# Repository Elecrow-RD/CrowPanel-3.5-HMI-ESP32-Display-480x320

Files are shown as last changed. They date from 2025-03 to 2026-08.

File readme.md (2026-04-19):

### 1, Product picture

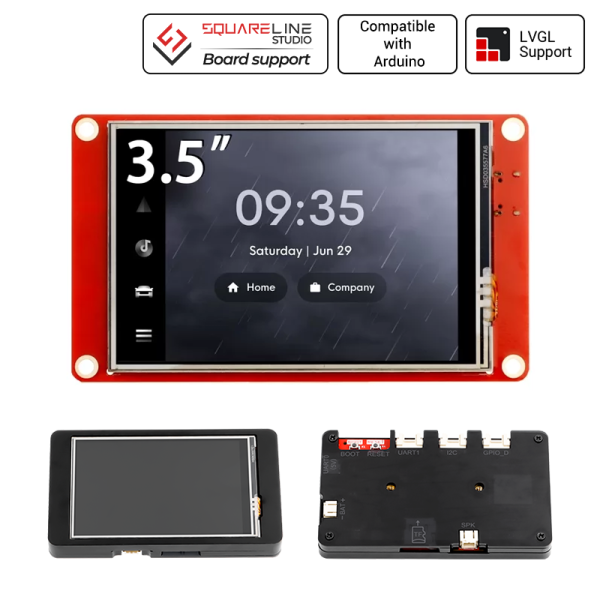
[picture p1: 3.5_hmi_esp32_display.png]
3.5_hmi_esp32_display


### 2, Product version number

| | Hardware | Software | Remark |
| ---- | --- | --- | --- |
| 1 | V1.0 | V1.0 | old |
| 1 | V1.1 | V1.0 | old |
| 1 | V2.0 | V1.0 | old |
| 1 | V2.2 | V2.2 | latest |

**Version 2.0** upgrades the automatic download feature from Version 1.0.

**Version 2.2** modifies two pins based on Version 2.0. The following modifications are required:
#define TFT_MISO 33
#define TOUCH_CS 12

### 3, product informatio

- Model: 3.5 inches module-CrowPanel ESP32 display
- Main Processor: ESP32-WROVER-B
- Resolution: 480*320
- Touch Type: Resistive Touch Screen
- Display Type: TN Panel
- Screen: TFT-LCD Screen
- Display driver: ILI9488
- External power supply: DC5V-2A
- Interface: 1\*TF Card Slot, 1\* I2C, 1* GPIO, 1\*Speak, 1* UART1, 1*UART0
- Button: BOOT Button and Reset Button
- Active Area: 48.96\*73.44mm(W*H)
- Working Temperature: -20℃～70℃
- Storage Temperature: -30℃～80℃

### 4, Use the driver module

| Name | dependency library |
| ---- | --- |
| LVGL | lvgl/lvgl@8.3.3 |

### 5,Quick Start

##### Arduino IDE starts

1.Download the library files used by this product to the 'libraries' folder.

C:\Users\Documents\Arduino\libraries\



2.Open the Arduino IDE

arduino1

3.Open the code configuration environment and burn it

arduino2

##### ESP-IDF starts

1.Right-click on an empty space in the project folder and select "Open with VS Code" to open the project.



2.In the IDF plug-in, select the port, then compile and flash



##### PlatformIO starts

1.Right-click on an empty space in the project folder and select "Open with VS Code" to open the project.



2.In the PlatformIO plug-in, select the port, then compile and flash

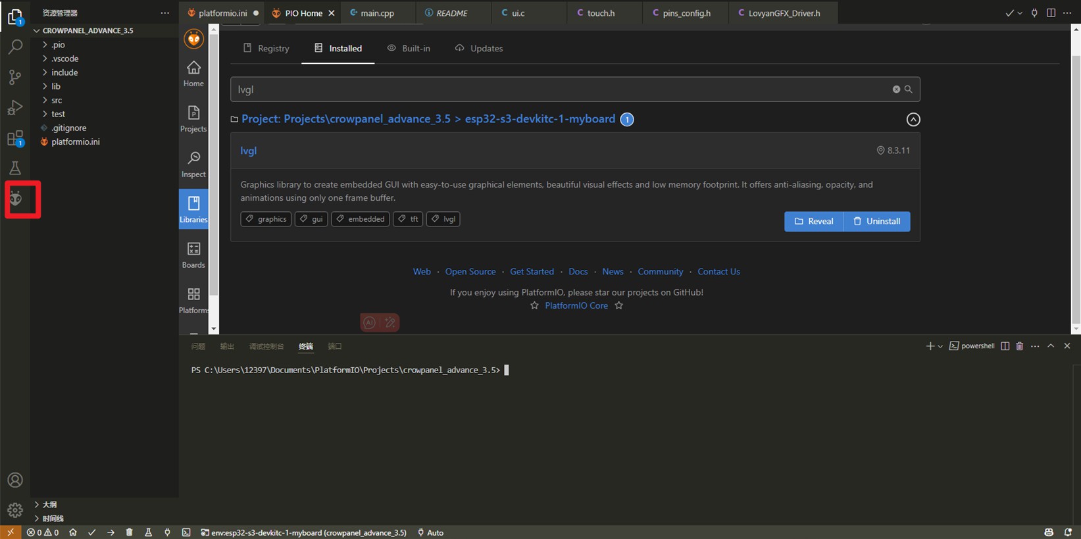
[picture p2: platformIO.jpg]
platformIO


##### Micropython starts

1,Right-click on an empty space in the project folder and select "Thonny" to open the project.

thonny

2,In thonny software, select the master and port, then run the program

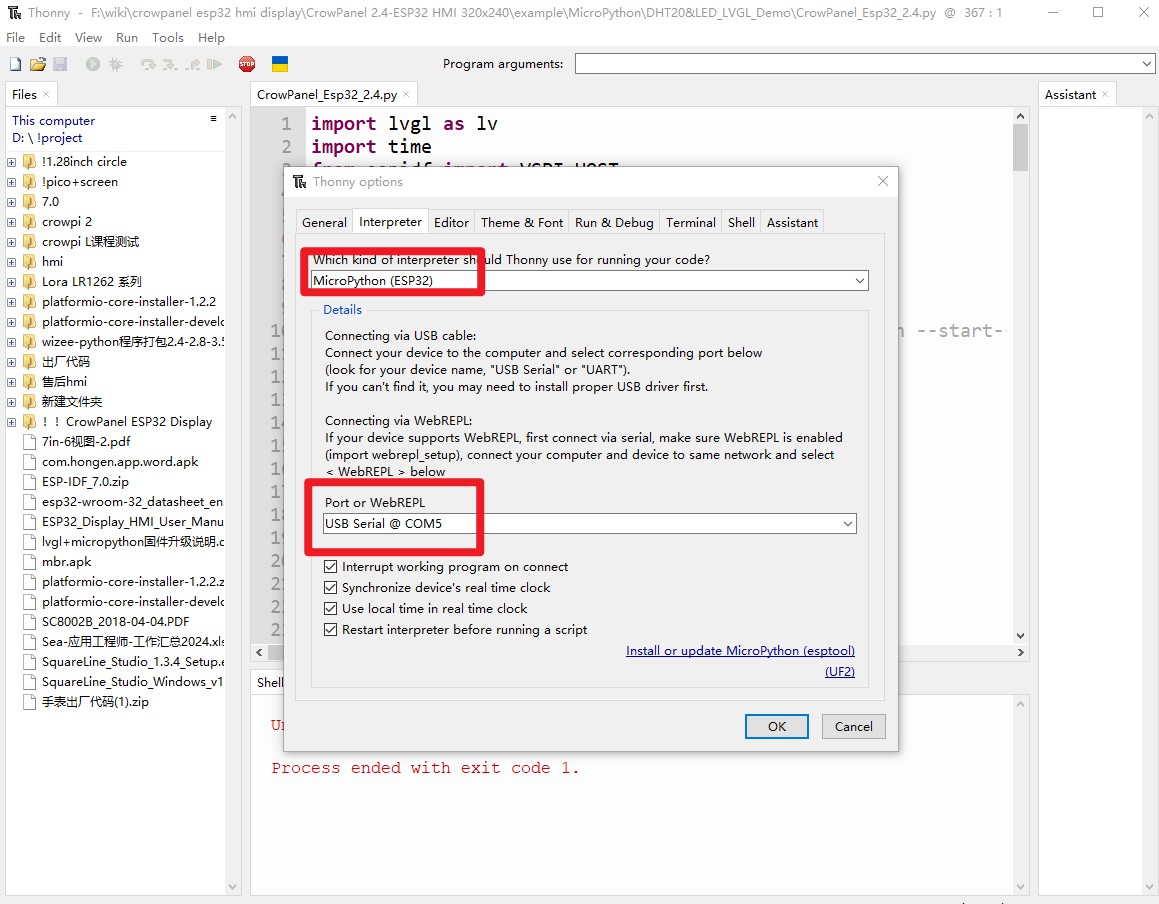
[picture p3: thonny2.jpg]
thonny2


### 6,Folder structure.

|--3D file： Contains 3D model files (.stp) for the hardware. These files can be used for visualization, enclosure design, or integration into CAD software.

|--Datasheet: Includes datasheets for components used in the project, providing detailed specifications, electrical characteristics, and pin configurations.

|--Eagle_SCH&PCB: Contains **Eagle CAD** schematic (`.sch`) and PCB layout (`.brd`) files. These are used for circuit design and PCB manufacturing.

|--example: Provides example code and projects to demonstrate how to use the hardware and libraries. These examples help users get started quickly.

|--factory_firmware: Stores pre-compiled factory firmware that can be directly flashed onto the device. This ensures the device runs the default functionality.

|--factory_sourcecode: Contains the source code for the factory firmware, allowing users to modify and rebuild the firmware as needed.

### 7,Pin definition

\#define TFT_MISO 12 

#define TFT_MOSI 13 // In some display driver board, it might be written as "SDA" and so on. 

#define TFT_SCLK 14 

#define TFT_CS   15  // Chip select control pin 

#define TFT_DC   2  // Data Command control pin 

#define TFT_RST  -1  // Reset pin (could connect to Arduino RESET pin) 

#define TFT_BL   27  // LED back-light 

#define TOUCH_CS 33     // Chip select pin (T_CS) of touch screen

For the latest v2.2 board, the following modifications need to be made:

#define TFT_MISO 33

#define TOUCH_CS 12`

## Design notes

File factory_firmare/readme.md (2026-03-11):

##### Note: For the two firmware files above, if the screen hardware version is 2.2, please use the firmware (LVGL_Arduino3.5RTP-Hor-2.2). For other versions, use (HMI3.5_factory_firmware).

# How to install the factory demo firmware with flash download tool?

#### 1.Preparation:

- USB C cable
- Laptop/PC
- Crowpanel Advance HMI ESP32 AI Display
- Flash download tool

Check whether the materials on the PCBA board are defective. Such as less material, false welding, tin and other bad phenomena.

#### 2.Flash the firmware 

##### Step1 Connect the ESP32 display to the laptop/PC with USB-C cable. The power indicator will light up.

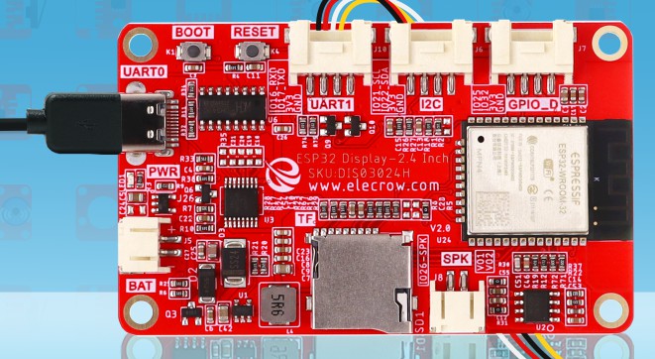
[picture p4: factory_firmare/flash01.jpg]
flash01


##### Step2 Open the flash download tool. 

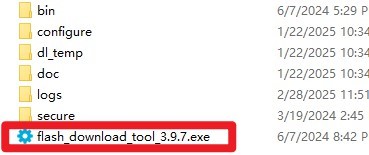
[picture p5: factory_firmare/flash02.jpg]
flash02


For the  Crowpanel 3.5 HMI ESP32 Display, the chip select ESP32:

firmware1

##### Step3

①Choose the firmware files;

flash0

②Enter the address: 

boot_app0.bin------0xe000

xxxx.ino.bin--------0x10000

xxxx.ino.bootloader.bin------0x1000

xxxx.ino.partitions.bin-------0x8000

③Check the firmware files;

④Select the correct port number;

⑤Click “Start” to download

firmware2

### Note: If it is v1.0 version, before downloading firmware or program, you need to press the boot button, then short press the reset button, and then release the boot button to enter the burn mode. If it is v2.0 or above, this step is not needed, it will automatically enter into burn mode.

##### Step5 After the download is complete, blue FINISH will be displayed, and the progress bar at the bottom shows that it has come to an end.

firmware3

##### Step6 Press the reset button to show the demo.

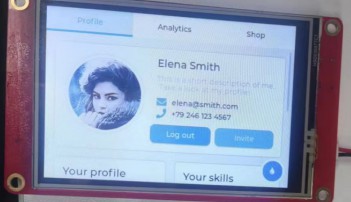
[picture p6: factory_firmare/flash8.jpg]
flash8


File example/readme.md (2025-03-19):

**Arduino**: This folder contains sample programs for the Arduino platform, which is known for its ease of use and versatility in creating interactive electronic projects.

#### NOTE!!!:When running this program , you need to download the officially provided libraries and place them in the libraries of arduino. esp32 version needs to be 2.0.14/2.0.15. the version of the libraries is the same as the officially provided version.

Link to the corresponding course wiki:https://www.elecrow.com/wiki/ESP32_Display_3.5-inch_HMI_Arduino_Tutorial.html

Video Tutorial Links：https://www.youtube.com/watch?v=x4LrIeEJTls&t=2s

**ESP_IDF**: This directory holds example code for the Espressif IoT Development Framework (ESP-IDF), designed for developing applications on ESP32 and ESP8266 microcontrollers.

Link to the corresponding course wiki:https://www.elecrow.com/wiki/CrowPanel-ESP32-3.5-inch-with-ESP-IDF.html

**Esphome**: Here you'll find sample programs for Esphome, a firmware framework that simplifies the process of creating smart home devices using ESP8266/ESP32 chips.

Link to the corresponding course wiki:https://www.elecrow.com/wiki/CrowPanel_ESP32_3.5-inch_with_ESPHome.html

**MicroPython**: This section includes examples for MicroPython, a lean and efficient implementation of the Python programming language that can run on microcontrollers.

Link to the corresponding course wiki:https://www.elecrow.com/wiki/ESP32_Display_3.5-inch_HMI_MicroPython_Tutorial.html

**PlatformIO**: This folder contains sample projects for PlatformIO, an open-source ecosystem that streamlines the development process across various embedded platforms by providing a consistent environment for coding, compiling, and uploading firmware.:

Link to the corresponding course wiki:https://www.elecrow.com/wiki/CrowPanel_ESP32_3.5-inch_with_PlatformIO.html

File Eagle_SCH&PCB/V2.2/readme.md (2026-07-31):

# CrowPanel ESP32 Display 3.5 V2.2 Product Hardware Driver Notes

| Item | Content |
|---|---|
| Document Version | V1.0 |
| Document Date | 2026-07-29 |
| Author | Codex (compiled from cross-referencing project materials) |
| Applicable Hardware | CrowPanel ESP32 Display 3.5, schematic/PCB V2.2 (2024-07-04) |
| Software Baseline | Board-level examples in `Arduino/Course` and accompanying libraries in the repository |
| Determination Principle | Working code takes priority; schematics used for electrical connection review; devices without code evidence are described only for their hardware function, with no speculation on driver parameters |

## 1. Document Purpose and Evidence Boundaries

This document is intended for hardware maintenance, Arduino driver porting, and onboarding of new team members. Cross-validation uses the following primary sources:

1. `V2.2/CrowPanel ESP32 Display-3.5-V2.2-20240704.sch`: Eagle schematic source file, the primary basis for nets and device connections.
2. `V2.2/CrowPanel ESP32 Display-3.5-V2.2-20240704.brd`: PCB layout source file, used to confirm this material set corresponds to V2.2.
3. `V2.2/CrowPanel ESP32 Display-3.5-V2.2-20240704.pdf`: Released schematic.
4. `Arduino/Course/Example1...Example8`, `LVGL_Arduino3.5`: Board-verified examples, serving as the highest-priority evidence for pin assignments and runtime parameters.
5. `Arduino/libraries/TFT_eSPI/User_Setup.h`: The actual compiled configuration for LCD, touch, and backlight.

"Verified" in this document means the repository delivers the code as a usable Course example; this work did not connect physical hardware and re-flash. Third-party libraries' own examples are not considered evidence of on-board devices. OLED, GPS, and DHT20 are peripherals connected through expansion interfaces, not on-board chips in the schematic.

## 2. Software Stack and Overall Architecture

- MCU: ESP32-WROVER-B module (schematic reference designator U24; the device library name still carries `ESP32-WROOM-32-N4`, identified by combining value and wireless/PSRAM requirements).
- Application framework: Arduino-ESP32; the lower layer is provided by the ESP-IDF HAL/drivers for GPIO, SPI, I2C, UART, DAC, Wi-Fi, and BLE.
- GUI: LVGL 9.1.0 → TFT_eSPI 2.5.43 → Arduino-ESP32 SPI/GPIO.
- File system: Arduino SD 1.3.0 → FS/SPI.
- External OLED: U8g2 2.36.19, example uses software I2C.
- Touch: The actual example uses TFT_eSPI's built-in XPT2046 support; the repository also includes XPT2046_Touchscreen 1.4, but the board-level example does not directly use it.

## 3. Peripheral Overview

| Category | Peripheral / Ref Designator | Interface and Main Pins | Code Status | Remarks |
|---|---|---|---|---|
| Main Control | ESP32-WROVER-B / U24 | 3.3 V; GPIO Matrix | In use | Wi-Fi, BLE, DAC, SPI, UART, I2C all provided by it |
| Display | 3.5-inch 480×320 TFT / J1, TFT-18PIN1 | SPI: 14/13/33, CS15, DC2 | Verified | Code selects ILI9488, rotation 1 |
| Touch | XPT2046/XP2046 / U3 | SPI: CLK14, DIN13, DOUT33, CS12; IRQ36 | Verified polling | Schematic net names have mislabeled CS/DOUT |
| Backlight | Q6 + LEDK | GPIO27, active high | Verified, turns on with `lcd.begin()` | N-MOS low-side control, PWM can be added |
| TF/microSD | SD1 | SPI: SCK18, MOSI23, MISO19, CS5 | Verified | Independent of TFT/touch pin group |
| Audio | SC8002B / U2, speaker connector J8 | GPIO26/DAC2 → amplifier | Verified | 8-bit DAC lookup-table sine wave |
| USB-to-Serial | USB-C J3 + CH340G U6 | UART0: TX1, RX3; DTR/RTS auto-download | Hardware-fixed | USB only via CH340G, not native ESP32 USB |
| Buttons | K1 BOOT, K4 RESET | GPIO0→GND; EN→GND | Hardware-fixed | Boot strap/reset, not recommended for use as ordinary pushbuttons |
| Indicator | LED1 | 3.3 V → R3 → LED1 → GND | Hardware-fixed | Power LED; not connected to GPIO25 of Example1 |
| Expansion I2C | J6 | SCL21, SDA22, 3.3 V, GND | OLED/DHT20 verified | Schematic contains series/pull-up network |
| Expansion Analog/Digital | J7 | GPIO25, GPIO32, 3.3 V, GND | GPIO25 example verified | GPIO32 can be ADC1_CH4/Touch9 |
| Expansion UART | J10 | RX3, TX1, 3.3 V, GND | GPS example verified | Conflicts with download/log UART |
| Wireless | ESP32 2.4 GHz Wi-Fi + BLE | Module internal RF | Verified | Does not occupy external GPIO |
| Power Input | USB-C VBUS, Li-ion battery J5 | VBUS/BAT+ → VIN → 3.3 V | Hardware-fixed | Includes power OR-ing/backflow protection |
| Charging | 4054A / U26 | VBUS→BAT+, PROG=2 kΩ | No software driver | Linear single-cell Li-ion charger |
| 3.3 V Regulator | HM3420B / U1 + L4 | VIN→3V3 | No software driver | Switching regulator, EN pulled up by hardware |

## 4. GPIO/Bus Authoritative Mapping

| GPIO | Code Definition | Schematic Electrical Connection | Direction / Alternate Function | Notes |
|---:|---|---|---|---|
| 0 | BOOT | K1, auto-download Q10 | Boot strap input | Pulled low during download; do not add heavy load |
| 1 | UART0 TX; GPS_TX | U24 TXD0, J10-2, CH340 RXD | UART output | GPS example shares with log/download |
| 2 | TFT_DC | LCD D/C | SPI control output | ESP32 boot strap pin, peripherals must not force a wrong level |
| 3 | UART0 RX; GPS_RX | U24 RXD0, J10-1, CH340 TXD | UART input | GPS may drive simultaneously with CH340, bus contention risk |
| 5 | SD_CS | microSD DAT3/CS | SPI chip-select output | Note strap level at boot |
| 12 | TOUCH_CS | XPT2046 CS | SPI chip-select output | Schematic net name mislabeled as TFT_SDO/TP_OUT; also MTDI boot strap pin |
| 13 | TFT_MOSI, touch DIN | LCD SDA, XPT2046 DIN | HSPI MOSI output | TFT and touch shared |
| 14 | TFT_SCLK, touch DCLK | LCD SCL, XPT2046 DCLK | HSPI SCK output | TFT and touch shared |
| 15 | TFT_CS | LCD CS | SPI chip-select output | Boot strap pin |
| 18 | SD_SCK | microSD CLK | VSPI SCK output | SD dedicated bus group |
| 19 | SD_MISO | microSD DAT0 | VSPI MISO input | SD dedicated bus group |
| 21 | I2C_SCL | J6-1, via R26 | I2C clock / open-drain | Example OLED uses software I2C; DHT20 uses hardware Wire |
| 22 | I2C_SDA | J6-2, via R27 | I2C data / open-drain | 3.3 V logic |
| 23 | SD_MOSI | microSD CMD | VSPI MOSI output | SD dedicated bus group |
| 25 | `D_PIN` | J7-1, via R18; DAC1/ADC2_CH8 | Example is push-pull output | Not connected to schematic LED1 |
| 26 | SPEAKER/DAC2 | SC8002B input network | 8-bit DAC analog output | Should not be configured as an ordinary digital output to play audio |
| 27 | TFT_BL | Q6 gate, pull-down via R38 | Active-high output / PWM optional | High level turns on |
| 32 | Expansion A/D | J7-2, via R25 | ADC1_CH4 / digital IO | ADC1 usable alongside Wi-Fi |
| 33 | TFT_MISO, touch DOUT | XPT2046 DOUT; LCD MISO as defined in code | SPI input | Schematic net name mislabeled as TP_CS |
| 34 | Expansion pad | U24 GPIO34 | ADC1_CH6, input only | No internal pull-up/down |
| 35 | Expansion pad | U24 GPIO35 | ADC1_CH7, input only | No internal pull-up/down |
| 36 | TP_IRQ | XPT2046 PENIRQ, pull-up via R10 | Input only / ADC1_CH0 | Code currently polls, no interrupt registered |
| 39 | Expansion pad | U24 GPIO39 | ADC1_CH3, input only | No internal pull-up/down |

## 5. Detailed Driver Description

### 5.1 ESP32 MCU, Wi-Fi and BLE

Wi-Fi and BLE are both internal ESP32 module peripherals, with no external control pins. The Wi-Fi example calls `WiFi.begin()`, enables auto-reconnect, and blocks waiting for `WL_CONNECTED`; the target network must be a 2.4 GHz network supported by ESP32. The SSID/password in the example are demo values; for mass production they should be moved to secure configuration storage, and hardcoding real credentials is prohibited.

The BLE example establishes a GATT Server: device name `ESP32SPI-BLE`, Service UUID `6479571c-2e6d-4b34-abe9-c35116712345`, Characteristic UUID `826f072d-f87c-4ae6-a416-6ffdcaa02d73`, properties READ/WRITE/NOTIFY, initial value `ELECROW`. It depends on the Arduino-ESP32 BLEDevice/BLEServer software layer.

```cpp
WiFi.begin(ssid, password);
WiFi.setAutoReconnect(true);

BLEDevice::init("ESP32SPI-BLE");
BLEService *svc = BLEDevice::createServer()->createService(SERVICE_UUID);
```

### 5.2 TFT LCD (ILI9488)

The actual compiled configuration is in `TFT_eSPI/User_Setup.h`: ILI9488, 320×480 portrait native resolution; examples uniformly use `setRotation(1)` to obtain 480×320 landscape coordinates. The interface is hardware SPI: MOSI=13, MISO=33, SCLK=14, CS=15, DC=2; RESET=-1, meaning TFT RESET is hardware-linked to the board-level EN_RESET and is not independently controlled by a GPIO. Write clock 15,999,999 Hz, read clock 20 MHz.

```cpp
#define ILI9488_DRIVER
#define TFT_MISO 33
#define TFT_MOSI 13
#define TFT_SCLK 14
#define TFT_CS   15
#define TFT_DC    2
#define TFT_RST  -1
#define SPI_FREQUENCY 15999999

TFT_eSPI lcd;
lcd.begin();
lcd.setRotation(1);
```

The initialization order should be: establish serial (optional) → `lcd.begin()` → clear screen → set touch calibration → set rotation/GUI. The current LVGL example calls `setRotation(1)` after `setTouch()`; when porting, the calibration array must match the final rotation and cannot be reused directly across orientations.

ILI9488's SDO is typically unreliably tri-stated; this board's display and touch share SPI lines and must rely on correct chip select, and must not be directly paralleled onto the SD's separate SPI pin group. If touch readings are abnormal, first use an oscilloscope to check whether GPIO33 is driven by the LCD when TFT CS is pulled high.

### 5.3 Resistive Touch and XPT2046

U3 is marked XP2046, and the software uses it as an XPT2046-compatible controller. It shares SCLK=14, MOSI/DIN=13, MISO/DOUT=33 with the TFT, with an independent CS=12; PENIRQ=GPIO36. TFT_eSPI configures the touch SPI at 600 kHz. The current code calls `getTouch(..., 600)` polling; the value 600 is a pressure threshold, not an interrupt trigger parameter; the GPIO36 IRQ is not currently used.

```cpp
#define TOUCH_CS 12
#define SPI_TOUCH_FREQUENCY 600000
uint16_t calData[5] = {557, 3263, 369, 3493, 3};
lcd.setRotation(1);
lcd.setTouch(calData);
bool pressed = lcd.getTouch(&x, &y, 600);
```

For a new screen, a different batch, or after changing rotation, run `lcd.calibrateTouch(calData, TFT_MAGENTA, TFT_BLACK, 15)` to save the new five-tuple. If switching to interrupt mode, GPIO36 is input-only with no internal pull-up/down; on-board R10 pulls PENIRQ up to 3.3 V, typically active on the falling edge or low level; before formal implementation it should still be confirmed against the controller datasheet and actual measurements.

### 5.4 Backlight

GPIO27 drives the 2N7002 Q6 via R38; Q6's low-side switch controls LEDK, so the code defines `TFT_BACKLIGHT_ON HIGH`. `lcd.begin()` sets it high. For dimming, Arduino LEDC PWM can be used, but avoid frequencies too low that cause visible flicker; the project does not provide a verified PWM frequency, so it is recommended to validate EMI, brightness, and temperature rise starting from 10–20 kHz.

### 5.5 microSD/TF Card

The SD card uses a separate hardware SPI: SCK18, MISO19, MOSI23, CS5. Initialization first calls `SPI.begin(18,19,23)`, delays 100 ms, then `SD.begin(5)`; the example serial is 9600 baud, and after a successful mount it reads the card type, capacity, and recursively lists directories two levels deep. `SD.begin()` passes no frequency and uses the library/Arduino core default; do not infer an unverified frequency beyond what the documentation shows.

```cpp
SPI.begin(18, 19, 23);
delay(100);
if (!SD.begin(5)) { /* mount failed */ }
```

The card socket operates at 3.3 V, with DAT/CMD having board-level pull-ups. Hot-plugging, write power-loss protection, and maximum capacity/filesystem type are not verified in the project; after porting, a FAT32/capacity matrix and write power-loss tests need to be added.

### 5.6 Audio DAC and SC8002B Amplifier

GPIO26 is ESP32 DAC_CHANNEL_2, fed through an input network to the SC8002B mono amplifier; J8 is the differential speaker output VO1/VO2. The example enables the 8-bit DAC and outputs via a 256-point sine table: sample rate = `frequency × 256`; a 1 kHz tone has a theoretical sample rate of 256 ksample/s, uses point-by-point `delayMicroseconds()`, plays for 1 s then returns to the midpoint 128, and pauses for 2 s.

```cpp
dac_output_enable(DAC_CHANNEL_2);
dac_output_voltage(DAC_CHANNEL_2, sineWave[i & 0xFF]);
```

It depends on ESP-IDF `driver/dac.h`, not Arduino PWM. SC8002B's SHUTDOWN is connected to AGND in the schematic and cannot be turned off by software. J8 is a bridged/differential output; neither end is ground. Do not connect either speaker end to GND, nor directly to a single-ended active speaker input.

### 5.7 I2C Expansion, OLED and DHT20

J6: 1=SCL/GPIO21, 2=SDA/GPIO22, 3=3.3 V, 4=GND. The schematic net names match the code variable order.

The OLED example is an external SSD1306 128×64 with no independent RESET, using the U8g2 software I2C constructor; the clock is not explicitly specified, and the rate is determined by the U8g2 software implementation:

```cpp
U8G2_SSD1306_128X64_NONAME_F_SW_I2C u8g2(
    U8G2_R0, /* clock */ 21, /* data */ 22, U8X8_PIN_NONE);
u8g2.begin();
```

The DHT20 in the LVGL example uses hardware Wire: `Wire.begin(22, 21); dht20.begin();`. The Arduino API parameter order is SDA, SCL, so it is still SDA22/SCL21. The DHT20 library works at the device standard address, but the board-level code does not explicitly write the address; the maintenance documentation does not treat the inferred address as a verified parameter. Before paralleling multiple I2C modules, account for the equivalent pull-up resistance and address conflicts; all signals must be 3.3 V only.

### 5.8 GPIO25 Example and Expansion Port J7

Course Example1 configures GPIO25 as a push-pull output, toggling every 500 ms. The schematic shows J7: 1=GPIO25, 2=GPIO32, 3=3.3 V, 4=GND; therefore this example can drive an external LED/load connected to J7-1.

```cpp
pinMode(25, OUTPUT);
digitalWrite(25, HIGH);
delay(500);
digitalWrite(25, LOW);
```

The schematic LED1 is a 3.3 V power LED and cannot be controlled by GPIO25. A GPIO push-pull can only drive small-current loads; external LEDs must have a current-limiting resistor in series, and relays/motors etc. must add transistors/MOSFETs and flyback protection.

### 5.9 UART0, GPS, CH340G and Auto-Download

J10: 1=GPIO3/RX0, 2=GPIO1/TX0, 3=3.3 V, 4=GND. The GPS example maps the UART2 peripheral to the same physical pins, using 9600 baud, 8N1:

```cpp
HardwareSerial gpsSerial(2);
gpsSerial.begin(9600, SERIAL_8N1, /* RX */ 3, /* TX */ 1);
```

It receives NMEA, verifies the XOR checksum, parses GGA/RMC/VTG, and displays them on the TFT. GPIO1/3 are also hard-wired to the CH340G, and `Serial` by default also uses UART0; the example simultaneously does `Serial.begin(115200)` and GPS at 9600, causing different purposes/baud rates on the same pin group. Although Arduino declares `gpsSerial` as UART2, the GPIO Matrix still maps UART2 to GPIO1/3, electrically conflicting with UART0/CH340. When deploying GPS, disconnect/isolate the CH340 path or use other available GPIO, and re-verify; do not connect the GPS module's 5 V UART directly to a 3.3 V RX.

The CH340G's DTR/RTS connect to EN/IO0 via Q9/Q10, implementing Arduino auto-reset and download. K1 manually pulls GPIO0 low, and K4 manually pulls EN low.

### 5.10 Power, Charging and Protection

- USB-C J3 provides VBUS and USB D+/D−; D+/D− connect only to the CH340G.
- U26 (4054A) is a single-cell Li-ion linear charger, VBUS input, BAT to J5 BAT+, PROG resistor R5=2 kΩ. The actual charging current depends on the specific 4054A model formula and device tolerance; the schematic does not provide sufficient evidence, so no definite value is claimed here.
- Q3 (P-MOS) and D5 (1N5817) form the USB/battery power-selection and reverse-isolation path, converging to VIN.
- U1 (HM3420B) and L4 convert VIN to 3.3 V; EN shares the net with VIN, enabled on power-up, with no software control.
- SC8002B additionally uses an audio power domain labeled 3.3V/AGND; the digital 3V3 and 3.3V names differ, and the layout/reflow design must not be arbitrarily shorted together.

Use only a single-cell Li-ion battery, and connect to J5 after confirming polarity. Pay attention to linear charger temperature rise during charging; USB supply capability, screen backlight, amplifier peak, and external module current must be budgeted together. The expansion port 3.3 V is not a 5 V-tolerant supply.

## 6. Schematic—Code Discrepancies and Rulings

| ID | Schematic / Label | Working Code | Ruling and Reason |
|---|---|---|---|
| D01 | Net `IO33_TP_CS` actually connects to U3 DOUT; net `IO12_TFT_SDO/TP_OUT` actually connects to U3 CS | `TFT_MISO=33`, `TOUCH_CS=12` | Use code and pinref electrical connection as the basis: GPIO33=DOUT/MISO, GPIO12=CS. |
| D02 | U3 device name written as `XP2046` | TFT_eSPI drives touch as XPT2046-compatible | Compatible usage; handle per the XPT2046 SPI protocol when porting, and check the BOM/physical silkscreen for the procurement part number separately |
| D03 | LED1 fixed to 3V3, via R3 to ground | Example1 comment says GPIO25 drives onboard indicator | Driver definition still follows code GPIO25, but it only reaches J7-1; the "onboard indicator" comment is inconsistent with the V2.2 schematic, possibly the example carried over from another hardware revision or a comment error |
| D04 | LCD RESET hardware-linked to EN_RESET | `TFT_RST=-1` | Consistent; do not port to template defaults such as GPIO4 |
| D05 | Touch PENIRQ to GPIO36 | Example only uses `getTouch()` polling | Code prevails, interrupt not used currently; GPIO36 reserved for future optimization |
| D06 | J10 connects UART0 GPIO1/3 and CH340 | GPS uses UART2 mapped to GPIO1/3, and simultaneously enables Serial/UART0 | Pin definitions recorded by code, but a real contention risk exists; production design should change pins or isolate, and cannot be treated as concurrently usable |
| D07 | MCU symbol deviceset name contains WROOM-32-N4, value is ESP32-WROVER-B | Examples/GUI resources imply a WROVER-class config with PSRAM | Material identification follows value/physical/BOM; board target and PSRAM option must be confirmed on actual hardware |

## 7. Risks and Notes

1. **Boot strap pins**: GPIO0, 2, 5, 12, 15 are sensitive during reset sampling. External devices must not force a wrong level at startup, especially GPIO12, which may affect flash voltage configuration.
2.
 **UART hardware conflict**: GPIO1/3 are simultaneously connected to CH340, J10, and UART0, while the GPS example also maps to UART2; this is the highest-priority remediation item.

3. **ILI9488 MISO tri-state risk**: The touch DOUT and possibly the LCD SDO share GPIO33. When bus contention occurs, consider disconnecting the LCD SDO or adjusting the hardware, rather than merely masking the issue by lowering the frequency.

4. **Voltage**: ESP32 GPIO, SD, touch, and I2C expansion all operate at 3.3 V; any 5 V signal must be level-shifted.

5. **Input-only GPIO**: Pins 34/35/36/39 cannot output and have no internal pull-up; interrupt inputs must rely on a defined external bias.

6. **ADC/Wi-Fi**: ADC2 channels such as GPIO25/4 may become unavailable while Wi-Fi is active; prefer the ADC1 channels on GPIO32/34/35/36/39.

7. **GPIO drive capability**: Extended pins such as GPIO25 are suitable only for logic/low-current use and must not directly drive speakers, motors, relays, or high-power LEDs.

8. **Amplifier output**: J8 is a BTL differential output; grounding either terminal may damage the amplifier.

9. **Battery safety**: Connect only a matched single-cell Li-ion battery; the schematic shows a charger but provides no proof of cell protection, so prefer cells with a protection board.

10. **Shared bus concurrency**: LVGL refresh and touch reads are managed as transactions by TFT_eSPI; when adding new tasks or concurrent RTOS access, mutual exclusion must be applied to avoid switching the chip select while a DMA/flush operation is still in progress.

11. **Calibration data**: The touch calibration array is tied to screen orientation, panel, and mechanical assembly, and cannot serve as a universal constant across all production batches.

12. **Library configuration location**: TFT pins are defined inside the library's `User_Setup.h`, which is easily overwritten when upgrading or replacing the library; it is recommended to later migrate to a standalone board-level setup file selected via `User_Setup_Select.h`.

## 8. Porting and Power-On Verification Checklist

1. Verify the physical PCB silkscreen revision is V2.2 and record the silkscreen of the ESP32 module and the LCD/touch chips.

2. In Arduino-ESP32, select the board type matching WROVER/PSRAM, then first verify download, reset, and serial log output.

3. With no load, measure VBUS, BAT+, VIN, and 3V3; only connect expansion modules after confirming that 3V3 is stable.

4. Run LCD, backlight, touch, SD, audio, I2C, Wi-Fi, and BLE in sequence; do not combine all tasks from the start.

5. For the LCD, use ILI9488 with SPI write ≈ 16 MHz; verify solid colors, orientation, color order, and long-duration refresh.

6. For touch, use CLK14/DIN13/DOUT33/CS12 at 600 kHz, re-calibrate, and test the four corners, dragging, and long-press.

7. For SD, use 18/19/23/5; cover no-card, hot-plug, different capacities, directories, and power-loss writes.

8. For audio, first connect a speaker of suitable impedance across the two terminals of J8, test at low volume and short duration, and monitor the SC8002B temperature rise.

9. Before I2C scanning, confirm 3.3 V and pull-ups; verify the OLED/DHT20 both individually and in parallel.

10. Do not drive GPIO1/3 concurrently with CH340/UART0 for GPS; if debugging is unavoidable, switch to other serial pins or use hardware isolation.

11. During Wi-Fi/BLE stress runs, re-test ADC, SD, GUI refresh, and power-supply ripple.

12. Backfill the final Arduino core version, compiled board type, Flash/PSRAM settings, library versions, touch calibration values, and measured current into the release record.

## 9. Items Pending Supplement / On-Site Testing

- Per-example test records from re-flashing the physical unit, the Arduino-ESP32 core version, and the compile menu options.

- Confirmation of the LCD panel controller and XPT2046 physical silkscreen / procurement part numbers.

- 4054A actual charge current, termination voltage, thermal testing, and battery protection scheme.

- HM3420B output capability, ripple, USB/battery switching transients, and overall peak power consumption.

- SD card capacity / file-system compatibility matrix.

- Actual accessibility and recommended uses of the GPIO34/35/39 pads or test points.

- Hardware remediation or an official software pin scheme for the GPS UART conflict.

Until the above items are completed, this document may serve as a driver-porting baseline but should not replace the mass-production hardware verification report.

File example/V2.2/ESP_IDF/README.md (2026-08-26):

# CrowPanel ESP32 3.5-inch LVGL 环境监控面板

这是一个基于 ESP-IDF、Arduino-ESP32、LVGL 和 TFT_eSPI 的 CrowPanel ESP32 3.5 英寸示例项目。界面显示 DHT20 温湿度，并可通过触摸按钮控制 GPIO25。

## 硬件

- Elecrow CrowPanel ESP32 3.5-inch HMI，480×320
- ESP32-WROVER / 8 MB PSRAM
- ILI9488 SPI LCD
- XPT2046 电阻触摸屏
- DHT20 温湿度传感器

本仓库默认配置适用于 CrowPanel 3.5-inch **硬件 v2.2**：

| 功能 | GPIO |
| --- | ---: |
| TFT MISO | 33 |
| TFT MOSI | 13 |
| TFT SCLK | 14 |
| TFT CS | 15 |
| TFT DC | 2 |
| TFT Backlight | 27 |
| Touch CS | 12 |
| I²C SDA | 22 |
| I²C SCL | 21 |
| UI 控制输出 | 25 |

旧版 CrowPanel 的 TFT MISO 和 Touch CS 与 v2.2 对调，请根据 Elecrow 官方资料修改 `sdkconfig.defaults`。

## 开发环境

- ESP-IDF 5.5.4
- `espressif/arduino-esp32` 3.3.8（由 Component Manager 自动下载）
- 4 MB 或更大 Flash

首次构建时 ESP-IDF 会根据 `main/idf_component.yml` 和 `dependencies.lock` 下载托管依赖，因此需要网络连接。

## 构建与烧录

先打开已初始化 ESP-IDF 5.5.4 环境的终端，然后执行：

```bash
idf.py set-target esp32
idf.py build
idf.py -p COM40 flash monitor
```

Linux/macOS 请将 `COM40` 换成实际串口，例如 `/dev/ttyUSB0`。退出串口监视器使用 `Ctrl+]`。

## 目录

- `main/`：应用入口、DHT20 读取、LVGL 显示和触摸逻辑
- `components/ui/`：SquareLine Studio 生成的界面及图片资源
- `components/DHT20/`：DHT20 驱动
- `components/TFT_eSPI/`：适配 ESP-IDF 的 TFT_eSPI
- `components/lvgl-3/`：LVGL 核心源码
- `sdkconfig.defaults`：CrowPanel v2.2 的可复现默认配置

`build/`、`managed_components/` 和本机 IDE 设置不会提交，均可在构建时重新生成。

## 第三方许可证

LVGL 和 TFT_eSPI 的原始许可证保留在各自组件目录中。项目应用代码使用根目录中的 MIT License。

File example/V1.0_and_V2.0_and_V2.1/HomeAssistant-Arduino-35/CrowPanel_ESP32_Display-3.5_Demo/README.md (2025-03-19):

**If you are using this demo code for the first time, I suggest that you watch this video lesson first.**

video link:

[Create and Export Stunning UI with SquareLine Studio for ESP32 Display | LVGL Tutorial - YouTube](https://www.youtube.com/watch?v=Ls0uLyeAgiw)

---

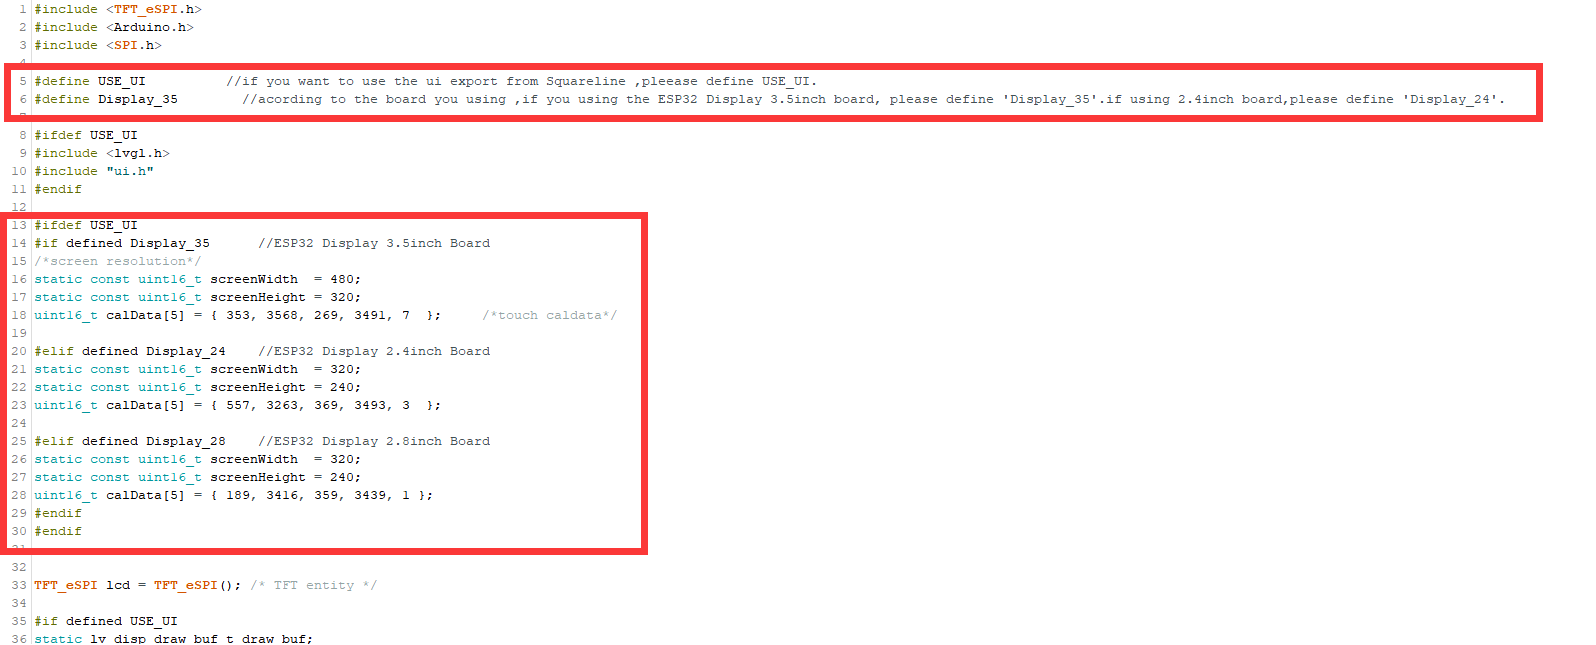
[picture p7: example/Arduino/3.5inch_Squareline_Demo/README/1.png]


Please notice the tips inside the demo code,that is very important.

**If you don't want to use the UI export from Squareline Studio ,please del the UI file, and open the demo program again, then you can compile the program, or your program may happen some errors.**

---

And make sure that the 'User_Setup.h' file of the TFT_eSPI library is already correctly configured.

Or you can find the 'User_Setup.h' file from the 'User_Setup' floder.

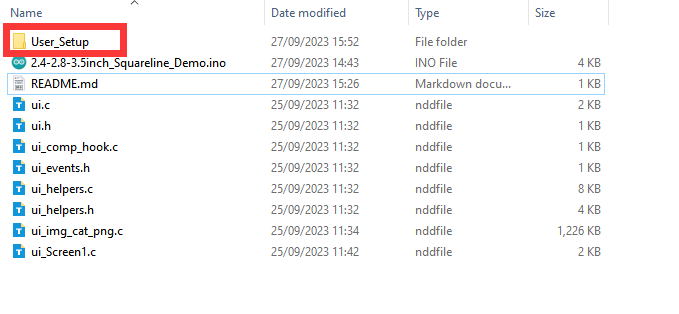
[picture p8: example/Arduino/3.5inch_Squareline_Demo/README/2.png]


You need to copy the 'User_Setup.h' file according the board you're using to the TFT_eSPI library directory, and then, rename it to 'User_Setup.h'

If you already have a 'User_Setup.h' file in the TFT_eSPI library directory, replace it.

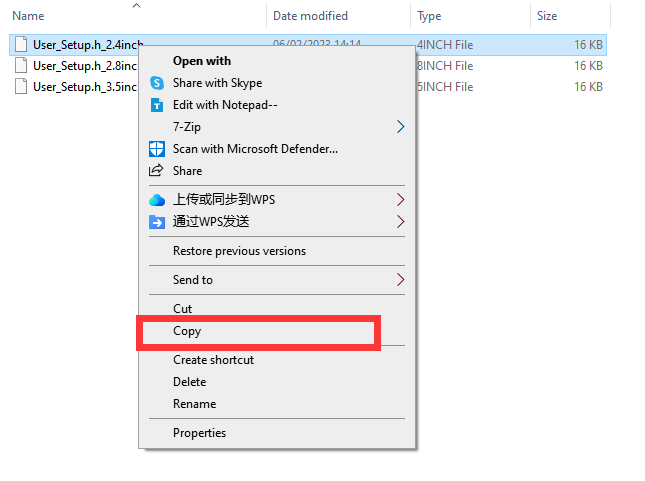
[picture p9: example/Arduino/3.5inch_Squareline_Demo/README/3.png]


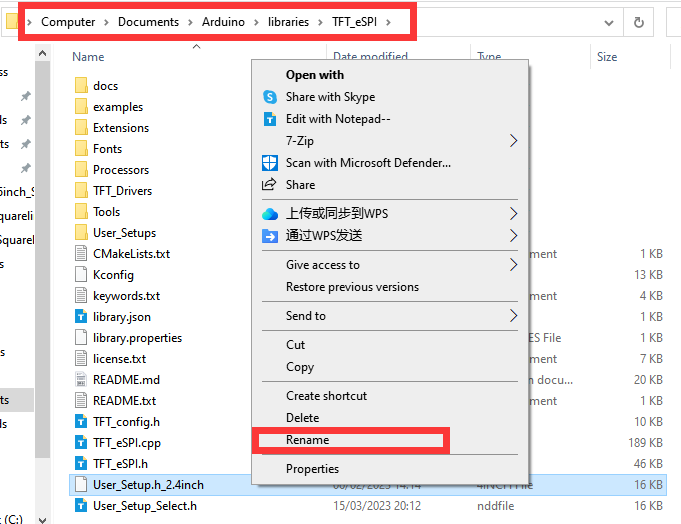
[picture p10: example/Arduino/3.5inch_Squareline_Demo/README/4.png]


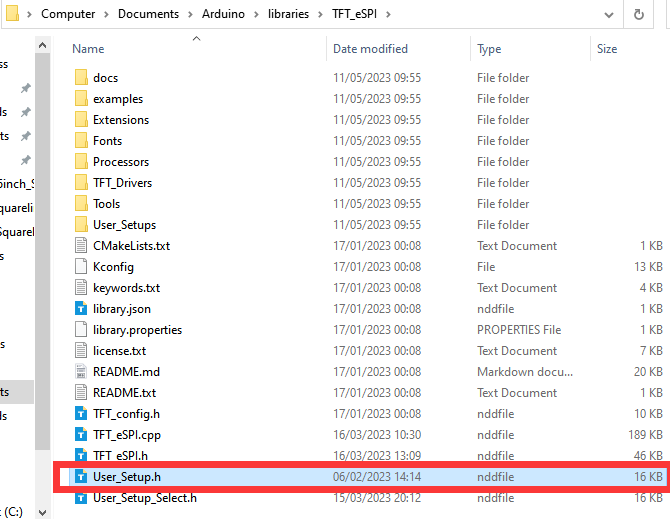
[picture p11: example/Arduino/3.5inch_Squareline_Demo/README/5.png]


-------------------------------------------------------------END----------------------------------------------------------

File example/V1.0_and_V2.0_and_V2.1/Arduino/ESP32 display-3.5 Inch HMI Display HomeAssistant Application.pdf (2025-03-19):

# Home Assistant Raspberry Pi Server Configuration

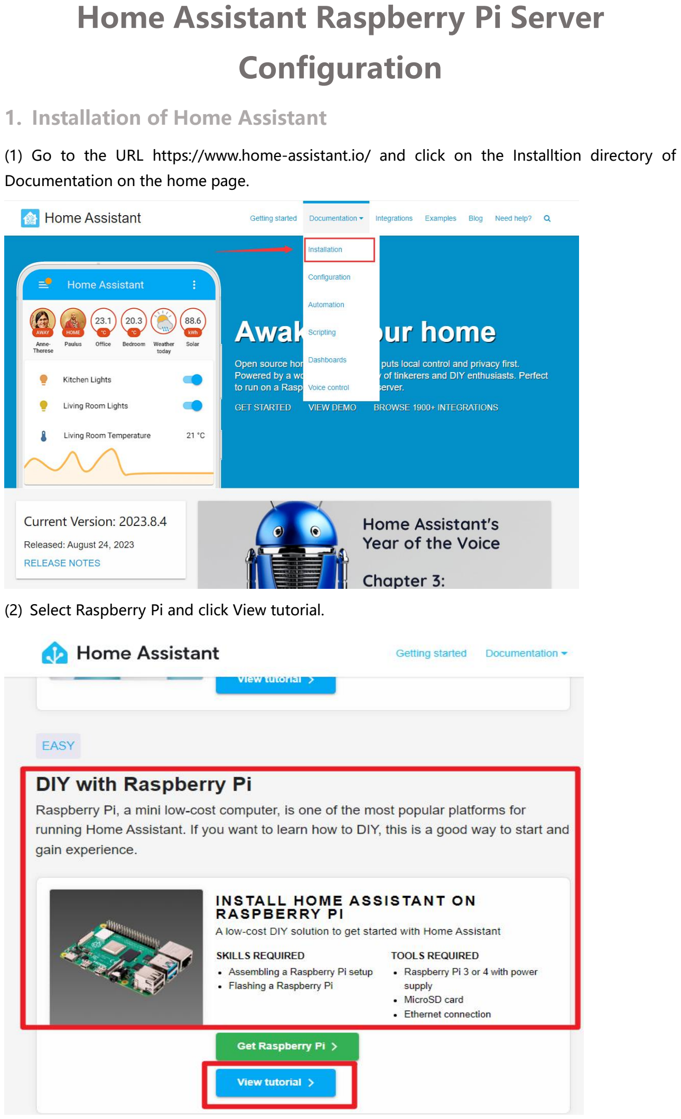
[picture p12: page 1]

## 1. Installation of Home Assistant

(1) Go to the URL https://www.home-assistant.io/ and click on the Installtion directory of Documentation on the home page.
(2) Select Raspberry Pi and click View tutorial.

## 2. Write the image to the SD card

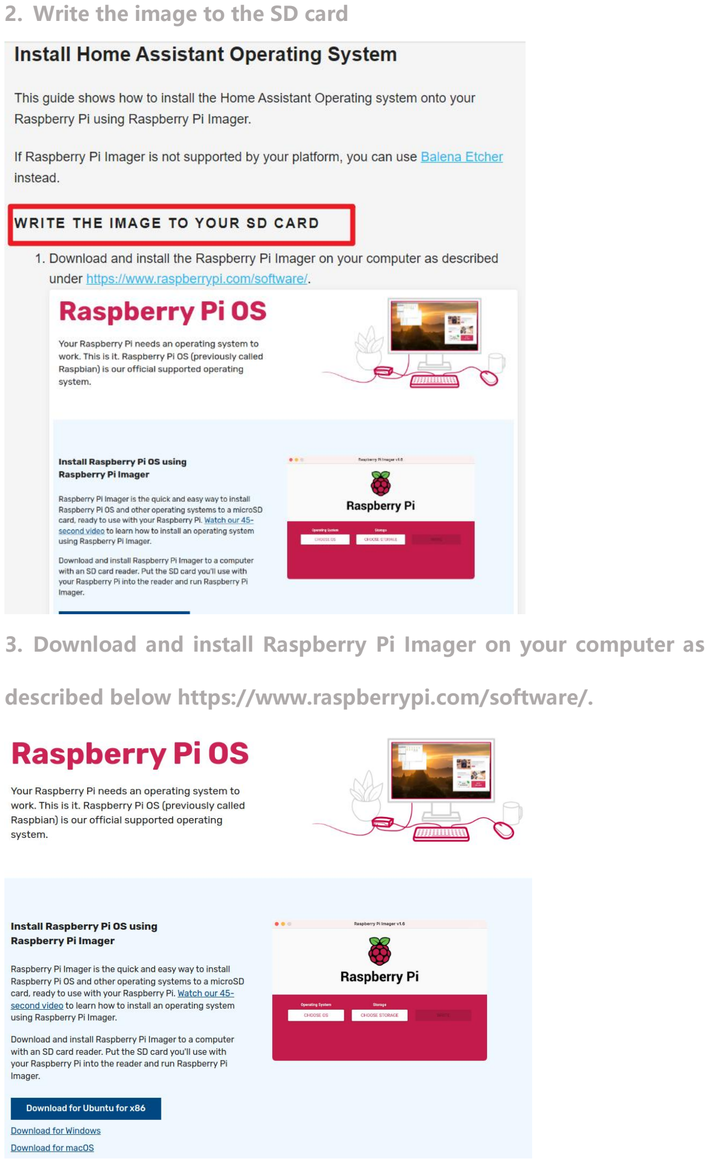
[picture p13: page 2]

## 3. Download and install Raspberry Pi Imager on your computer as

described below https://www.raspberrypi.com/software/.

4. Open Raspberry Pi Imager and select your Raspberry Pi device.

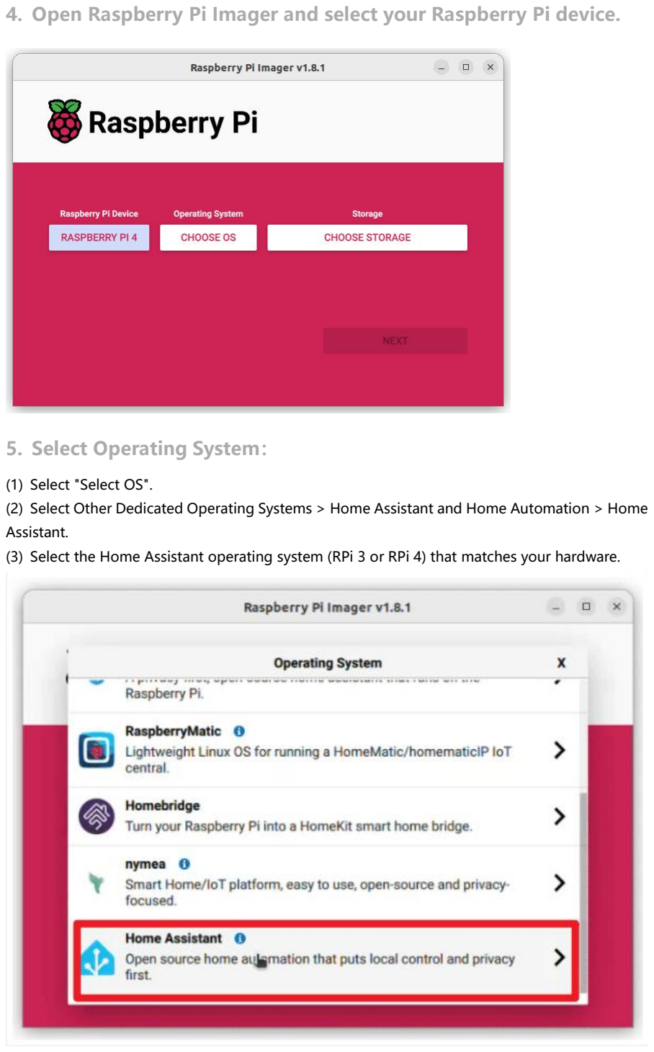
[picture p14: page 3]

## 5. Select Operating System：

(1) Select "Select OS". (2) Select Other Dedicated Operating Systems > Home Assistant and Home Automation > Home

Assistant. (3) Select the Home Assistant operating system (RPi 3 or RPi 4) that matches your hardware.

## 6. Select storage:

(1)Insert the SD card into the computer. Note:The contents of the card will be overwritten. (2)Select your SD card.

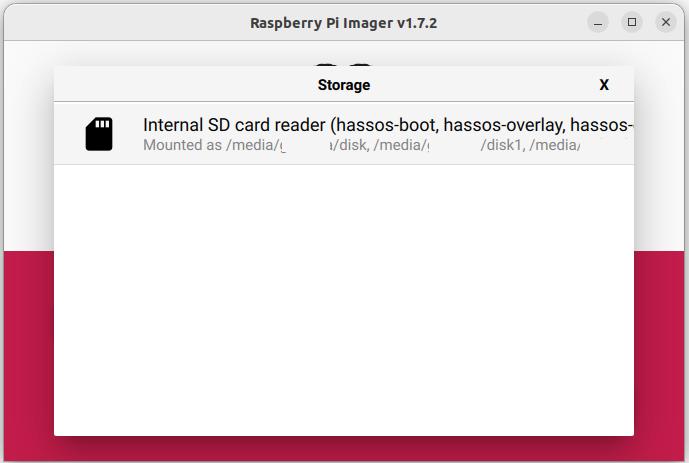
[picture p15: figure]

## 7. Write the installer to the SD card:

(1) To start the process, select Next. (2) Wait for the Home Assistant OS to write to the SD card.

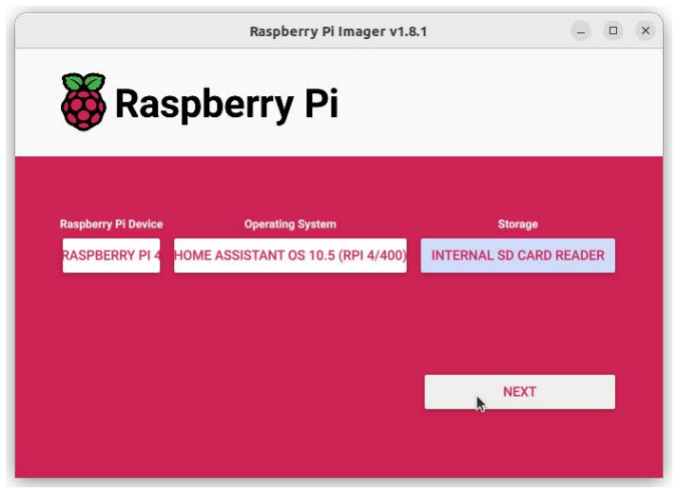
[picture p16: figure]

## 8. Eject the SD card. 9. Start Raspberry Pi

(1) Insert the SD card into the Raspberry Pi. (2) Plug in the Ethernet cable and make sure the Raspberry Pi is connected to the same network

as your computer.

(3) Connect the power supply and start the device. 10. start the Raspberry Pi, start after the completion of we can see

## the LAN ip address and port information, 8123 is the management

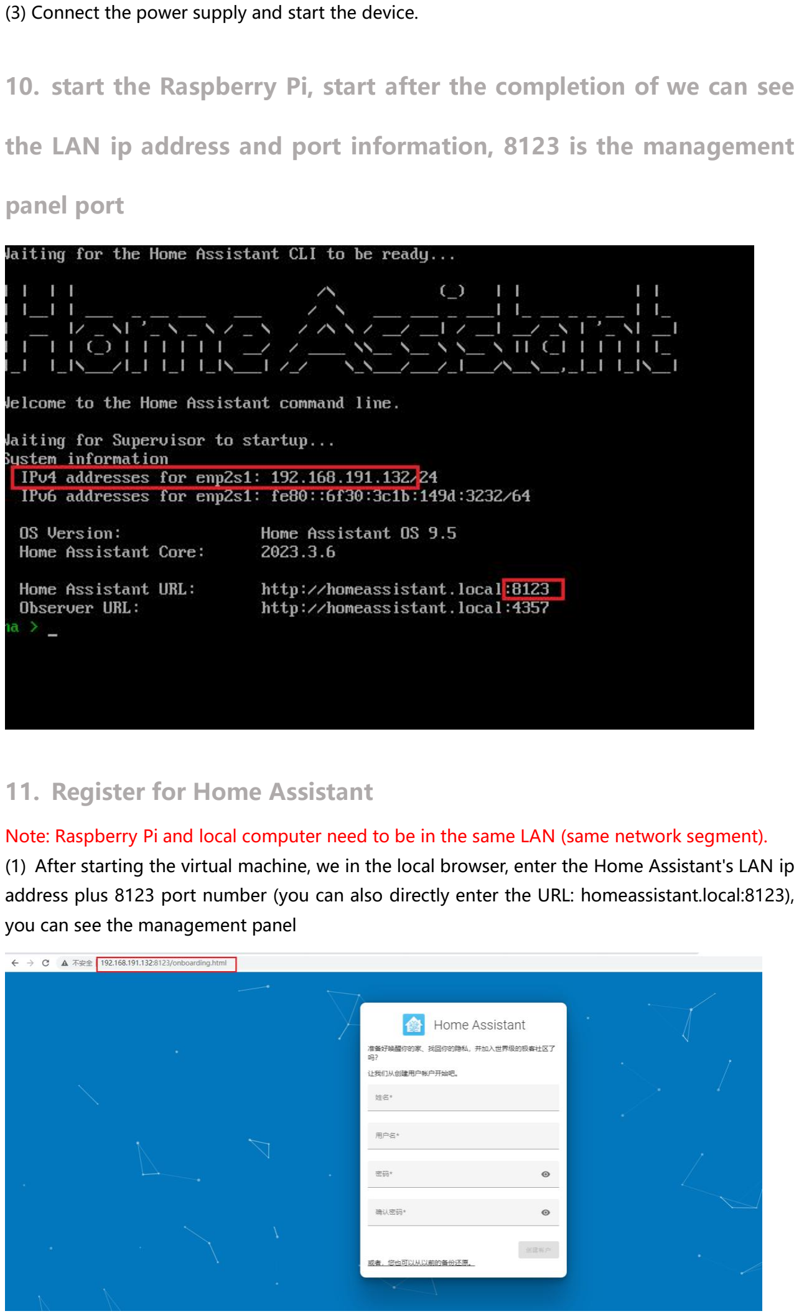
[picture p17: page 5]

## panel port

## 11. Register for Home Assistant

Note: Raspberry Pi and local computer need to be in the same LAN (same network segment). (1) After starting the virtual machine, we in the local browser, enter the Home Assistant's LAN ip

address plus 8123 port number (you can also directly enter the URL: homeassistant.local:8123), you can see the management panel

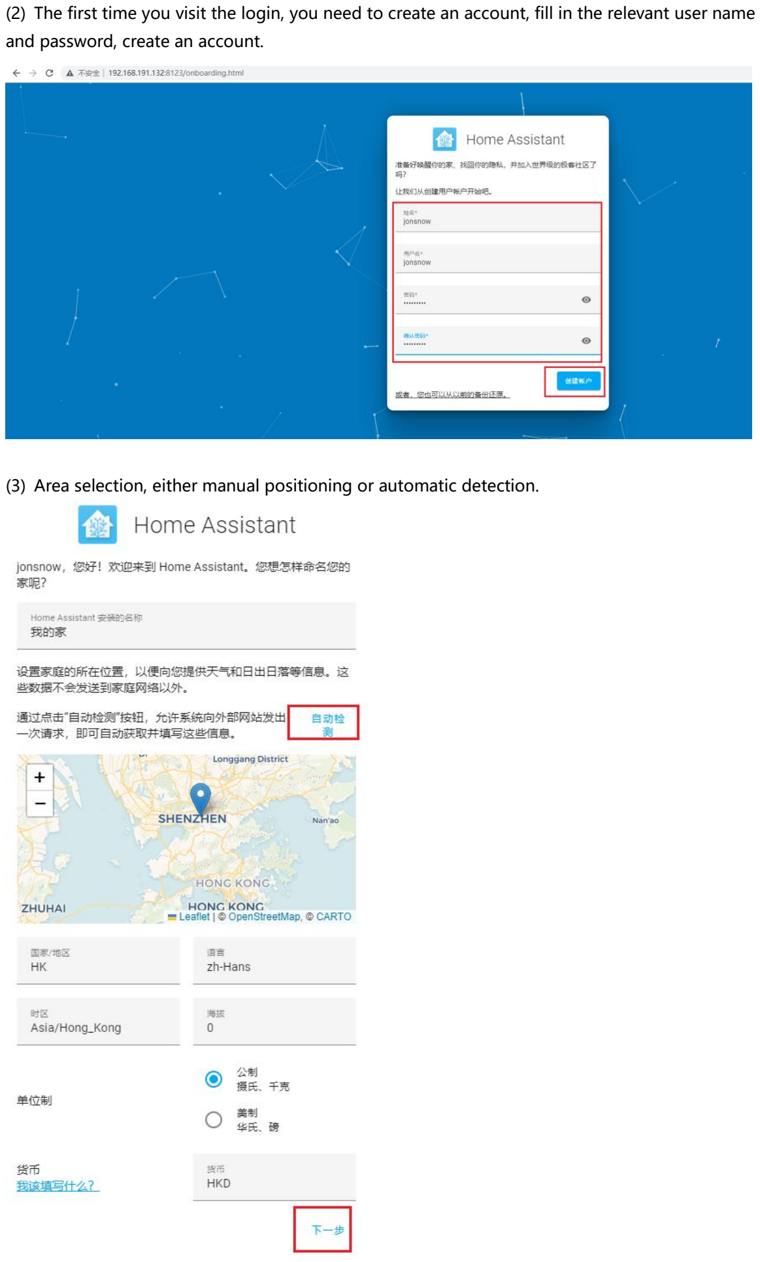
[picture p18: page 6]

(2) The first time you visit the login, you need to create an account, fill in the relevant user name and password, create an account.
(3) Area selection, either manual positioning or automatic detection.

(4) Next click Next by default

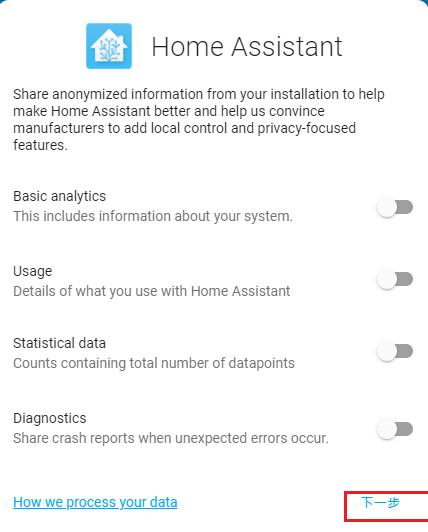
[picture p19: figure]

(5) Then click Finish, here prompted to add a smart device, you can click Finish, and then set up your own settings.

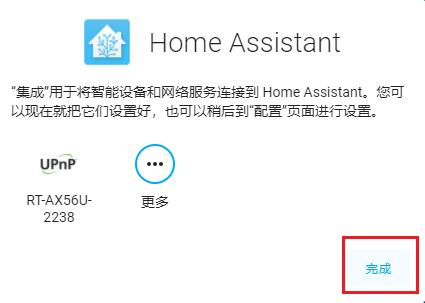
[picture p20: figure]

(6) Then you're in the control panel screen

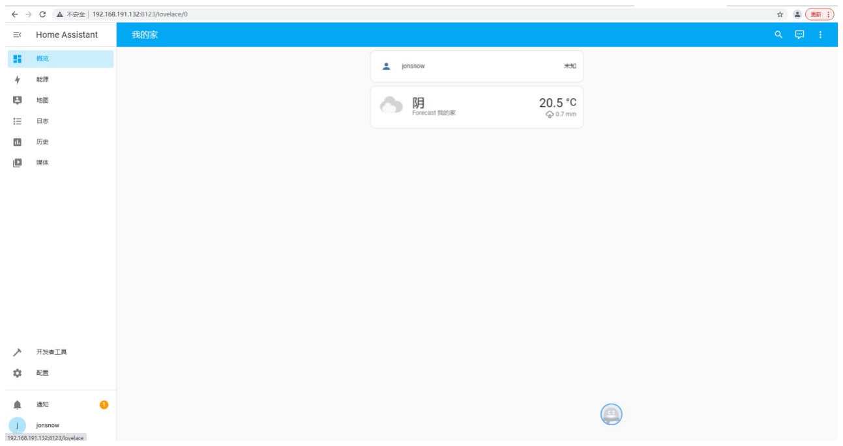
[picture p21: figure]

## 12. Configuring MQTT

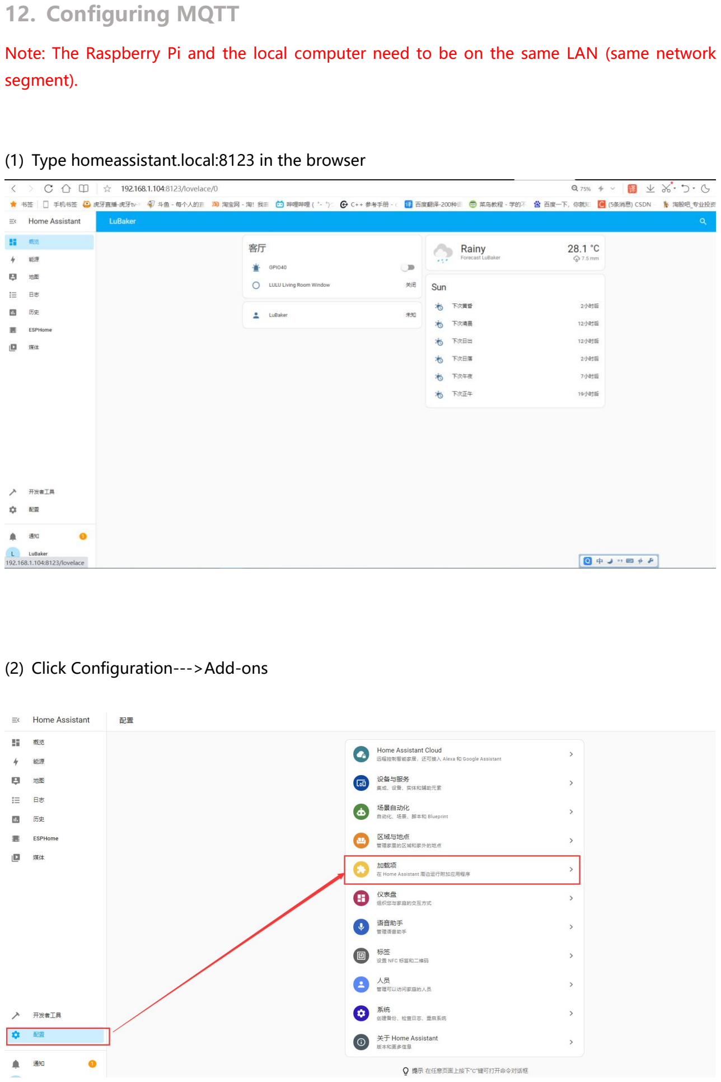
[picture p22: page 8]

Note: The Raspberry Pi and the local computer need to be on the same LAN (same network segment).

(1) Type homeassistant.local:8123 in the browser
(2) Click Configuration--->Add-ons

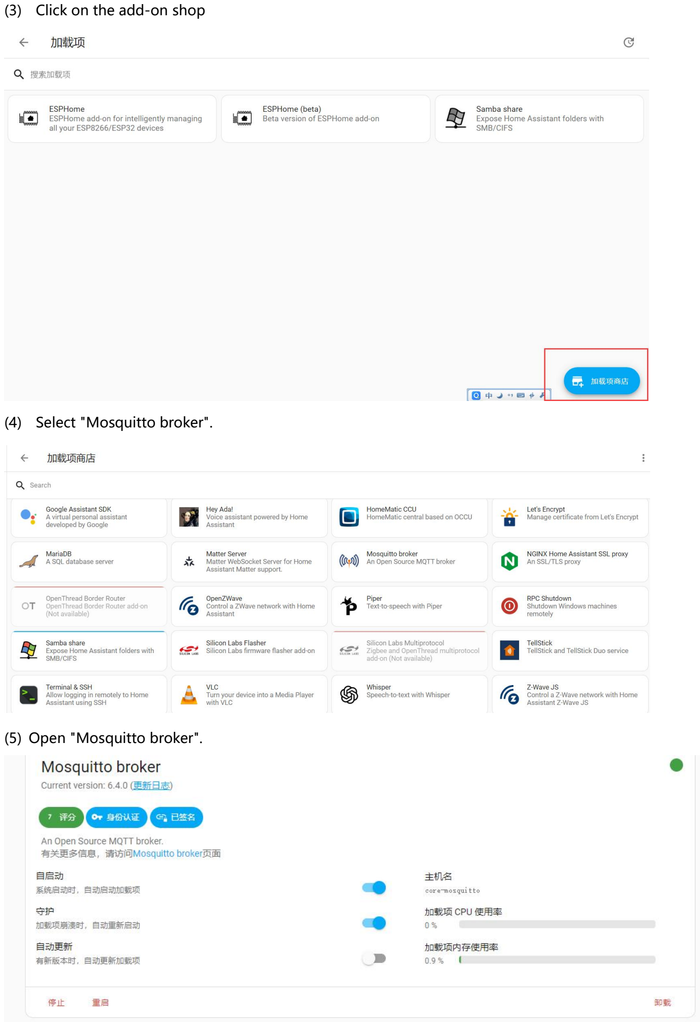
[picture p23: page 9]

(3) Click on the add-on shop
(4) Select "Mosquitto broker".
(5) Open "Mosquitto broker".

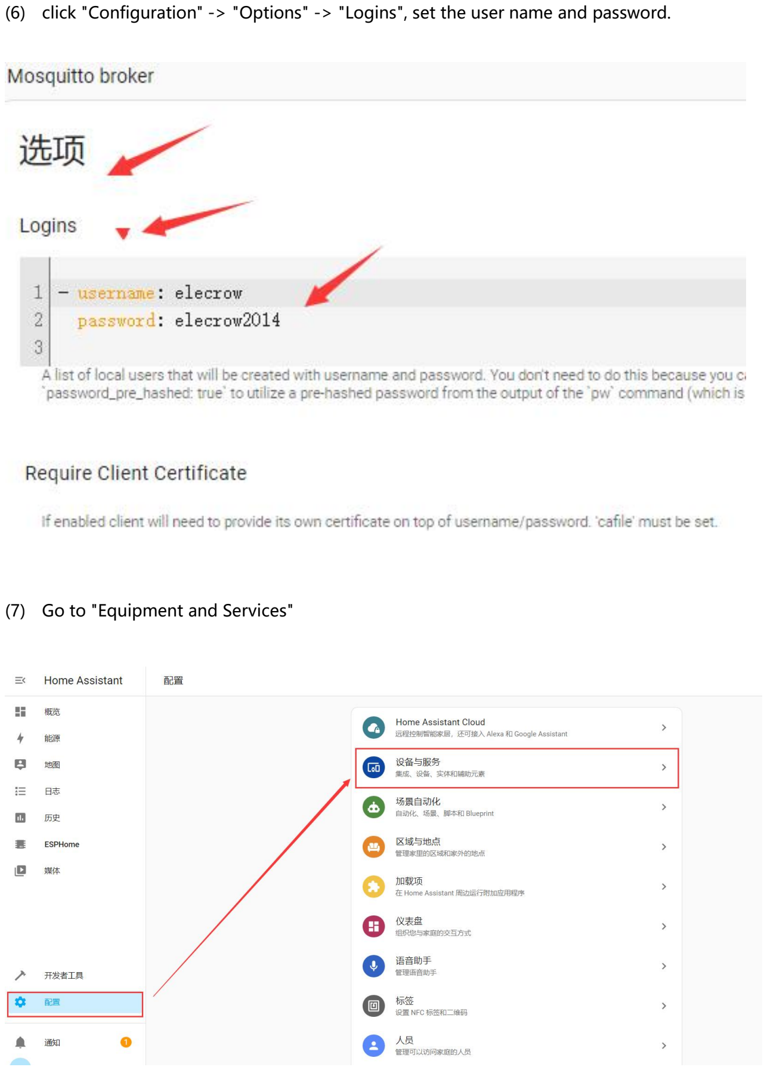
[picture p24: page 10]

(6) click "Configuration" -> "Options" -> "Logins", set the user name and password.
(7) Go to "Equipment and Services"

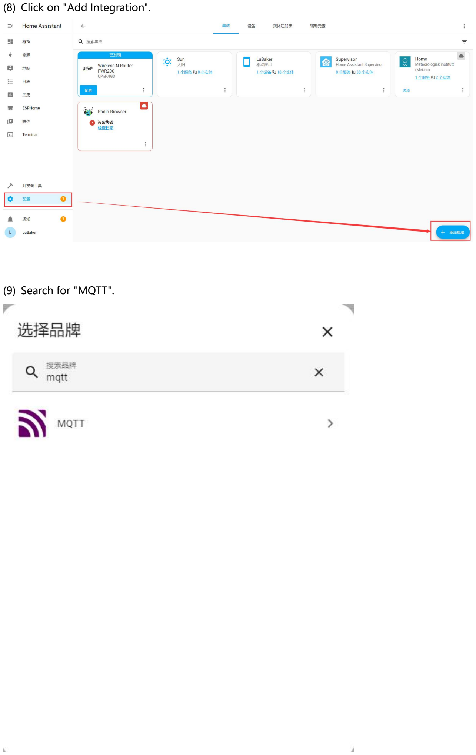
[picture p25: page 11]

(8) Click on "Add Integration".
(9) Search for "MQTT".

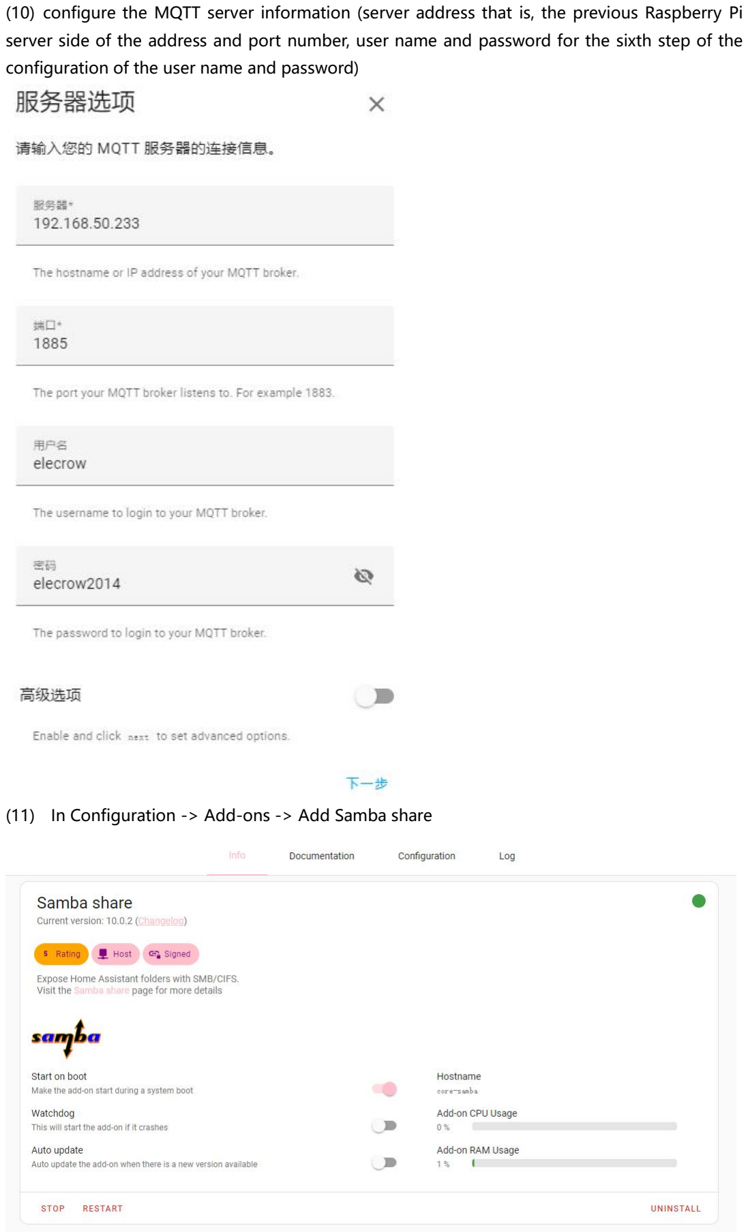
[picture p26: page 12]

(10) configure the MQTT server information (server address that is, the previous Raspberry Pi server side of the address and port number, user name and password for the sixth step of the configuration of the user name and password)
(11) In Configuration -> Add-ons -> Add Samba share

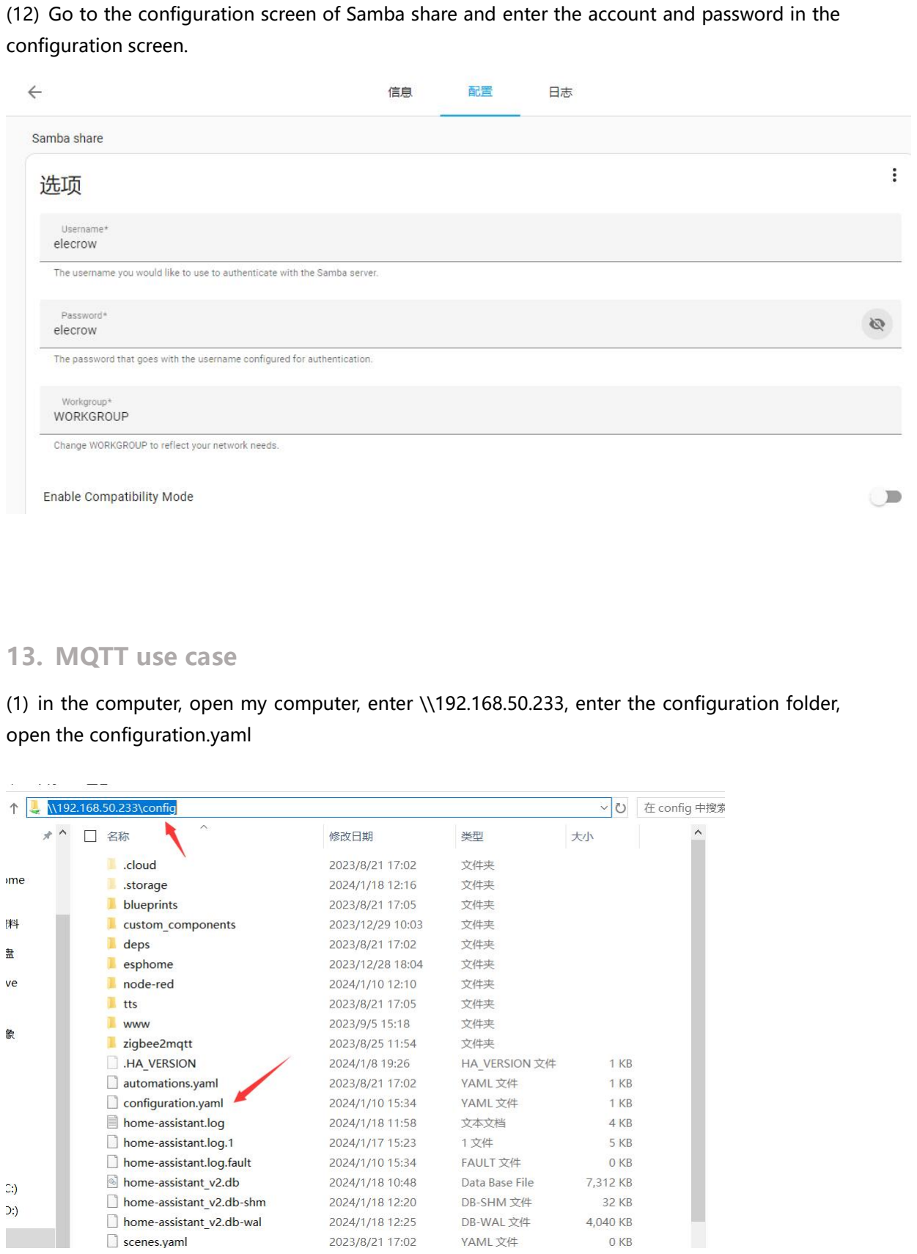
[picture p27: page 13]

(12) Go to the configuration screen of Samba share and enter the account and password in the configuration screen.

## 13. MQTT use case

(1) in the computer, open my computer, enter \\192.168.50.233, enter the configuration folder, open the configuration.yaml


(2) Add a light and temperature/humidity sensor module by entering the following code in configuration.yaml. You need to pay attention to the format indentation, you can refer to the following figure for format indentation.

mqtt:
light:
- name: "led"
state_topic: "esp32/led/state"

command_topic: "esp32/led/command" payload_on: "ON"
payload_off: "OFF"
sensor:
- name: "Temperature"
state_topic: "esp32/temperature" unit_of_measurement: "°C"
- name: "Humidity"
state_topic: "esp32/humidity" unit_of_measurement: "%" Above belongs to the configuration in yaml file to enable lights and sensors with brightness. For
more knowledge refer to the link: https://www.home-assistant.io/integrations/light.mqtt/. 14. After | saving | the | above | code, | go | to | the | main

## interface->Overview->Edit Dashboard->Add Card->Select the entity

## just written in configuration.yaml in the card->Click Finish to

complete the addition.


## 15. Burn the corresponding arduino code for the screen. (Refer to

## "3.5inch_Squareline_Demo Download Introduction" document)

## 16. Server-side effect display


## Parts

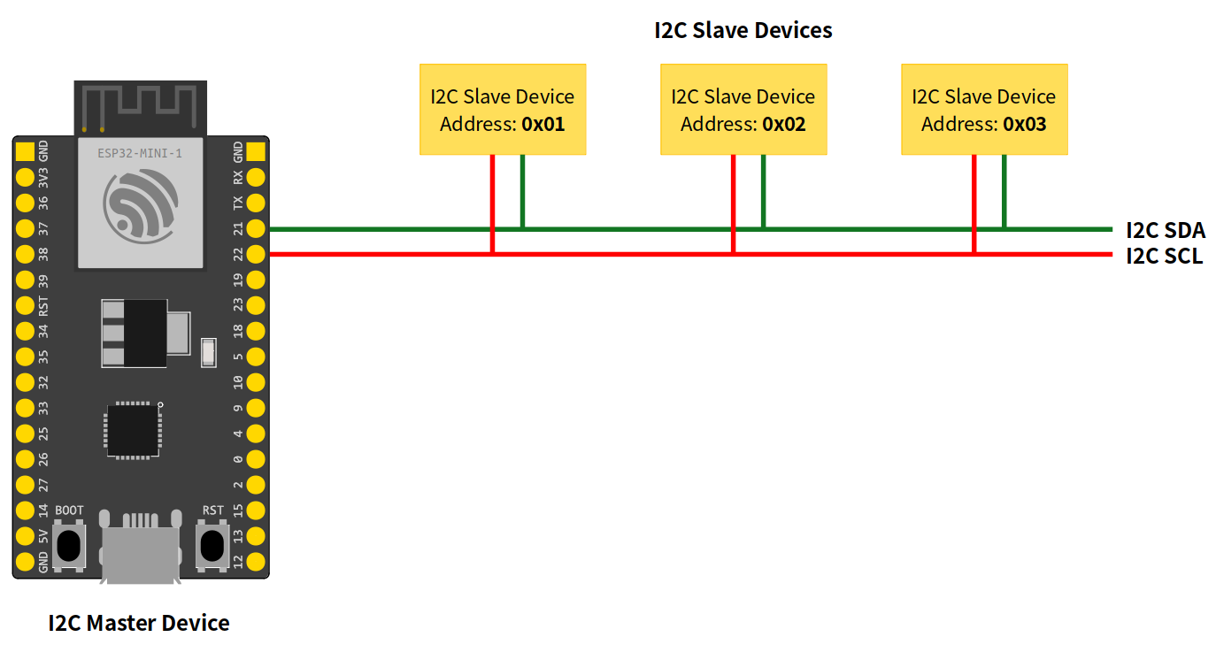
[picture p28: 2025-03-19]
example/V1.0_and_V2.0_and_V2.1/ESP_IDF/CrowPanel_ESP32_3.5/components/arduino-esp32-master/docs/source/_static/arduino_i2c_master.png

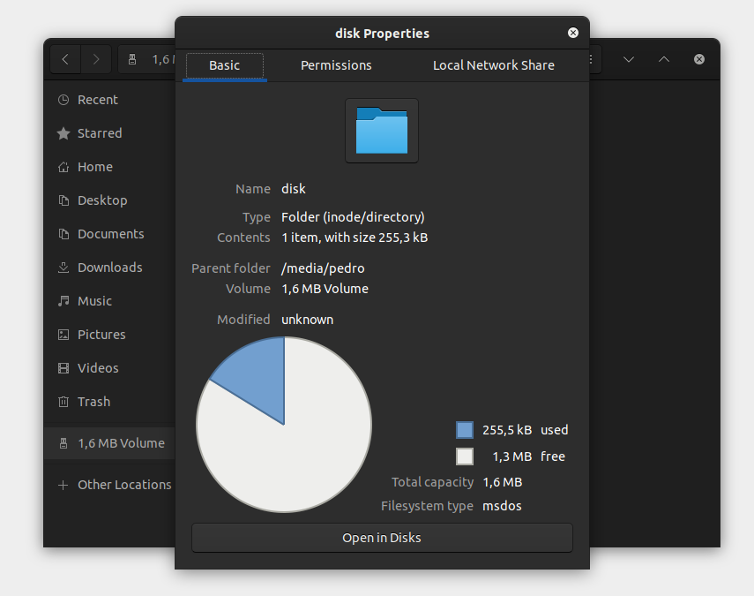
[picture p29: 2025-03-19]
example/V1.0_and_V2.0_and_V2.1/ESP_IDF/CrowPanel_ESP32_3.5/components/arduino-esp32-master/docs/source/_static/usb_msc_drive.png

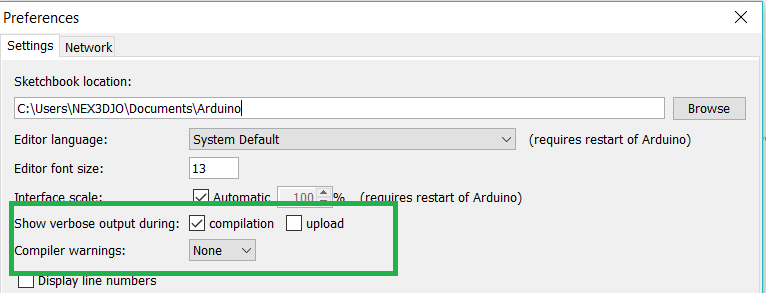
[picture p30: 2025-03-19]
example/V1.0_and_V2.0_and_V2.1/ESP_IDF/CrowPanel_ESP32_3.5/components/arduino-esp32-master/docs/source/_static/ota_esp32_verbose.png

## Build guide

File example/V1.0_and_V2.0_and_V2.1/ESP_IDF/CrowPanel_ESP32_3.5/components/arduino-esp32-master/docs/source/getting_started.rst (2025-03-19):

###############
Getting Started
###############

About Arduino ESP32
-------------------

Welcome to the Arduino ESP32 support documentation! Here you will find important information on how to use the project.

First Things First
------------------

.. note::
    Before continuing, we must be clear that this project is supported by `Espressif Systems`_ and the community.
    Everyone is more than welcome to contribute back to this project.

ESP32 is a single 2.4 GHz Wi-Fi-and-Bluetooth SoC (System On a Chip) designed by `Espressif Systems`_.

ESP32 is designed for mobile, wearable electronics, and Internet-of-Things (IoT) applications. It features all the state-of-the-art characteristics 
of low-power chips, including fine-grained clock gating, multiple power modes,and dynamic power scaling. For instance, in a low-power IoT sensor 
hub application scenario, ESP32 is woken-up periodically and only when a specified condition is detected. Low-duty cycle is used to minimize the 
amount of energy that the chip expends. 

The output of the power amplifier is also adjustable, thus contributing to an optimal trade-off between communication range, data rate and 
power consumption.

The ESP32 series is available as a chip or module.

.. _supported_socs:

Supported SoC's
---------------

Here are the ESP32 series supported by the Arduino-ESP32 project:

======== ====== =========== ===================================
SoC      Stable Development Datasheet
======== ====== =========== ===================================
ESP32    Yes    Yes         `ESP32`_
ESP32-S2 Yes    Yes         `ESP32-S2`_
ESP32-C3 Yes    Yes         `ESP32-C3`_
ESP32-S3 No     Yes         `ESP32-S3`_
======== ====== =========== ===================================

See `Boards <boards/boards.html>`_ for more details about ESP32 development boards.

Arduino Core Reference
----------------------

This documentation is built on the ESP32 and we are not going to cover the common Arduino API. To see the Arduino reference documentation, 
please consider reading the official documentation.

Arduino Official Documentation: `Arduino Reference`_.

Supported Operating Systems
---------------------------

+-------------------+-------------------+-------------------+
|     |       |       |
+-------------------+-------------------+-------------------+
| Windows           | Linux             | macOS             |
+-------------------+-------------------+-------------------+





Supported IDEs
---------------------------

Here is the list of supported IDE for Arduino ESP32 support integration.

+-------------------+-------------------+
|     |         |
+-------------------+-------------------+
| Arduino IDE       | PlatformIO        |
+-------------------+-------------------+




See `Installing Guides <installing.html>`_ for more details on how to install the Arduino ESP32 support.

Support
-------

This is an open project and it's supported by the community. Fell free to ask for help in one of the community channels.

Community
---------

The Arduino community is huge! You can find a lot of useful content on the Internet.
Here are some community channels where you may find information and ask for some help, if needed.

- `ESP32 Forum`_: Official Espressif Forum.
- `ESP32 Forum - Arduino`_: Official Espressif Forum for Arduino related discussions.
- `ESP32 Forum - Hardware`_: Official Espressif Forum for Hardware related discussions.
- `Gitter`_
- `Espressif MCUs (Discord)`_
- `ESP32 on Reddit`_

Issues Reporting
----------------

Before opening a new issue, please read this: 

Be sure to search for a similar reported issue. This avoids duplicating or creating noise in the GitHub Issues reporting.
We also have the troubleshooting guide to save your time on the most common issues reported by users.

For more details about creating new Issue, see the `Issue Template <https://github.com/espressif/arduino-esp32/blob/master/.github/ISSUE_TEMPLATE/Issue-report.yml>`_.

If you have any new idea, see the `Feature request Template <https://github.com/espressif/arduino-esp32/blob/master/.github/ISSUE_TEMPLATE/Feature-request.yml>`_.

First Steps
-----------

Here are the first steps to get the Arduino ESP32 support running.

To install Arduino-ESP32, please see the dedicated section on the Installation guide. We recommend you install it using the boards manager.

.. toctree::
    :maxdepth: 2
    
    How to Install <installing>
    Development Boards <boards/boards>

Examples
--------

After installing the toolchain into your environment, you will be able to see all the dedicated examples for the ESP32. These examples are located
in the examples menu or inside each library folder.

    https://github.com/espressif/arduino-esp32/tree/master/libraries

.. include:: common/datasheet.inc

Resources
---------

.. _Espressif Systems: https://www.espressif.com 
.. _Espressif Product Selector: https://products.espressif.com/
.. _Arduino.cc: https://www.arduino.cc/en/Main/Software
.. _Arduino Reference: https://www.arduino.cc/reference/en/
.. _ESP32 Forum: https://esp32.com
.. _ESP32 Forum - Arduino: https://esp32.com/viewforum.php?f=19
.. _ESP32 Forum - Hardware: https://esp32.com/viewforum.php?f=12
.. _Gitter: https://gitter.im/espressif/arduino-esp32
.. _Adafruit (Discord): https://discord.gg/adafruit
.. _Espressif MCUs (Discord): https://discord.gg/nKxMTnkD
.. _ESP32 on Reddit: https://www.reddit.com/r/esp32

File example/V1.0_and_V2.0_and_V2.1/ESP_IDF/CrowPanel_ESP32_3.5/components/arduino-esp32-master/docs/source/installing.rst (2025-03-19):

##########
Installing
##########

This guide will show how to install the Arduino-ESP32 support.

Before Installing
-----------------

We recommend you install the support using your favorite IDE, but other options are available depending on your operating system. 
To install Arduino-ESP32 support, you can use one of the following options.

Installing using Arduino IDE
----------------------------



This is the way to install Arduino-ESP32 directly from the Arduino IDE.

.. note::
   For overview of SoC's support, take a look on `Supported Soc's table <https://docs.espressif.com/projects/arduino-esp32/en/latest/getting_started.html#supported-soc-s>`_ where you can find if the particular chip is under stable or development release.

- Stable release link::

   https://raw.githubusercontent.com/espressif/arduino-esp32/gh-pages/package_esp32_index.json

- Development release link::

   https://raw.githubusercontent.com/espressif/arduino-esp32/gh-pages/package_esp32_dev_index.json

.. note::
   Starting with the Arduino IDE version 1.6.4, Arduino allows installation of third-party platform 
   packages using Boards Manager. We have packages available for Windows, macOS, and Linux.

To start the installation process using the Boards Managaer, follow these steps:

-  Install the current upstream Arduino IDE at the 1.8 level or later. The current version is at the `arduino.cc`_ website.

-  Start Arduino and open the Preferences window.



-  Enter one of the release links above into *Additional Board Manager URLs* field. You can add multiple URLs, separating them with commas.



-  Open Boards Manager from Tools > Board menu and install *esp32* platform (and do not forget to select your ESP32 board from Tools > Board menu after installation).



- Restart Arduino IDE.

Installing using PlatformIO
---------------------------



PlatformIO is a professional collaborative platform for embedded development. It has out-of-the-box support for ESP32 SoCs and allows working with Arduino ESP32 as well as ESP-IDF from Espressif without changing your development environment. PlatformIO includes lots of instruments for the most common development tasks such as debugging, unit testing, and static code analysis.

A detailed overview of the PlatformIO ecosystem and its philosophy can be found in `the official documentation <https://docs.platformio.org/en/latest/core/index.html>`_.

PlatformIO can be used in two flavors:

- `PlatformIO IDE <https://platformio.org/platformio-ide>`_ is a toolset for embedded C/C++ development available on Windows, macOS and Linux platforms

- `PlatformIO Core (CLI) <https://docs.platformio.org/en/latest/core/index.html>`_ is a command-line tool that consists of a multi-platform build system, platform and library managers and other integration components. It can be used with a variety of code development environments and allows integration with cloud platforms and web services

To install PlatformIO, you can follow this Getting Started, provided at `docs.platformio.org`_.

Using the stable code
*********************

.. note::
   A detailed overview of supported development boards, examples and frameworks can be found on `the official Espressif32 dev-platform page <https://registry.platformio.org/platforms/platformio/espressif32>`_ in the PlatformIO Registry.

The most reliable and easiest way to get started is to use the latest stable version of the ESP32 development platform that passed all tests/verifications and can be used in production.

Create a new project and select one of the available boards. You can change after by changing the `platformio.ini <https://docs.platformio.org/en/latest/projectconf/index.html>`_ file.

- For ESP32

.. code-block:: bash

   [env:esp32dev]
   platform = espressif32
   board = esp32dev
   framework = arduino

- For ESP32-S2 (ESP32-S2-Saola-1 board)

.. code-block:: bash

   [env:esp32-s2-saola-1]
   platform = espressif32
   board = esp32-s2-saola-1
   framework = arduino

- For ESP32-C3 (ESP32-C3-DevKitM-1 board)

.. code-block:: bash

   [env:esp32-c3-devkitm-1]
   platform = espressif32
   board = esp32-c3-devkitm-1
   framework = arduino

How to update to the latest code
********************************

To test the latest Arduino ESP32, you need to change your project *platformio.ini* accordingly.
The following configuration uses the upstream version of the Espressif development platform and the latest Arduino core directly from the Espressif GitHub repository:

.. code-block:: bash

   [env:esp32-c3-devkitm-1]
   platform = https://github.com/platformio/platform-espressif32.git
   board = esp32-c3-devkitm-1
   framework = arduino
   platform_packages =
       framework-arduinoespressif32 @ https://github.com/espressif/arduino-esp32#master

To get more information about PlatformIO, see the following links:

- `PlatformIO Core (CLI) <https://docs.platformio.org/en/latest/core/index.html>`_

- `PlatformIO Home <https://docs.platformio.org/en/latest/home/index.html>`_

- `Tutorials and Examples <https://docs.platformio.org/en/latest/tutorials/index.html>`_

- `Library Management <https://docs.platformio.org/en/latest/librarymanager/index.html>`_

Windows (manual installation)
-----------------------------

.. warning:: Arduino ESP32 core v2.x.x cannot be used on Windows 8.x x86 (32 bits), Windows 7 or earlier. The Windows 32 bits OS is no longer supported by this toolchain.

   The Arduino ESP32 v1.0.6 still works on WIN32. You might want to install python 3.8.x because it is the latest release supported by Windows 7.

Steps to install Arduino ESP32 support on Windows:

**Step 1**

1. Download and install the latest Arduino IDE ``Windows Installer`` from [arduino.cc](https://www.arduino.cc/en/Main/Software)
2. Download and install Git from [git-scm.com](https://git-scm.com/download/win)
3. Start ``Git GUI`` and do the following steps:

- Select ``Clone Existing Repository``



- Select source and destination
   - Sketchbook Directory: Usually ``C:/Users/[YOUR_USER_NAME]/Documents/Arduino`` and is listed underneath the "Sketchbook location" in Arduino preferences.
   - Source Location: ``https://github.com/espressif/arduino-esp32.git``
   - Target Directory: ``[ARDUINO_SKETCHBOOK_DIR]/hardware/espressif/esp32``
   - Click ``Clone`` to start cloning the repository

**Step 2**



**Step 3**



- open a `Git Bash` session pointing to ``[ARDUINO_SKETCHBOOK_DIR]/hardware/espressif/esp32`` and execute ```git submodule update --init --recursive``` 
- Open ``[ARDUINO_SKETCHBOOK_DIR]/hardware/espressif/esp32/tools`` and double-click ``get.exe``

**Step 4**



- When ```get.exe``` finishes, you should see the following files in the directory

**Step 5**



1. Plug your ESP32 board and wait for the drivers to install (or install manually any that might be required)
2. Start Arduino IDE
3. Select your board in ``Tools > Board`` menu
4. Select the COM port that the board is attached to
5. Compile and upload (You might need to hold the boot button while uploading)



How to update to the latest code
********************************

1. Start ``Git GUI`` and you should see the repository under ``Open Recent Repository``. Click on it!



1. From menu ``Remote`` select ``Fetch from`` > ``origin``



1. Wait for git to pull any changes and close ``Git GUI``
2. Open ``[ARDUINO_SKETCHBOOK_DIR]/hardware/espressif/esp32/tools`` and double-click ``get.exe``



Linux
-----



Debian/Ubuntu
*************

- Install latest Arduino IDE from `arduino.cc`_.

- Open Terminal and execute the following command (copy -> paste and hit enter):

.. code-block:: bash

   sudo usermod -a -G dialout $USER && \
   sudo apt-get install git && \
   wget https://bootstrap.pypa.io/get-pip.py && \
   sudo python3 get-pip.py && \
   sudo pip3 install pyserial && \
   mkdir -p ~/Arduino/hardware/espressif && \
   cd ~/Arduino/hardware/espressif && \
   git clone https://github.com/espressif/arduino-esp32.git esp32 && \
   cd esp32/tools && \
   python3 get.py

- Restart Arduino IDE.

- If you have Arduino installed to ~/, modify the installation as follows, beginning at `mkdir -p ~/Arduino/hardware`:

.. code-block:: bash

   cd ~/Arduino/hardware
   mkdir -p espressif && \
   cd espressif && \
   git clone https://github.com/espressif/arduino-esp32.git esp32 && \
   cd esp32/tools && \
   python3 get.py

Fedora
******

- Install the latest Arduino IDE from `arduino.cc`_.

.. note::
   Command ``$ sudo dnf -y install arduino`` will most likely install an older release.

- Open Terminal and execute the following command (copy -> paste and hit enter):

.. code-block:: bash

   sudo usermod -a -G dialout $USER && \
   sudo dnf install git python3-pip python3-pyserial && \
   mkdir -p ~/Arduino/hardware/espressif && \
   cd ~/Arduino/hardware/espressif && \
   git clone https://github.com/espressif/arduino-esp32.git esp32 && \
   cd esp32/tools && \
   python get.py

- Restart Arduino IDE.

openSUSE
********

- Install the latest Arduino IDE from `arduino.cc`_.

- Open Terminal and execute the following command (copy -> paste and hit enter):

.. code-block:: bash

   sudo usermod -a -G dialout $USER && \
   if [ `python --version 2>&1 | grep '2.7' | wc -l` = "1" ]; then \
   sudo zypper install git python-pip python-pyserial; \
   else \
   sudo zypper install git python3-pip python3-pyserial; \
   fi && \
   mkdir -p ~/Arduino/hardware/espressif && \
   cd ~/Arduino/hardware/espressif && \
   git clone https://github.com/espressif/arduino-esp32.git esp32 && \
   cd esp32/tools && \
   python get.py

- Restart Arduino IDE.

macOS
-----

- Install the latest Arduino IDE from `arduino.cc`_.

- Open Terminal and execute the following command (copy -> paste and hit enter):

.. code-block:: bash

   mkdir -p ~/Documents/Arduino/hardware/espressif && \
   cd ~/Documents/Arduino/hardware/espressif && \
   git clone https://github.com/espressif/arduino-esp32.git esp32 && \
   cd esp32/tools && \
   python get.py 

Where ``~/Documents/Arduino`` represents your sketch book location as per "Arduino" > "Preferences" > "Sketchbook location" (in the IDE once started). Adjust the command above accordingly.

- If you get the error below, install through the command line dev tools with `xcode-select --install` and try the command above again:

.. code-block:: bash

   xcrun: error: invalid active developer path (/Library/Developer/CommandLineTools), missing xcrun at: /Library/Developer/CommandLineTools/usr/bin/xcrun

- Run the command:

.. code-block:: bash

   xcode-select --install

- Try ``python3`` instead of ``python`` if you get the error: ``IOError: [Errno socket error] [SSL: TLSV1_ALERT_PROTOCOL_VERSION] tlsv1 alert protocol version (_ssl.c:590)`` when running ``python get.py``

- If you get the following error when running ``python get.py`` urllib.error.URLError: <urlopen error SSL: CERTIFICATE_VERIFY_FAILED, go to Macintosh HD > Applications > Python3.6 folder (or any other python version), and run the following scripts: Install Certificates.command and Update Shell Profile.command

- Restart Arduino IDE.

.. _Arduino.cc: https://www.arduino.cc/en/Main/Software
.. _docs.platformio.org: https://docs.platformio.org/en/latest/integration/ide/pioide.html

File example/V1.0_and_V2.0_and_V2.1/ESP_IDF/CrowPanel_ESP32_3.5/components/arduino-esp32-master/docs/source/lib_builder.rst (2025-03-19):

###############
Library Builder
###############

About
-----

Espressif provides a `tool <https://github.com/espressif/esp32-arduino-lib-builder>`_ to simplify building your own compiled libraries for use in Arduino IDE (or your favorite IDE).

This tool can be used to change the project or a specific configuration according to your needs.

Installing
----------

To install the Library Builder into your environment, please, follow the instructions below.

- Clone the ESP32 Arduino lib builder:

.. code-block:: bash

    git clone https://github.com/espressif/esp32-arduino-lib-builder

- Go to the ``esp32-arduino-lib-builder`` folder:

.. code-block:: bash

    cd esp32-arduino-lib-builder

- Build:

.. code-block:: bash

    ./build.sh

If everything works, you may see the following message: ``Successfully created esp32 image.``

Dependencies
************

To build the library you will need to install some dependencies. Maybe you already have installed it, but it is a good idea to check before building.

- Install all dependencies (**Ubuntu**):

.. code-block:: bash

    sudo apt-get install git wget curl libssl-dev libncurses-dev flex bison gperf cmake ninja-build ccache jq

- Install Python and upgrade pip:

.. code-block:: bash

    sudo apt-get install python3
    sudo pip install --upgrade pip

- Install all required packages:

.. code-block:: bash

    pip install --user setuptools pyserial click cryptography future pyparsing pyelftools

Building
--------

If you have all the dependencies met, it is time to build the libraries.

To build using the default configuration:

.. code-block:: bash

    ./build.sh

Custom Build
************

There are some options to help you create custom libraries. You can use the following options:

Usage
^^^^^

.. code-block:: bash

    build.sh [-s] [-A arduino_branch] [-I idf_branch] [-i idf_commit] [-c path] [-t <target>] [-b <build|menuconfig|idf_libs|copy_bootloader|mem_variant>] [config ...]

Skip Install/Update
^^^^^^^^^^^^^^^^^^^

Skip installing/updating of ESP-IDF and all components

.. code-block:: bash

    ./build.sh -s

This option can be used if you already have the ESP-IDF and all components already in your environment.

Set Arduino-ESP32 Branch
^^^^^^^^^^^^^^^^^^^^^^^^

Set which branch of arduino-esp32 to be used for compilation

.. code-block:: bash

    ./build.sh -A <arduino_branch>

Set ESP-IDF Branch
^^^^^^^^^^^^^^^^^^

Set which branch of ESP-IDF is to be used for compilation

.. code-block:: bash

    ./build.sh -I <idf_branch>

Set the ESP-IDF Commit
^^^^^^^^^^^^^^^^^^^^^^

Set which commit of ESP-IDF to be used for compilation

.. code-block:: bash

    ./build.sh -i <idf_commit>

Deploy
^^^^^^

Deploy the build to github arduino-esp32

.. code-block:: bash

    ./build.sh -d

Set the Arduino-ESP32 Destination Folder
^^^^^^^^^^^^^^^^^^^^^^^^^^^^^^^^^^^^^^^^

Set the arduino-esp32 folder to copy the result to. ex. '$HOME/Arduino/hardware/espressif/esp32'

.. code-block:: bash

    ./build.sh -c <path>

This function is used to copy the compiled libraries to the Arduino folder.

Set the Target
^^^^^^^^^^^^^^

Set the build target(chip). ex. 'esp32s3'

.. code-block:: bash

    ./build.sh -t <target>

This build command will build for the ESP32-S3 target. You can specify other targets.

* esp32
* esp32s2
* esp32c3
* esp32s3

Set Build Type
^^^^^^^^^^^^^^

Set the build type. ex. 'build' to build the project and prepare for uploading to a board.

.. note:: This command depends on the ``-t`` argument.

.. code-block:: bash

    ./build.sh -t esp32 -b <build|menuconfig|idf_libs|copy_bootloader|mem_variant>

Additional Configuration
^^^^^^^^^^^^^^^^^^^^^^^^

Specify additional configs to be applied. ex. 'qio 80m' to compile for QIO Flash@80MHz. Requires -b

.. note:: This command requires the ``-b`` to work properly.

.. code-block:: bash

    ./build.sh -t esp32 -b idf_libs qio 80m

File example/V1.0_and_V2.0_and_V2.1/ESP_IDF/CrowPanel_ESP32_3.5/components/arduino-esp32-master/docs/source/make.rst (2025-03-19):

==============
makeEspArduino
==============

The `makeEspArduino <https://github.com/plerup/makeEspArduino>`_ is a generic makefile for any ESP8266/ESP32 Arduino project. 
Using it instead of the Arduino IDE makes it easier to do automated and production builds.

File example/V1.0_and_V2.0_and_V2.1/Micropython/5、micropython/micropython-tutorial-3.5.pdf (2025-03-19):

# Micropython

ESP32 3.5inch Display

Items to be prepared：

ID | module | quantity
Hardware 1 | USB A to TYPE-C cable | 1
2 | 2.4inch screen | 1
3 | Crowtail-light sensor | 1
4 | Crowtail-led | 1
5 | 4-pin HY2.0 cable (for Crowtail module) | 2

Software 1

| Thonny | 1
2 | Lvgl+micropyhton firmware | 1

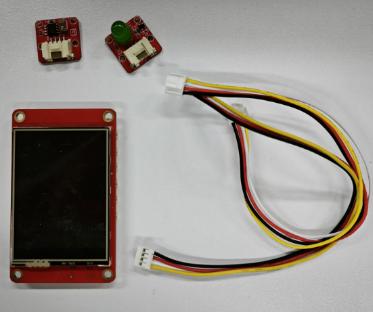
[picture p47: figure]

Software preparation：
Go to https://thonny.org/ and download the corresponding software version (take the Windows version as an example).

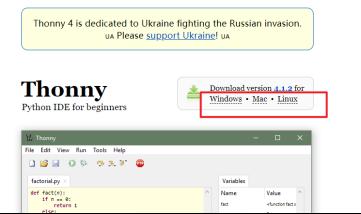
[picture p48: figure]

Double-click the downloaded exe file to install the software. (Go to the next step and install directly)

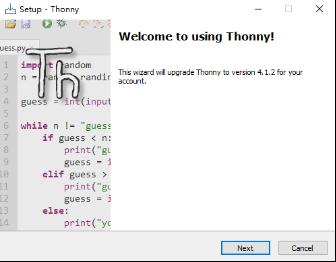
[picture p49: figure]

Firmware download：
Open the thonny software and click Tools

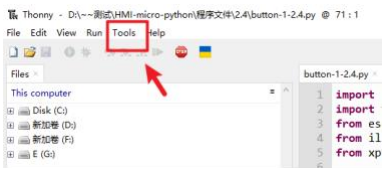
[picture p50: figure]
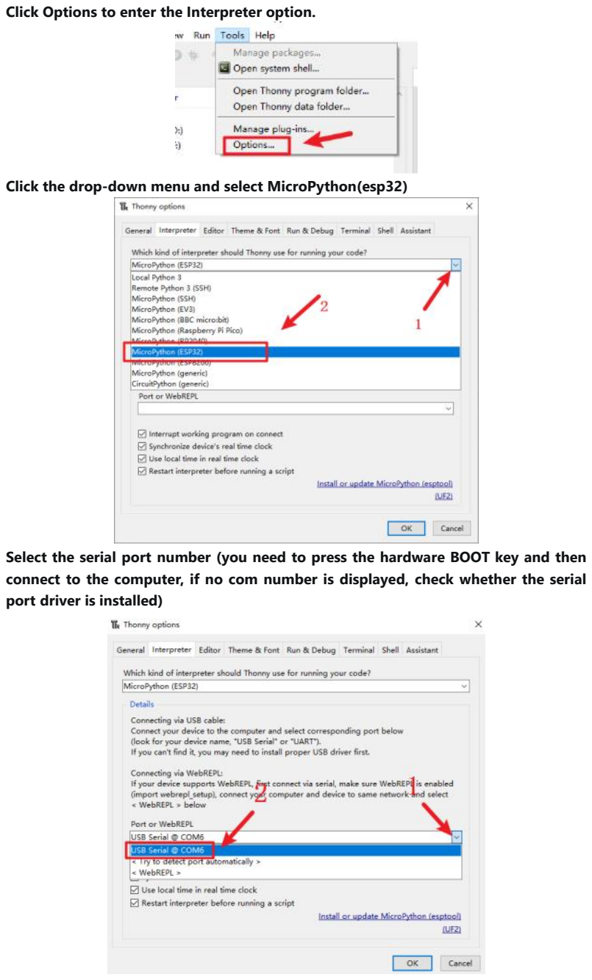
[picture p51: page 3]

Click Options to enter the Interpreter option.

Click the drop-down menu and select MicroPython(esp32)

Select the serial port number (you need to press the hardware BOOT key and then connect to the computer, if no com number is displayed, check whether the serial port driver is installed)

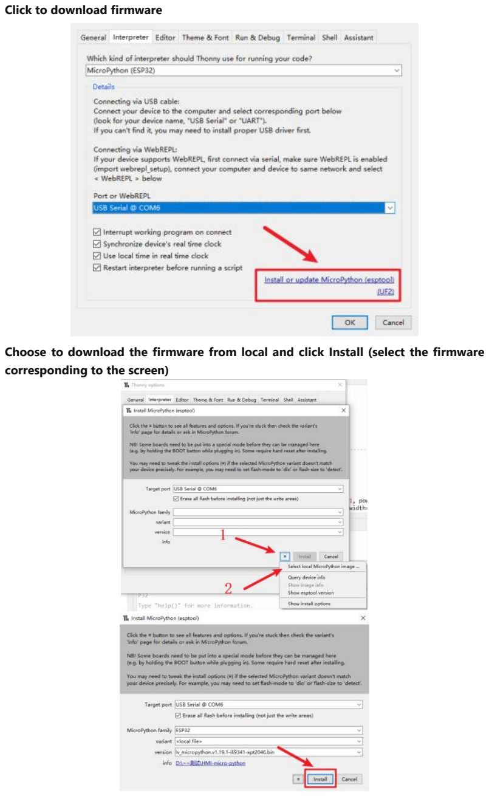
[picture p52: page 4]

Click to download firmware

Choose to download the firmware from local and click Install (select the firmware corresponding to the screen)

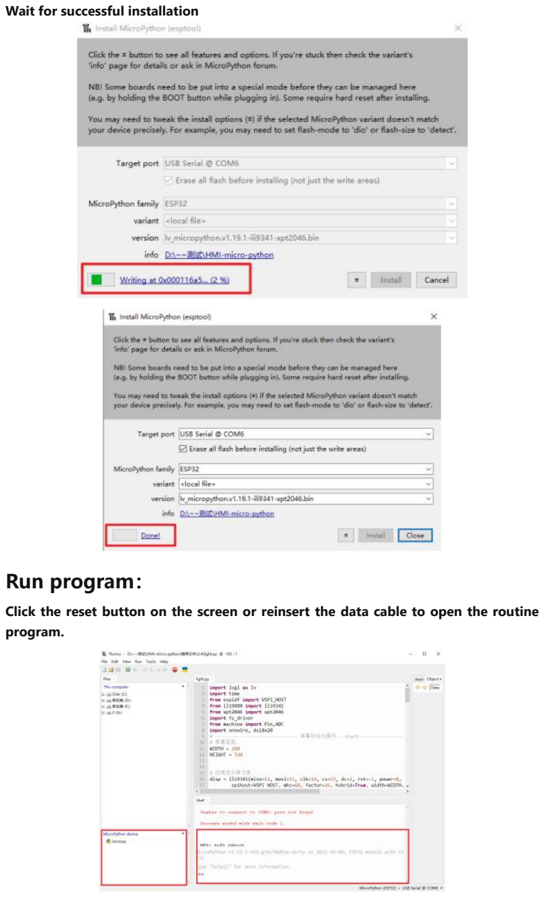
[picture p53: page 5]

Wait for successful installation

Run program：
Click the reset button on the screen or reinsert the data cable to open the routine program.

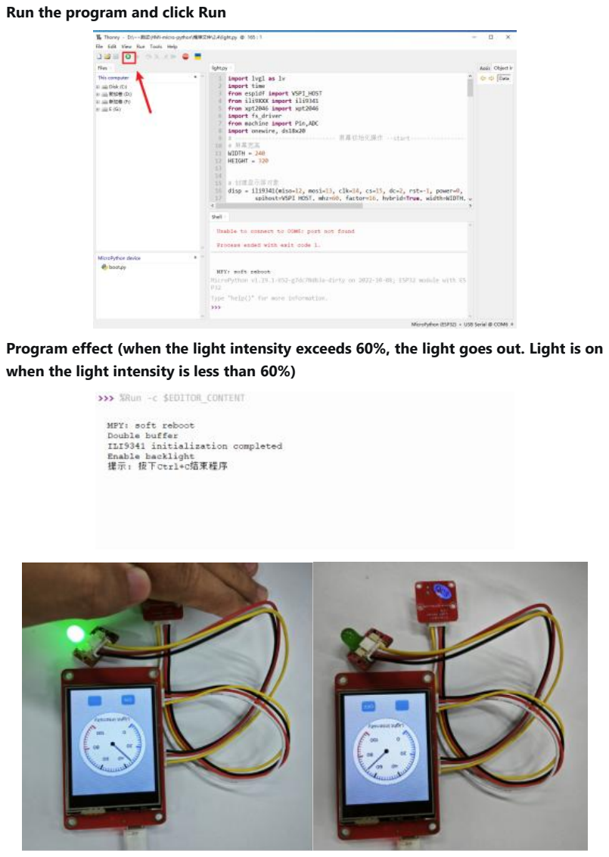
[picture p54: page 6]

Run the program and click Run

Program effect (when the light intensity exceeds 60%, the light goes out. Light is on when the light intensity is less than 60%)

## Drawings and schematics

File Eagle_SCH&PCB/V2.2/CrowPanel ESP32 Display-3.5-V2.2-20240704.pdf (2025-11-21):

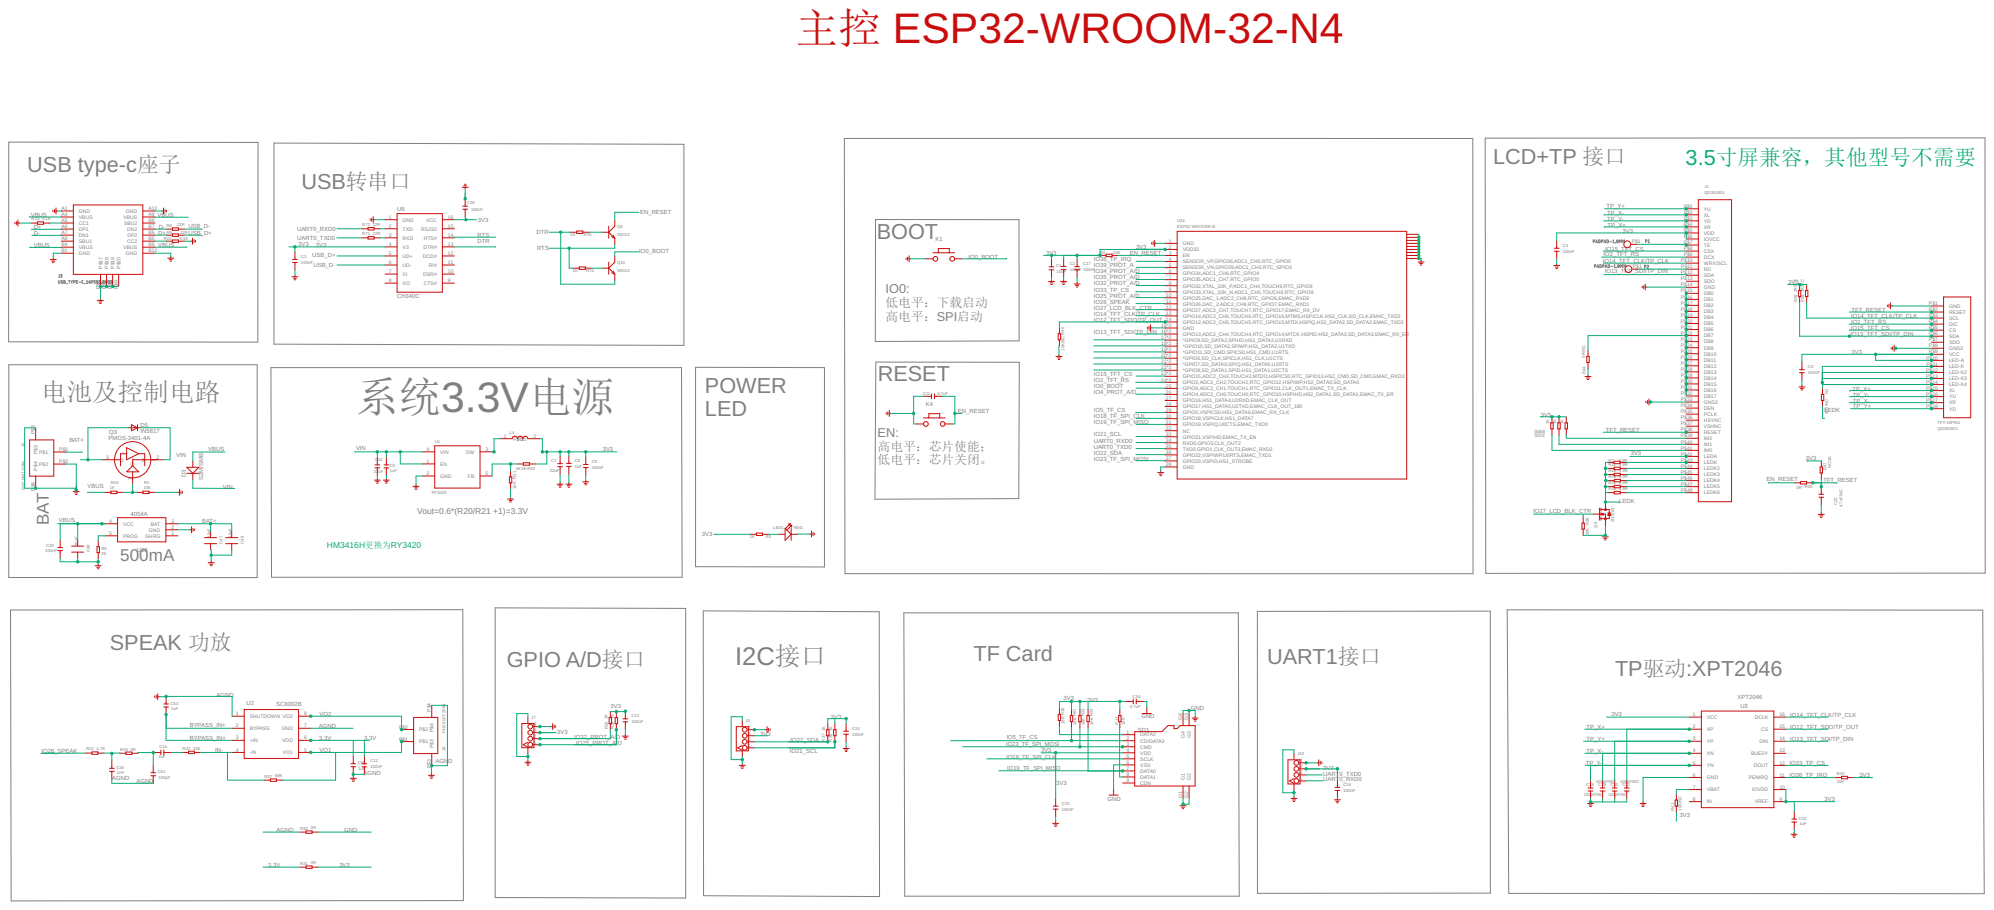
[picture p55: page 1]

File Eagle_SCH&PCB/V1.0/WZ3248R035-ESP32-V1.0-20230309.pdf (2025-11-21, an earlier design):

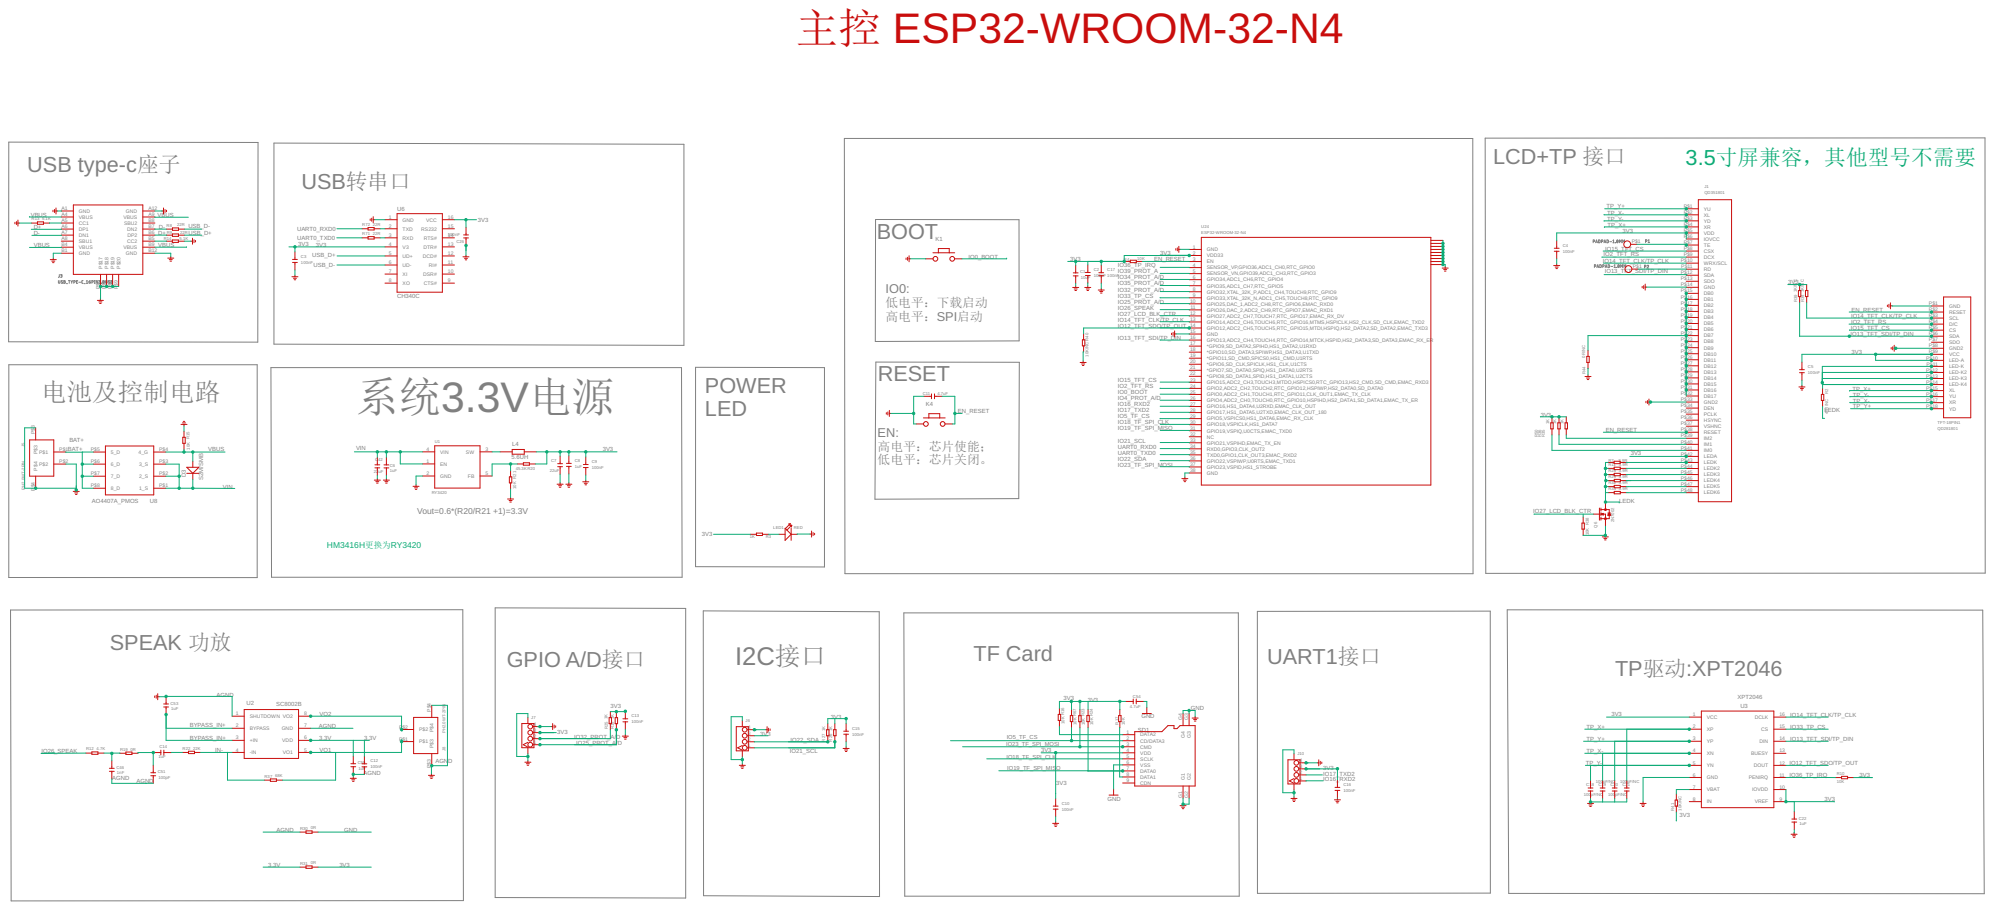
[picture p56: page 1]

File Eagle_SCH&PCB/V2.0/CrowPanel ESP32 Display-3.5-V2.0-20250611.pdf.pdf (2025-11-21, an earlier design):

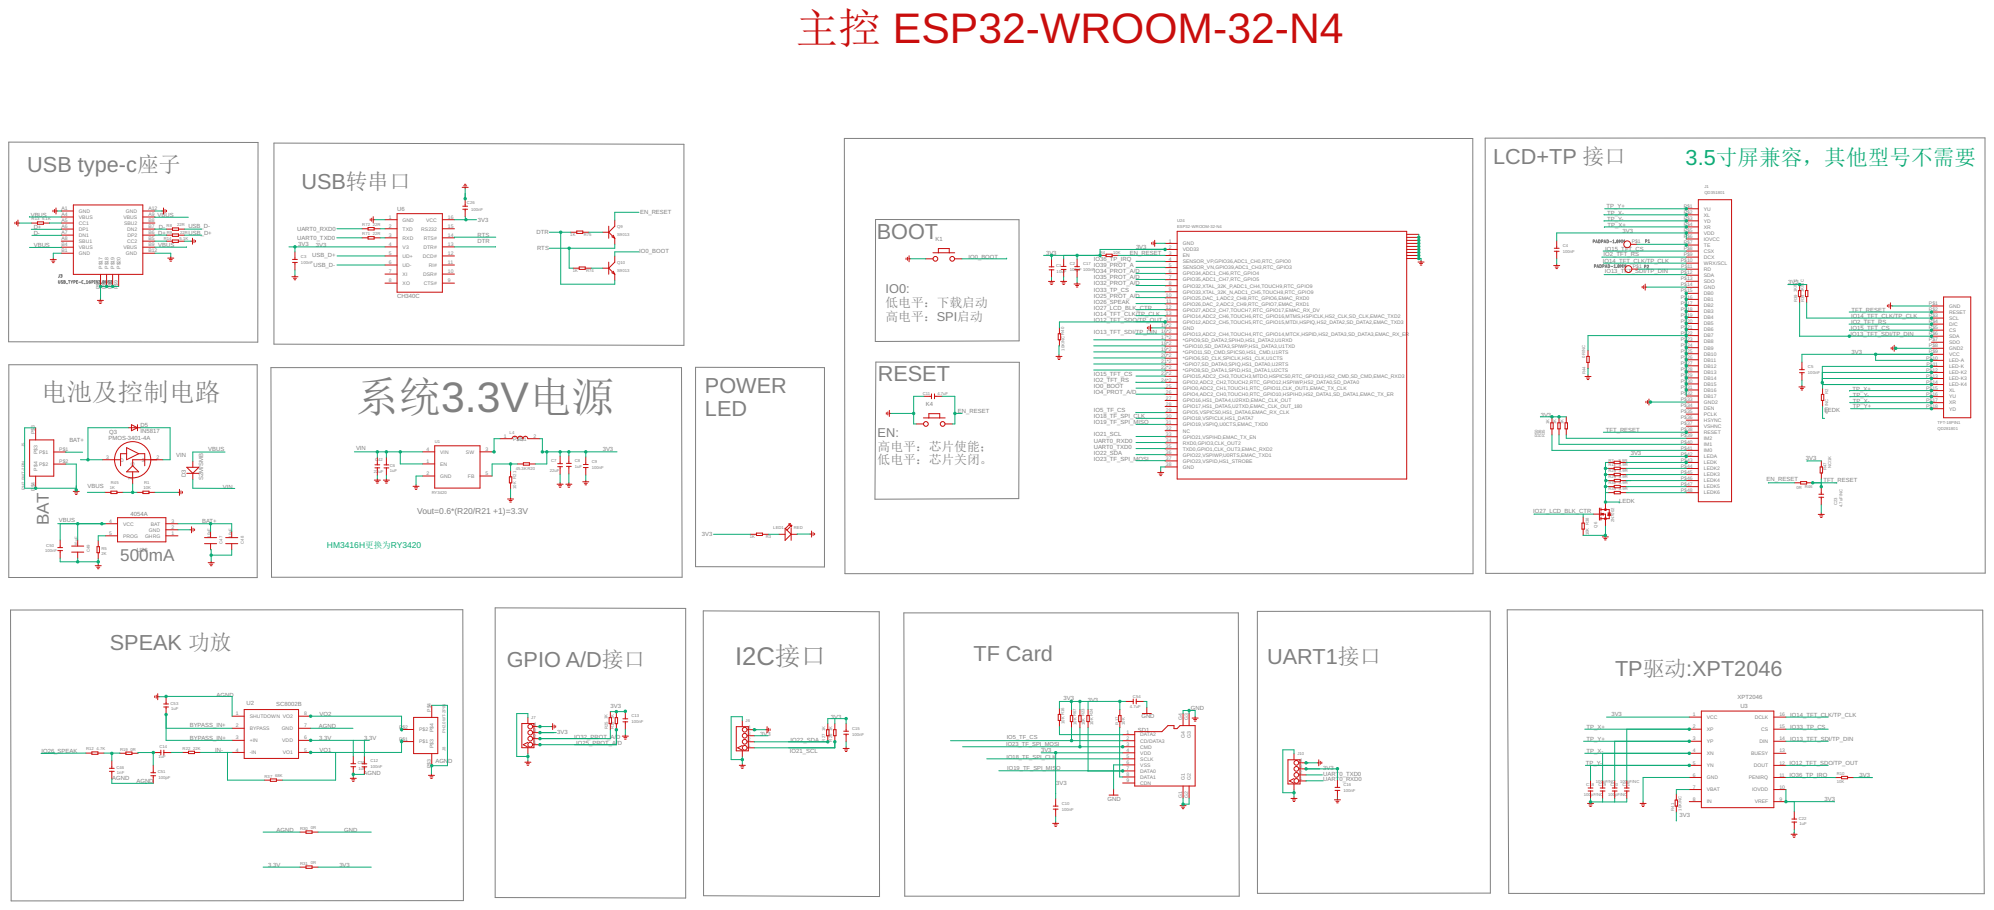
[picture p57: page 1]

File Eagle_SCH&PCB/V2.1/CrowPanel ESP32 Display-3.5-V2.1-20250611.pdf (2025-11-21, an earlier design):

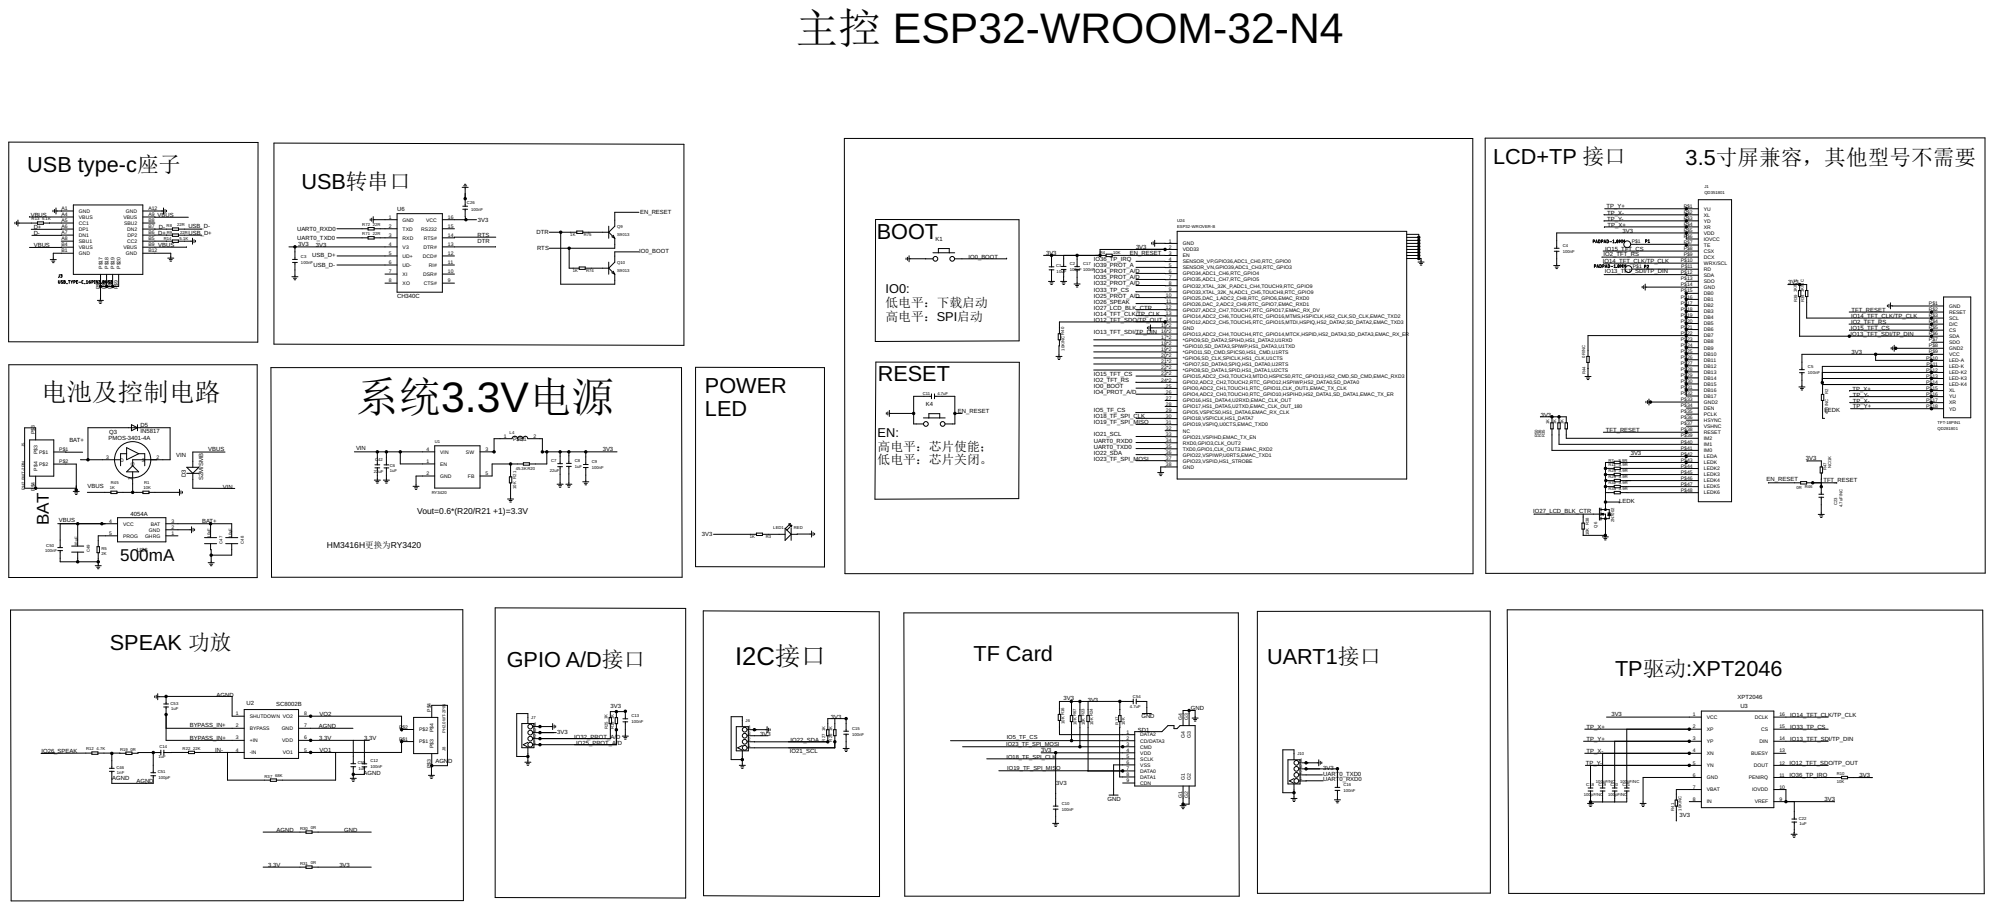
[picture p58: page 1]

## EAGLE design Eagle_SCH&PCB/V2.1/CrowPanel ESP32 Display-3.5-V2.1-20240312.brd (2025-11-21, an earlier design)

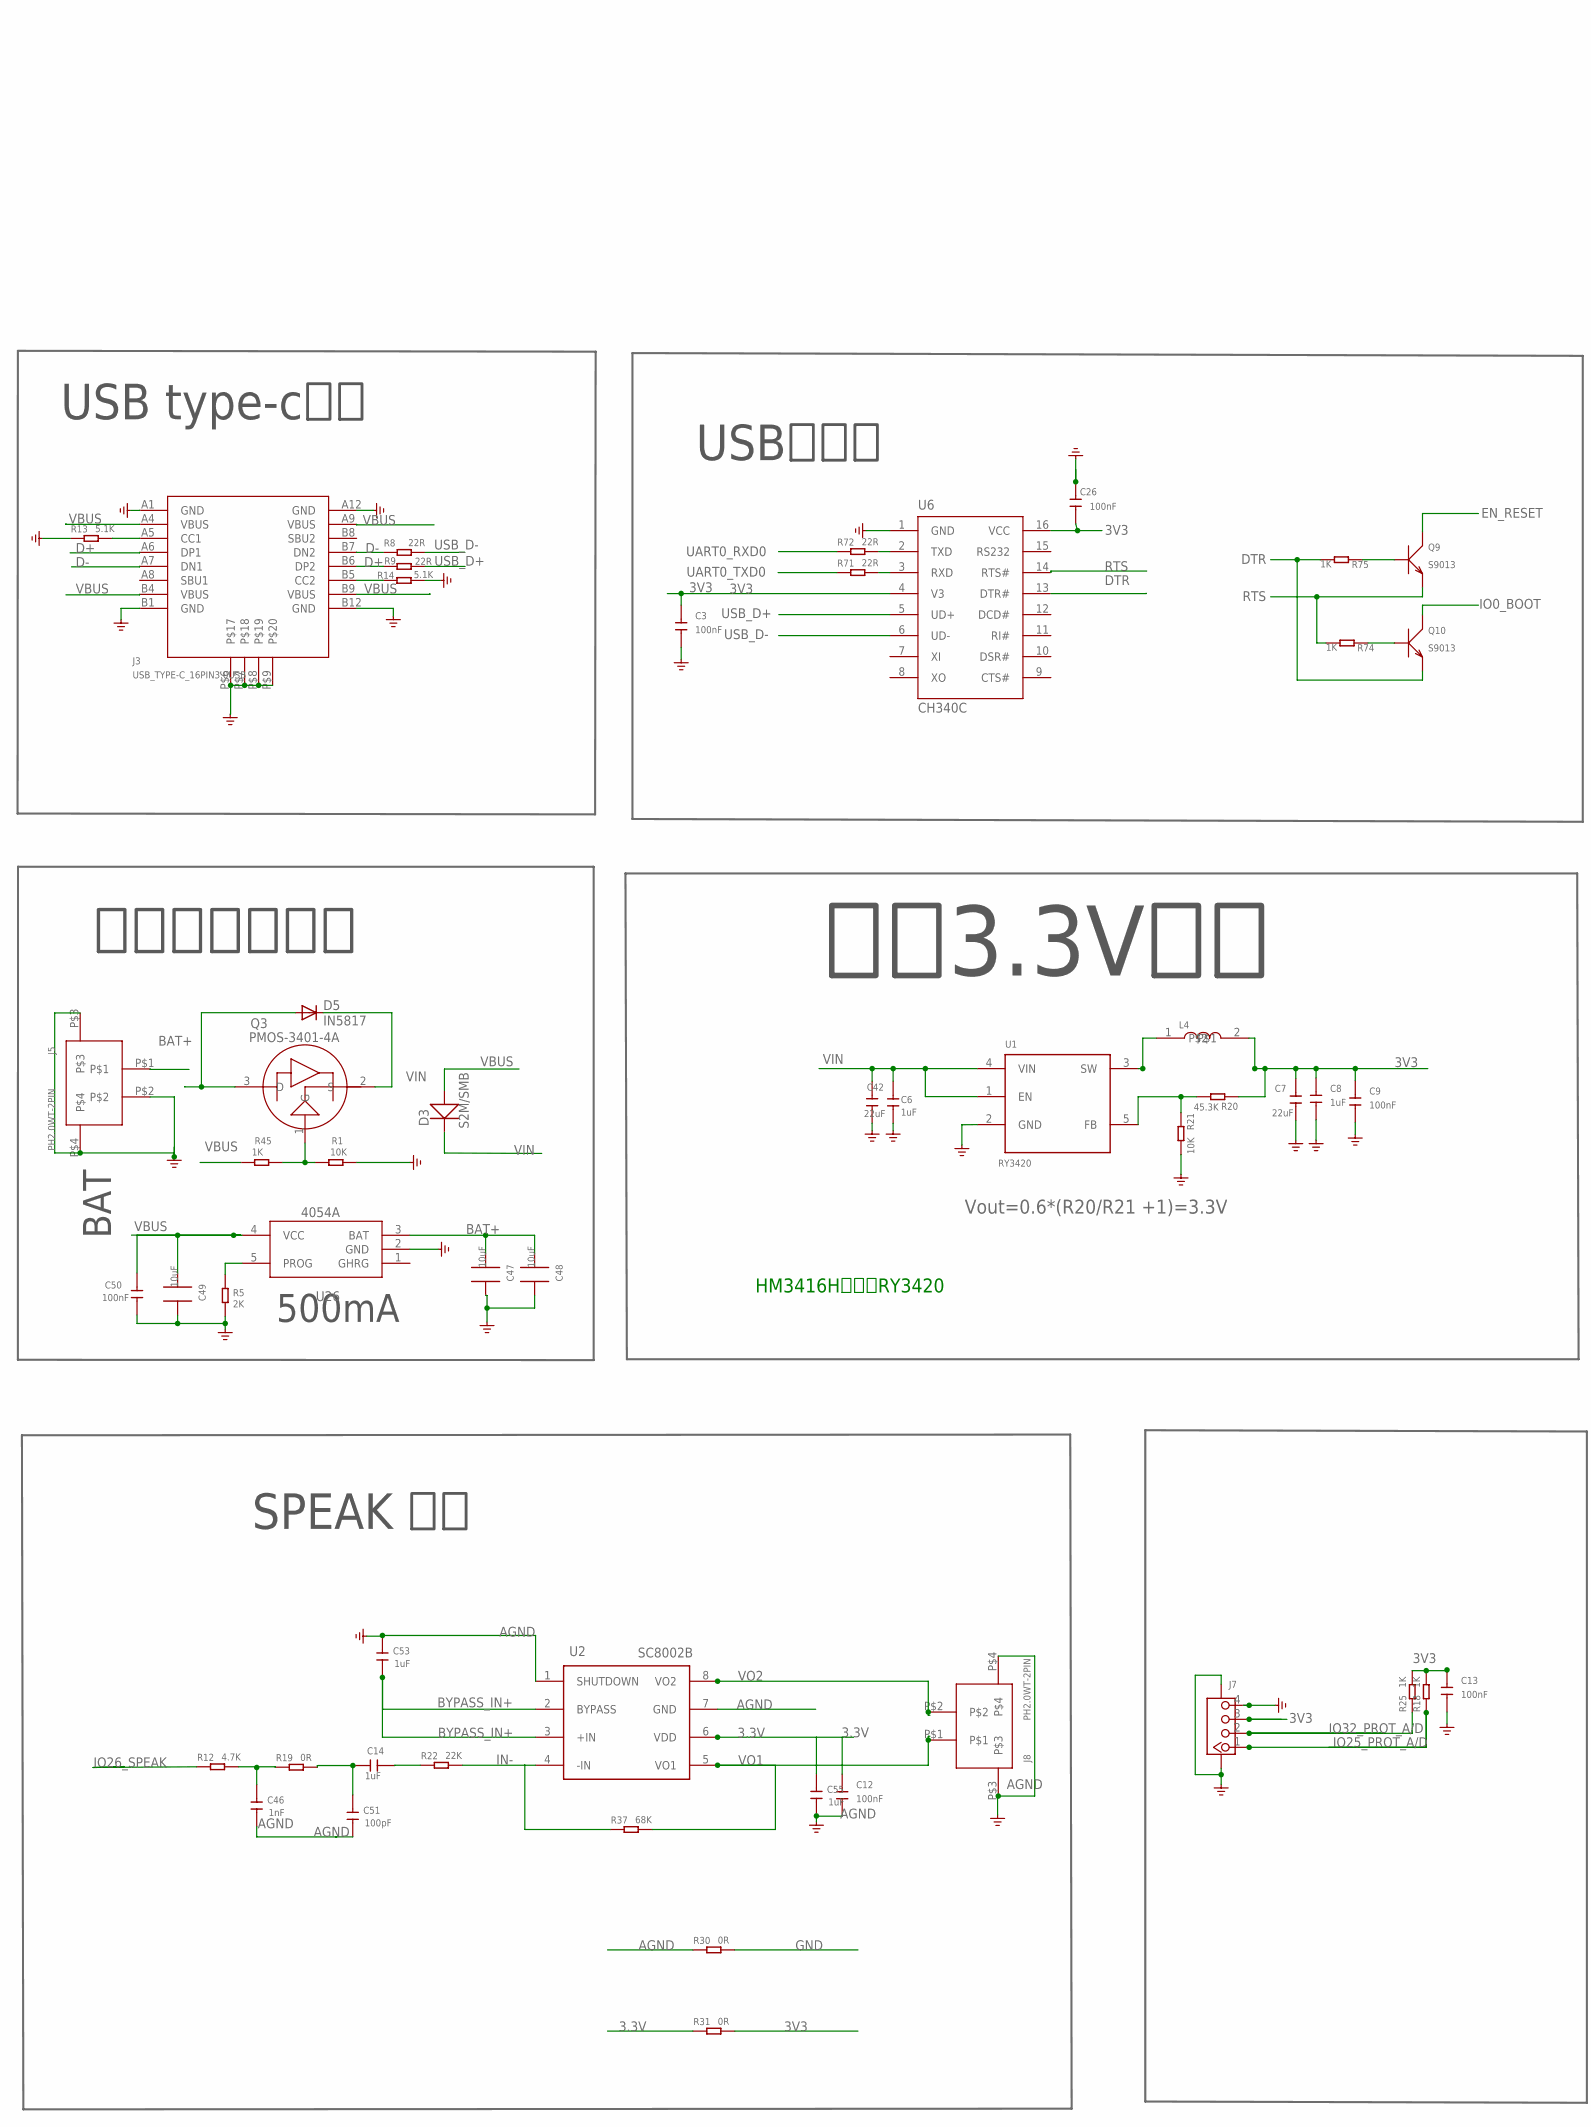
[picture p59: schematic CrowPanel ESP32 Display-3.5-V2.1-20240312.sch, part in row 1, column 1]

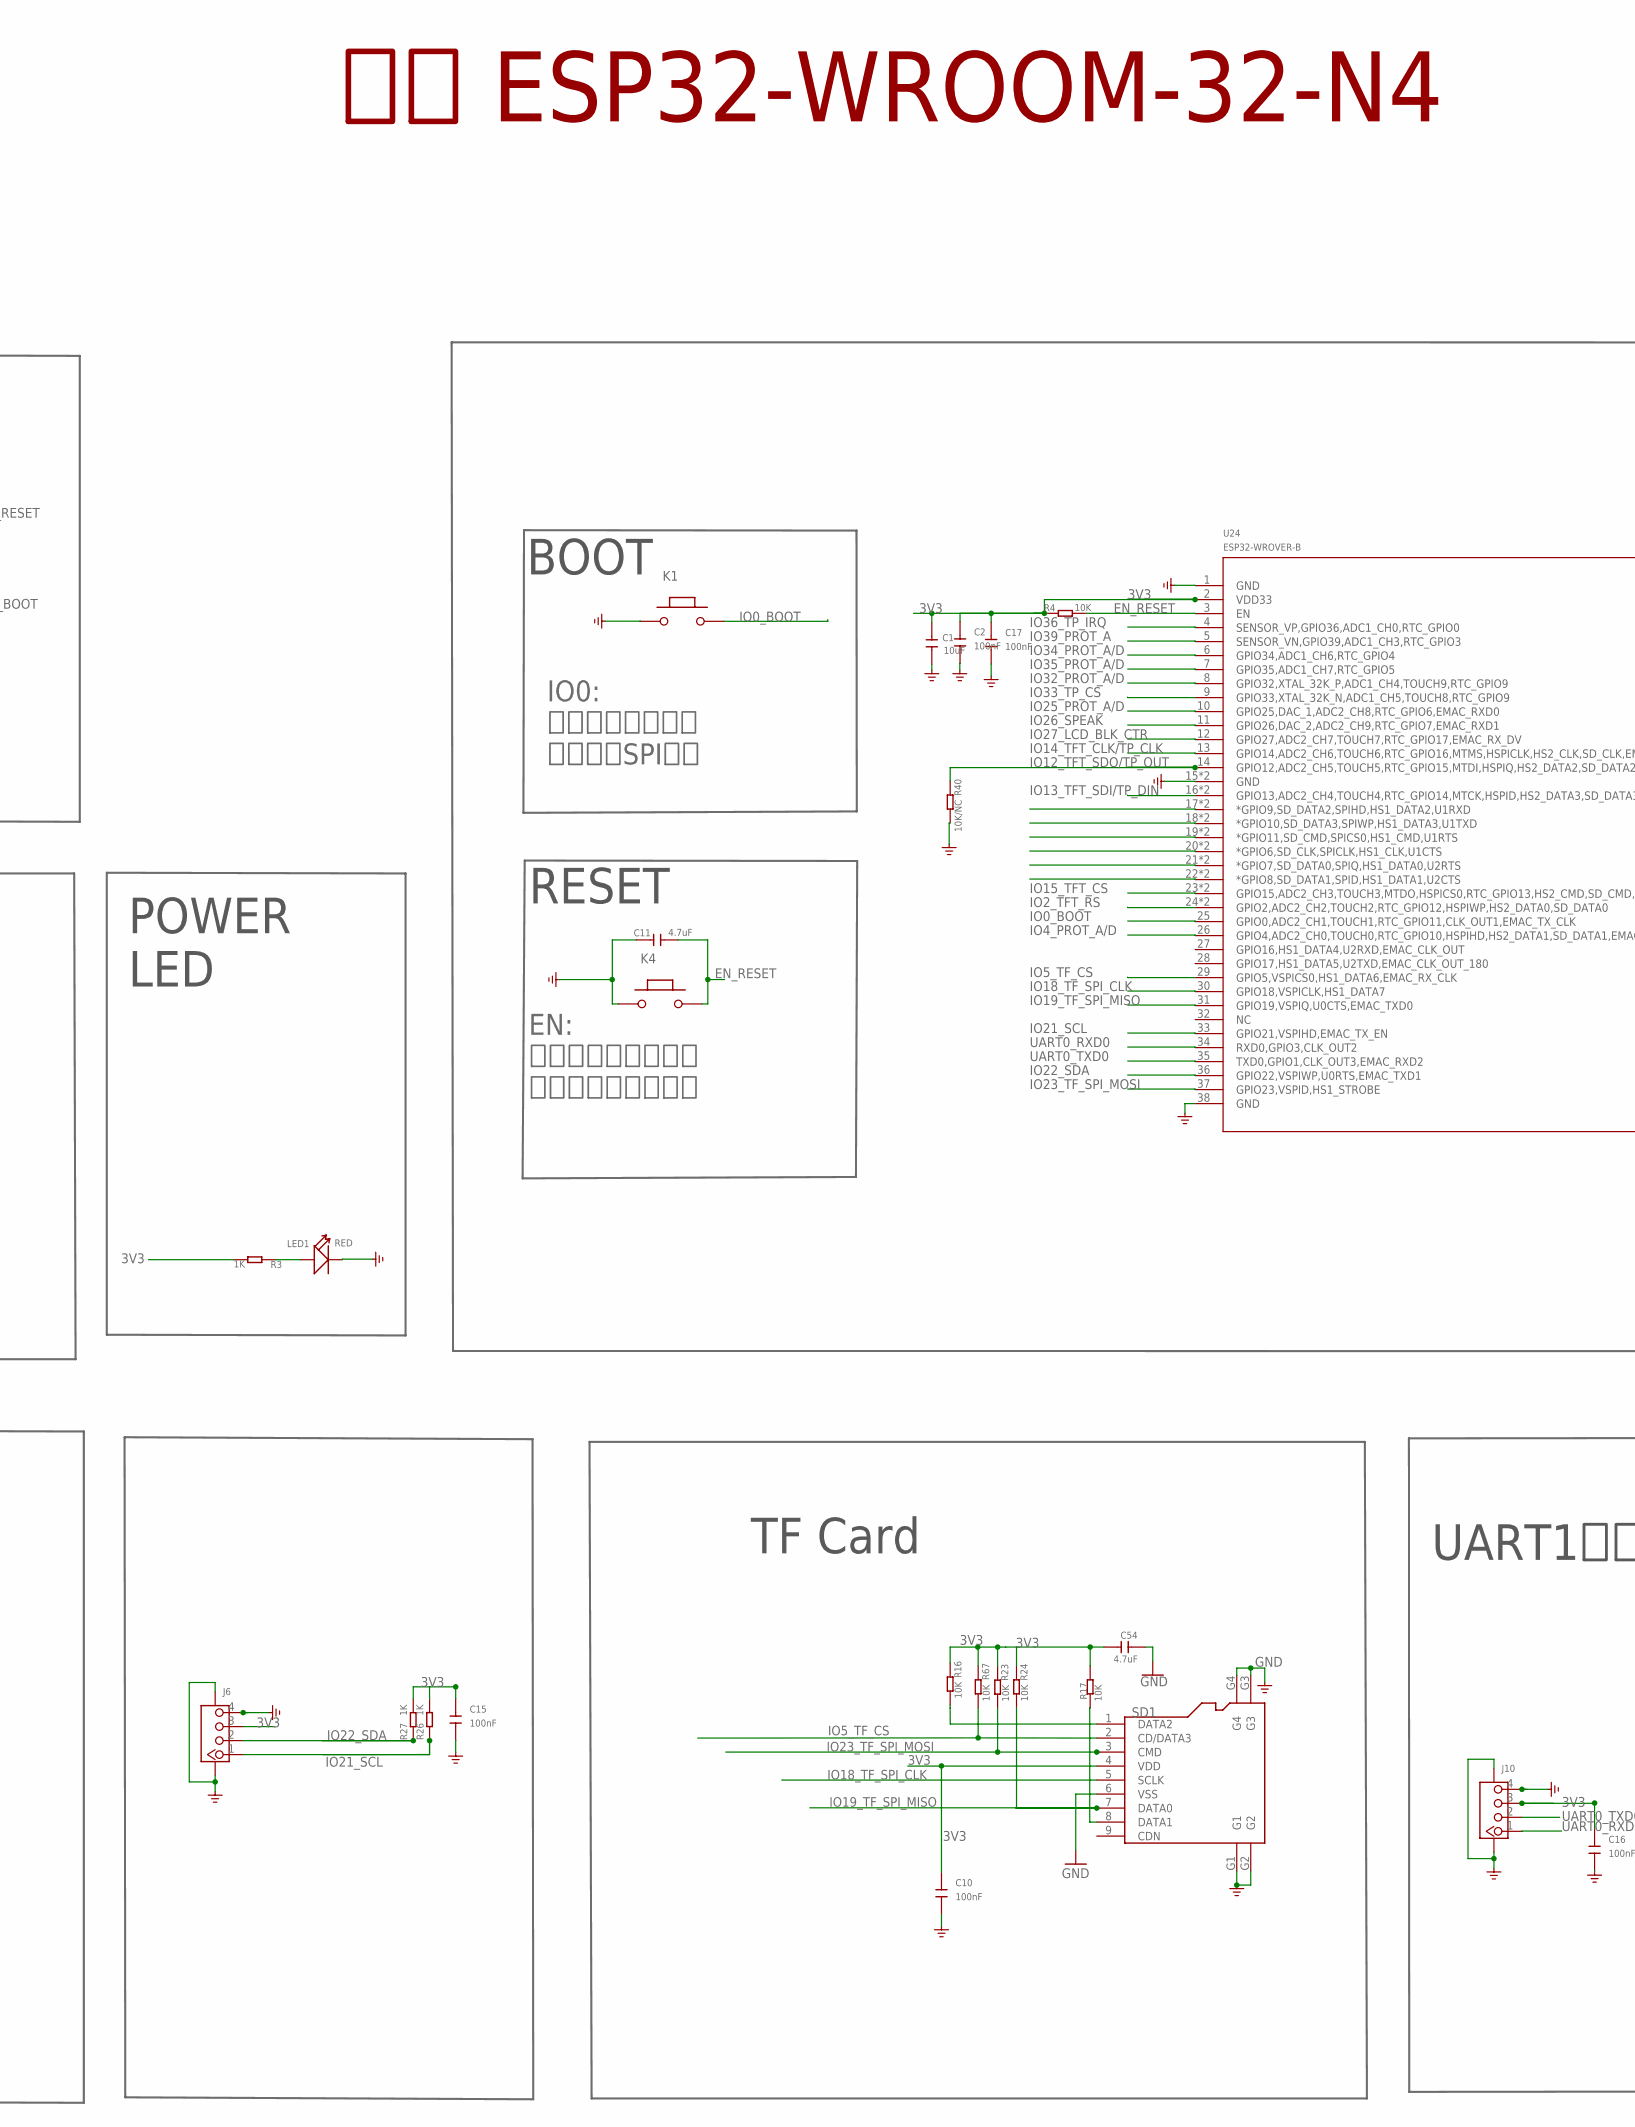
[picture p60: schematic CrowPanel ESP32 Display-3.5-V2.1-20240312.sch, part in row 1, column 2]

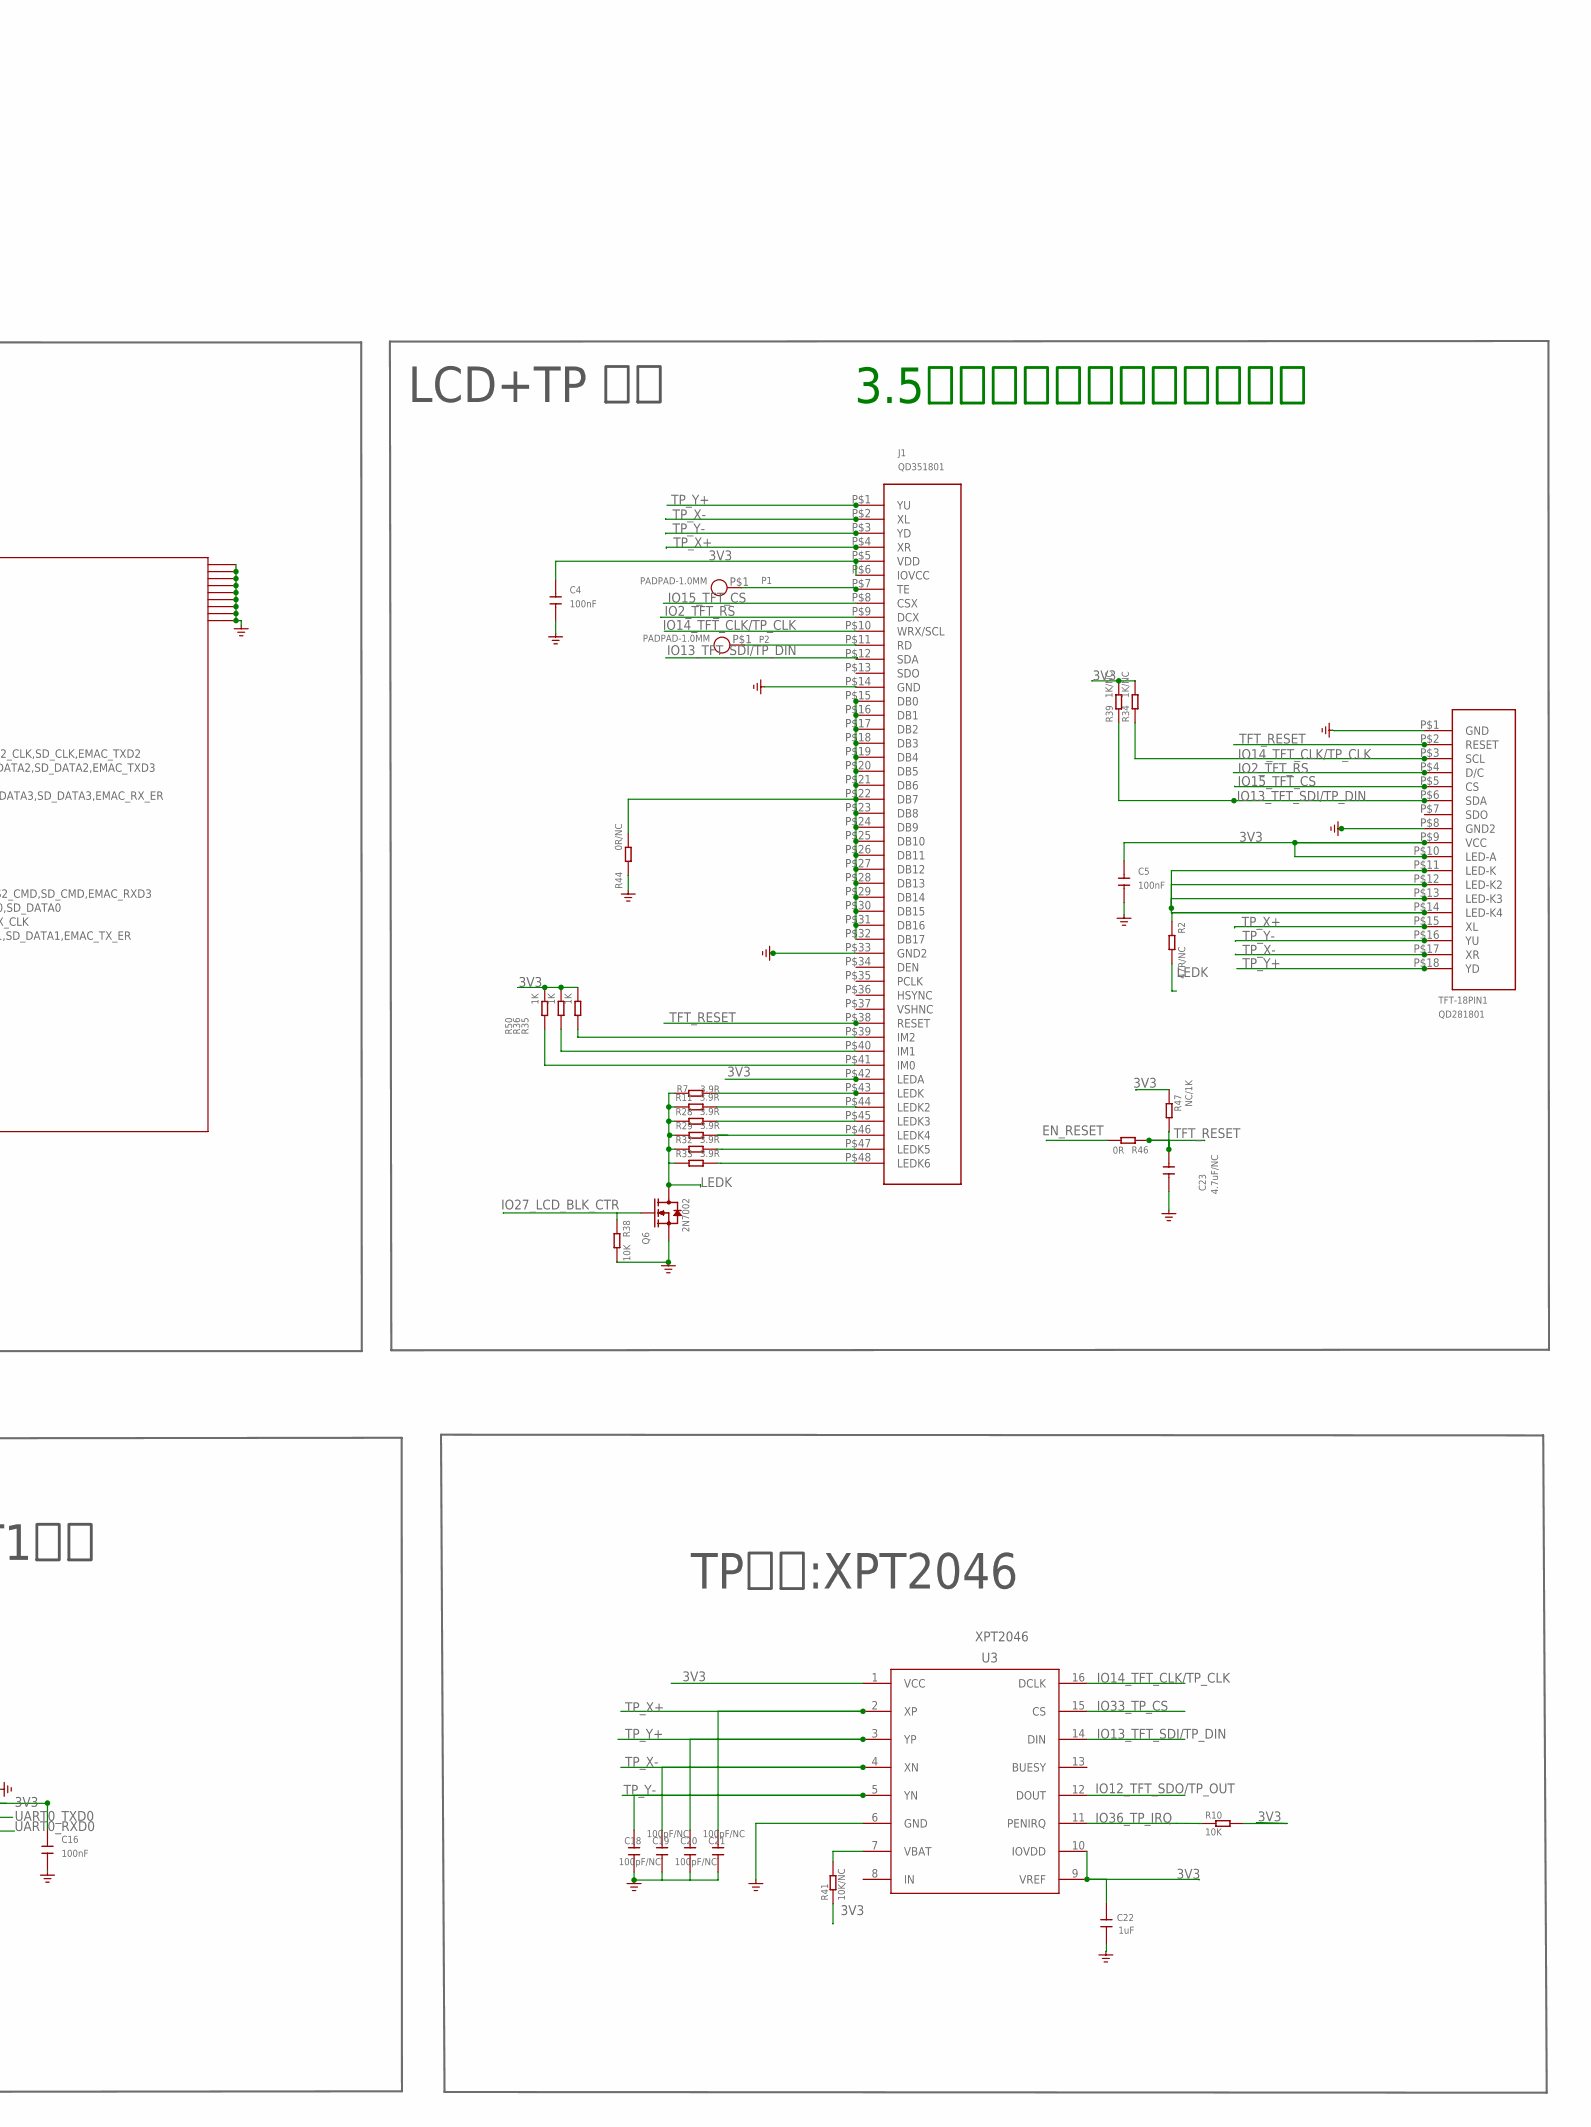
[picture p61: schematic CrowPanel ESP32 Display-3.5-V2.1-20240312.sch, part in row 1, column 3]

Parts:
C1: 10uF; DISCRETE_C0603
C2, C3, C4, C5, C9, C10, C12, C13, C15, C16, C17, C26: 100nF; 0603
C6, C8: 1uF; 0603
C7, C42: 22uF; 0805
C11: 4.7uF; 0603
C14, C22, C53, C55: 1uF; DISCRETE_C0603
C18, C19, C20, C21: 100pF/NC; 0603
C23: 4.7uF/NC; 0603
C46: 1nF; DISCRETE_C0603
C47, C48, C49: 10uF; 0805_S
C50: 100nF; C0603
C51: 100pF; DISCRETE_C0603
C54: 4.7uF; DISCRETE_C0603
D3: S2M/SMB; 214AB
D5: IN5817; DO-214AC
J1: QD351801; QD351801-0.8MM*48
J3: USB_TYPE-C_16PIN3.0USB; KEVIN_3.0TYPEC-SMD
J5, J8: PH2.0WT-2PIN
J6, J7, J10: CONNECTOR_TWIG-4P-2.0-SMD-FEMALE-REINFORCE90D; CONNECTOR_4P-SMD-2.0-90D
K1, K4: BUTTON; 157SW
L4: L-0530; CD54_CD54
LED1: RED; DISCRETE_LED-0603
P1, P2: PADPAD-1.0MM; PAD-1.0MM
Q3: PMOS-3401-4A; SOT-23
Q6: 2N7002; SOT23
Q9, Q10: S9013; SOT23@1
R1, R10, R16, R17, R21, R23, R24, R38, R67: 10K; DISCRETE_R0603
R2: 47R/NC; DISCRETE_R0603
R3, R18, R25, R26, R27, R35, R36, R45, R50, R74, R75: 1K; DISCRETE_R0603
R4: 10K; R0603
R5: 2K; DISCRETE_R0603
R7, R11, R28, R29, R32, R33: 3.9R; DISCRETE_R0603
R8, R9, R71, R72: 22R; DISCRETE_R0603
R12: 4.7K; DISCRETE_R0603
R13, R14: 5.1K; DISCRETE_R0603
R19, R30, R31, R46: 0R; DISCRETE_R0603
R20: 45.3K; DISCRETE_R0603
R22: 22K; DISCRETE_R0603
R34, R39: 1K/NC; DISCRETE_R0603
R37: 68K; DISCRETE_R0603
R40, R41: 10K/NC; DISCRETE_R0603
R44: 0R/NC; DISCRETE_R0603
R47: NC/1K; DISCRETE_R0603
SD1: HOLDER-MICROSD-9P; 9P-SMD-W/-RING
TFT-18PIN1: QD281801; QD241801-18PIN*0.8
U1: RY3420; A_XBJ_SOT23-5
U2: SC8002B; AT24C02_SOP8
U3: XP2046; XP2046-SSOP16
U6: CH340C; SOP-16
U24: ESP32-WROVER-B; ESP32-WROOM-32-N4
U26: 4054A; SOP23-5

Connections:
3.3V: C12.2, C55.2, R31.1, U2.6 (VDD)
3V3: C1.2, C2.2, C3.2, C4.2, C5.2, C7.2, C8.2, C9.2, C10.2, C13.2, C15.2, C16.2, C17.2, C22.2, C26.1, C54.2, J1.P$5 (VDD), J1.P$6 (IOVCC), J1.P$42 (LEDA), J6.3, J7.3, J10.3, L4.2, R3.2, R4.1, R10.2, R16.1, R17.1, R18.2, R20.1, R23.1, R24.1, R25.2, R26.2, R27.2, R31.2, R34.2, R35.2, R36.2, R39.2, R41.1, R47.2, R50.2, R67.1, SD1.4 (VDD), TFT-18PIN1.P$9 (VCC), TFT-18PIN1.P$10 (LED-A), U3.1 (VCC), U3.9 (VREF), U3.10 (IOVDD), U6.4 (V3), U6.16 (VCC), U24.2 (VDD33)
AGND: C12.1, C46.1, C51.1, C53.2, C55.1, J8.P$3, J8.P$4, R30.1, U2.1 (SHUTDOWN), U2.7 (GND)
BAT+: C47.2, C48.2, D5.A, J5.P$1, Q3.3 (D), U26.3 (BAT)
BYPASS_IN+: C53.1, U2.2 (BYPASS), U2.3 (+IN)
D+: J3.A6 (DP1), J3.B6 (DP2), R9.1
D-: J3.A7 (DN1), J3.B7 (DN2), R8.1
DTR: Q10.2 (E), R75.2, U6.13 (DTR#)
EN_RESET: C11.1, K4.2, Q9.3 (C), R4.2, R46.2, U24.3 (EN)
GND: C1.1, C2.1, C3.1, C4.1, C5.1, C6.1, C7.1, C8.1, C9.1, C10.1, C11.2, C13.1, C15.1, C16.1, C17.1, C18.1, C19.1, C20.1, C21.1, C22.1, C23.2, C26.2, C42.1, C47.1, C48.1, C49.1, C50.2, C54.1, J1.P$14 (GND), J1.P$33 (GND2), J3.A1 (GND), J3.A12 (GND), J3.B1 (GND), J3.B12 (GND), J3.P$6, J3.P$7, J3.P$8, J3.P$9, J5.P$2, J5.P$3, J5.P$4, J6.4, J6.SS1, J6.SS2, J7.4, J7.SS1, J7.SS2, J10.4, J10.SS1, J10.SS2, K1.1, K4.1, LED1.-, Q6.2 (S), R1.1, R5.2, R13.1, R14.2, R21.2, R30.2, R38.2, R40.2, R44.1, SD1.6 (VSS), SD1.G1, SD1.G2, SD1.G3, SD1.G4, TFT-18PIN1.P$1 (GND), TFT-18PIN1.P$8 (GND2), U1.2 (GND), U3.6 (GND), U6.1 (GND), U24.1 (GND), U24.15 (GND), U24.15@1 (GND), U24.38 (GND), U24.41 (GND), U24.42 (GND), U24.43 (GND), U24.44 (GND), U24.45 (GND), U24.46 (GND), U24.47 (GND), U24.48 (GND), U24.49 (GND), U26.2 (GND)
IN-: R22.2, R37.1, U2.4 (-IN)
IO0_BOOT: K1.2, Q10.3 (C), U24.25 (GPIO0,ADC2_CH1,TOUCH1,RTC_GPIO11,CLK_OU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)
IO2_TFT_RS: J1.P$9 (DCX), TFT-18PIN1.P$4 (D/C), U24.24 (GPIO2,ADC2_CH2,TOUCH2,RTC_GPIO12,HSPIWP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), U24.24@1 (GPIO2,ADC2_CH2,TOUCH2,RTC_GPIO12,HSPIWP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)
IO4_PROT_A/D: U24.26 (GPIO4,ADC2_CH0,TOUCH0,RTC_GPIO10,HSPIHD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)
IO5_TF_CS: R67.2, SD1.2 (CD/DATA3), U24.29 (GPIO5,VSPICS0,HS1_DATA6,EMAC_RX_CLK)
IO12_TFT_SDO/TP_OUT: R40.1, U3.12 (DOUT), U24.14 (GPIO12,ADC2_CH5,TOUCH5,RTC_GPIO15,MTDI,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)
IO13_TFT_SDI/TP_DIN: J1.P$12 (SDA), R39.1, TFT-18PIN1.P$6 (SDA), U3.14 (DIN), U24.16 (GPIO13,ADC2_CH4,TOUCH4,RTC_GPIO14,MTCK,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), U24.16@1 (GPIO13,ADC2_CH4,TOUCH4,RTC_GPIO14,MTCK,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)
IO14_TFT_CLK/TP_CLK: J1.P$10 (WRX/SCL), R34.1, TFT-18PIN1.P$3 (SCL), U3.16 (DCLK), U24.13 (GPIO14,ADC2_CH6,TOUCH6,RTC_GPIO16,MTMS,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)
IO15_TFT_CS: J1.P$8 (CSX), TFT-18PIN1.P$5 (CS), U24.23 (GPIO15,ADC2_CH3,TOUCH3,MTDO,HSPICS0,RTC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), U24.23@1 (GPIO15,ADC2_CH3,TOUCH3,MTDO,HSPICS0,RTC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)
IO18_TF_SPI_CLK: SD1.5 (SCLK), U24.30 (GPIO18,VSPICLK,HS1_DATA7)
IO19_TF_SPI_MISO: R24.2, SD1.7 (DATA0), U24.31 (GPIO19,VSPIQ,U0CTS,EMAC_TXD0)
IO21_SCL: J6.1, R26.1, U24.33 (GPIO21,VSPIHD,EMAC_TX_EN)
IO22_SDA: J6.2, R27.1, U24.36 (GPIO22,VSPIWP,U0RTS,EMAC_TXD1)
IO23_TF_SPI_MOSI: R23.2, SD1.3 (CMD), U24.37 (GPIO23,VSPID,HS1_STROBE)
IO25_PROT_A/D: J7.1, R18.1, U24.10 (GPIO25,DAC_1,ADC2_CH8,RTC_GPIO6,EMAC_RX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)
IO26_SPEAK: R12.1, U24.11 (GPIO26,DAC_2,ADC2_CH9,RTC_GPIO7,EMAC_RX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)
IO27_LCD_BLK_CTR: Q6.1 (G), R38.1, U24.12 (GPIO27,ADC2_CH7,TOUCH7,RTC_GPIO17,EMAC_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)
IO32_PROT_A/D: J7.2, R25.1, U24.8 (GPIO32,XTAL_32K_P,ADC1_CH4,TOUCH9,RTC_G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)
IO33_TP_CS: U3.15 (CS), U24.9 (GPIO33,XTAL_32K_N,ADC1_CH5,TOUCH8,RTC_G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)
IO34_PROT_A/D: U24.6 (GPIO34,ADC1_CH6,RTC_GPIO4)
IO35_PROT_A/D: U24.7 (GPIO35,ADC1_CH7,RTC_GPIO5)
IO36_TP_IRQ: R10.1, U3.11 (PENIRQ), U24.4 (SENSOR_VP,GPIO36,ADC1_CH0,RTC_GPIO0)
IO39_PROT_A: U24.5 (SENSOR_VN,GPIO39,ADC1_CH3,RTC_GPIO3)
LEDK: Q6.3 (D), R2.2, R7.2, R11.1, R28.1, R29.1, R32.1, R33.1
LEDK1: R2.1, TFT-18PIN1.P$11 (LED-K), TFT-18PIN1.P$12 (LED-K2), TFT-18PIN1.P$13 (LED-K3), TFT-18PIN1.P$14 (LED-K4)
unnamed: LED1.+, R3.1
unnamed: Q9.1 (B), R75.1
unnamed: C46.2, R12.2, R19.1
unnamed: R41.2, U3.7 (VBAT)
unnamed: J1.P$15 (DB0), J1.P$16 (DB1), J1.P$17 (DB2), J1.P$18 (DB3), J1.P$19 (DB4), J1.P$20 (DB5), J1.P$21 (DB6), J1.P$22 (DB7), J1.P$23 (DB8), J1.P$24 (DB9), J1.P$25 (DB10), J1.P$26 (DB11), J1.P$27 (DB12), J1.P$28 (DB13), J1.P$29 (DB14), J1.P$30 (DB15), J1.P$31 (DB16), J1.P$32 (DB17), R44.2
unnamed: J3.B5 (CC2), R14.1
unnamed: J3.A5 (CC1), R13.2
unnamed: J1.P$44 (LEDK2), R11.2
unnamed: J1.P$11 (RD), P2.P$1
unnamed: U24.17 (*GPIO9,SD_DATA2,SPIHD,HS1_DATA2,U1RXD), U24.17@1 (*GPIO9,SD_DATA2,SPIHD,HS1_DATA2,U1RXD)
unnamed: U24.18 (*GPIO10,SD_DATA3,SPIWP,HS1_DATA3,U1TXD), U24.18@1 (*GPIO10,SD_DATA3,SPIWP,HS1_DATA3,U1TXD)
unnamed: J1.P$43 (LEDK), R7.1
unnamed: L4.1, U1.3 (SW)
unnamed: J1.P$39 (IM2), R35.1
unnamed: U24.19 (*GPIO11,SD_CMD,SPICS0,HS1_CMD,U1RTS), U24.19@1 (*GPIO11,SD_CMD,SPICS0,HS1_CMD,U1RTS)
unnamed: J1.P$40 (IM1), R36.1
unnamed: J1.P$41 (IM0), R50.1
unnamed: J1.P$7 (TE), P1.P$1
unnamed: U24.20 (*GPIO6,SD_CLK,SPICLK,HS1_CLK,U1CTS), U24.20@1 (*GPIO6,SD_CLK,SPICLK,HS1_CLK,U1CTS)
unnamed: R20.2, R21.1, U1.5 (FB)
unnamed: Q3.1 (G), R1.2, R45.1
unnamed: R5.1, U26.5 (PROG)
unnamed: U24.21 (*GPIO7,SD_DATA0,SPIQ,HS1_DATA0,U2RTS), U24.21@1 (*GPIO7,SD_DATA0,SPIQ,HS1_DATA0,U2RTS)
unnamed: U24.22 (*GPIO8,SD_DATA1,SPID,HS1_DATA1,U2CTS), U24.22@1 (*GPIO8,SD_DATA1,SPID,HS1_DATA1,U2CTS)
unnamed: C14.1, C51.2, R19.2
unnamed: C14.2, R22.1
unnamed: J1.P$45 (LEDK3), R28.2
unnamed: J1.P$46 (LEDK4), R29.2
unnamed: J1.P$47 (LEDK5), R32.2
unnamed: J1.P$48 (LEDK6), R33.2
unnamed: Q10.1 (B), R74.1
unnamed: R72.2, U6.2 (TXD)
unnamed: R71.2, U6.3 (RXD)
unnamed: R16.2, SD1.1 (DATA2)
unnamed: R17.2, SD1.8 (DATA1)
RTS: Q9.2 (E), R74.2, U6.14 (RTS#)
TFT_RESET: C23.1, J1.P$38 (RESET), R46.1, R47.1, TFT-18PIN1.P$2 (RESET)
TP_X+: C21.2, J1.P$4 (XR), TFT-18PIN1.P$15 (XL), U3.2 (XP)
TP_X-: C19.2, J1.P$2 (XL), TFT-18PIN1.P$17 (XR), U3.4 (XN)
TP_Y+: C20.2, J1.P$1 (YU), TFT-18PIN1.P$18 (YD), U3.3 (YP)
TP_Y-: C18.2, J1.P$3 (YD), TFT-18PIN1.P$16 (YU), U3.5 (YN)
UART0_RXD0: J10.1, R72.1, U24.34 (RXD0,GPIO3,CLK_OUT2)
UART0_TXD0: J10.2, R71.1, U24.35 (TXD0,GPIO1,CLK_OUT3,EMAC_RXD2)
USB_D+: R9.2, U6.5 (UD+)
USB_D-: R8.2, U6.6 (UD-)
VBUS: C49.2, C50.1, D3.1 (+), J3.A4 (VBUS), J3.A9 (VBUS), J3.B4 (VBUS), J3.B9 (VBUS), R45.2, U26.4 (VCC)
VIN: C6.2, C42.2, D3.2 (-), D5.C, Q3.2 (S), U1.1 (EN), U1.4 (VIN)
VO1: J8.P$1, R37.2, U2.5 (VO1)
VO2: J8.P$2, U2.8 (VO2)

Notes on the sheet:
Vout=0.6*(R20/R21 +1)=3.3V
系统3.3V电源
UART1接口
主控 ESP32-WROOM-32-N4
USB type-c座子
电池及控制电路
IO0: 低电平：下载启动 高电平：SPI启动
EN: 高电平：芯片使能； 低电平：芯片关闭。
USB转串口
SPEAK 功放
TF Card
BOOT
RESET
POWER LED
LCD+TP 接口
TP驱动:XPT2046
3.5寸屏兼容，其他型号不需要
HM3416H更换为RY3420
500mA
BAT

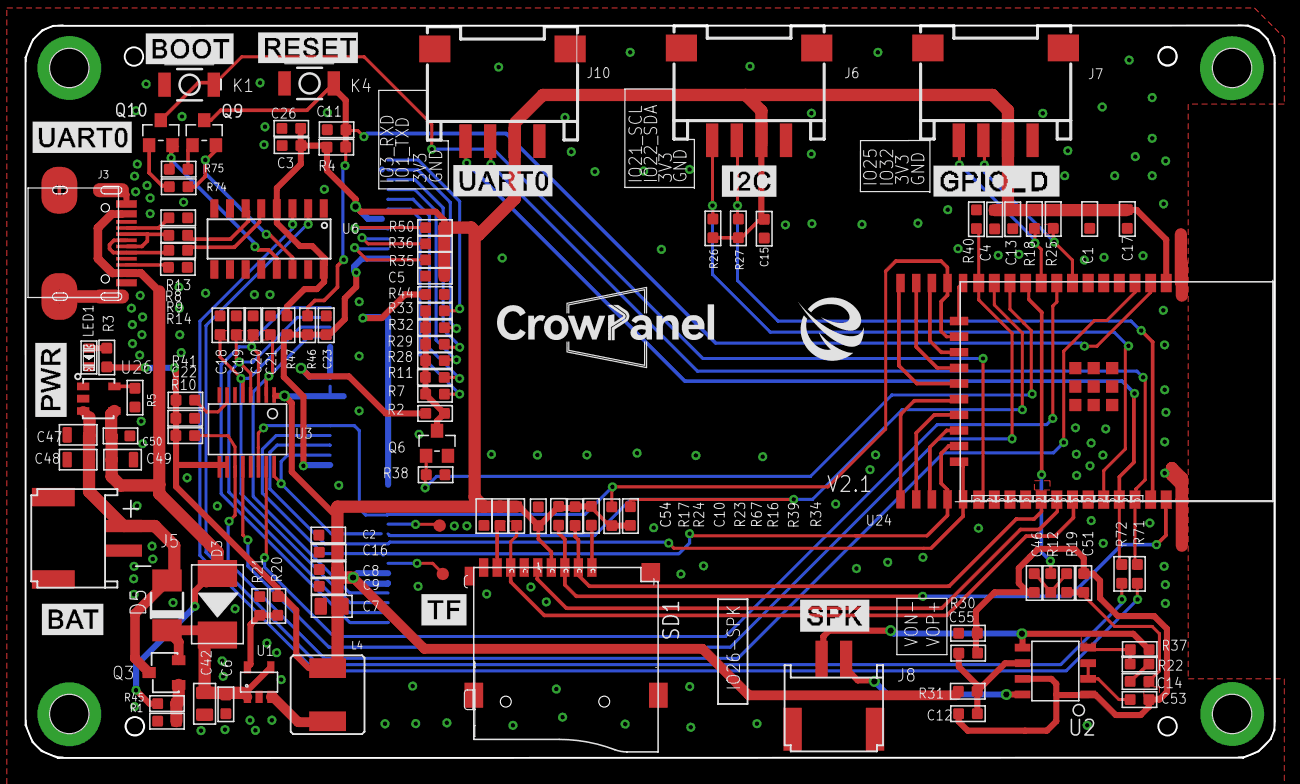
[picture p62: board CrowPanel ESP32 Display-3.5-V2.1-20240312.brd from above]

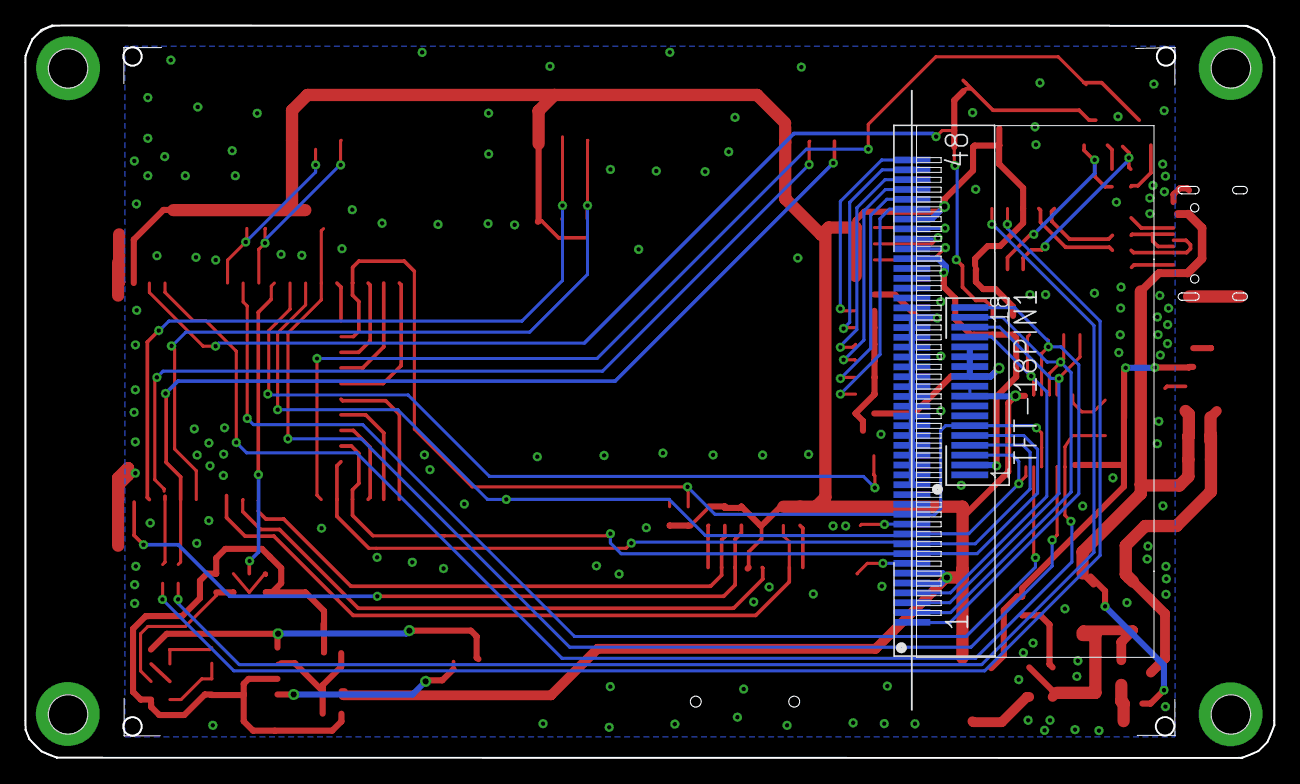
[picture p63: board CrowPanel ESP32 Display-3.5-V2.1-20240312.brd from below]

Board: 2 copper layers, 101.5 x 59.5 mm, 114 parts (2 on the bottom side), 80 nets.

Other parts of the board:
U$2: 3.5底板框
U$3, U$28: LOGE-2.0
U$30: ELECROW-NEW

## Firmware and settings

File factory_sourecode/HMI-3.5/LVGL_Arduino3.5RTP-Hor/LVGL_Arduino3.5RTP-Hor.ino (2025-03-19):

#include <lvgl.h>
#include <TFT_eSPI.h>
#include <demos/lv_demos.h>
#include <examples/lv_examples.h>

#include <Arduino.h>
#include <U8g2lib.h>
//#ifdef U8X8_HAVE_HW_I2C
#include <Wire.h>
#include <SPI.h>
#include <SD.h>
#include <FS.h>
//#endif
#include <WiFi.h>
#include "MusicDefinitions.h"
#include "SoundData.h"
#include "XT_DAC_Audio.h"

#include "BLEDevice.h"              //BLE驱动库
#include "BLEServer.h"              //BLE蓝牙服务器库
#include "BLEUtils.h"               //BLE实用程序库
#include "BLE2902.h"                //特征添加描述符库
#include <BLECharacteristic.h>      //BLE特征函数库
BLEAdvertising* pAdvertising = NULL;
BLEServer* pServer = NULL;
BLEService *pService = NULL;
BLECharacteristic* pCharacteristic = NULL;
#define bleServerName "Wizee-Series-3.5"  //BLE服务器的名称
#define SERVICE_UUID "6479571c-2e6d-4b34-abe9-c35116712345"  //服务的UUID
#define CHARACTERISTIC_UUID "826f072d-f87c-4ae6-a416-6ffdcaa02d73"

const char *ssid = "elecrow888"; //你的网络名称
const char *password = "elecrow2014"; //你的网络密码
char buf[100] = {};
int bufindex = 0;
int wifi_close_flag = 0;
char *info[100] = {};
int wifi_flag = 0;
int i = 0;
int home_flag = 0;
int touch_flag = 0;

U8G2_SSD1306_128X32_UNIVISION_F_SW_I2C  u8g2(U8G2_R0, /* clock=*/ 21, /* data=*/ 22, /* reset=*/ U8X8_PIN_NONE);   // Adafruit Feather ESP8266/32u4 Boards + FeatherWing OLED

//UI
#include "ui.h"
#include <Ticker.h>          //Call the ticker. H Library
Ticker ticker1;
static int first_flag = 0;
extern int zero_clean;
extern int goto_widget_flag;
extern int bar_flag;
extern lv_obj_t * ui_MENU;
extern lv_obj_t * ui_TOUCH;
extern lv_obj_t * ui_JIAOZHUN;
extern lv_obj_t * ui_Label2;
static lv_obj_t * ui_Label;//TOUCH界面label
static lv_obj_t * ui_Label3;//TOUCH界面label3
static lv_obj_t * ui_Labe2;//Menu界面进度条label
static lv_obj_t * bar;//Menu界面进度条
static int val = 100;

//3.5
#define SD_MOSI 23
#define SD_MISO 19
#define SD_SCK 18
#define SD_CS 5

//SPEAK
// Data for the melody. Note followed by optional change in playing length in 1/4 beats. See documentation for more details
int8_t PROGMEM TwinkleTwinkle[] = {
  NOTE_C5, NOTE_C5, NOTE_G5, NOTE_G5, NOTE_A5, NOTE_A5, NOTE_G5, BEAT_2,
  NOTE_F5, NOTE_F5, NOTE_E5, NOTE_E5, NOTE_D5, NOTE_D5, NOTE_C5, BEAT_2,
  NOTE_G5, NOTE_G5, NOTE_F5, NOTE_F5, NOTE_E5, NOTE_E5, NOTE_D5, BEAT_2,
  NOTE_G5, NOTE_G5, NOTE_F5, NOTE_F5, NOTE_E5, NOTE_E5, NOTE_D5, BEAT_2,
  NOTE_C5, NOTE_C5, NOTE_G5, NOTE_G5, NOTE_A5, NOTE_A5, NOTE_G5, BEAT_2,
  NOTE_F5, NOTE_F5, NOTE_E5, NOTE_E5, NOTE_D5, NOTE_D5, NOTE_C5, BEAT_4,
  NOTE_SILENCE, BEAT_5, SCORE_END
};
XT_DAC_Audio_Class DacAudio(26, 0);         // Create the main player class object. Use GPIO 25, one of the 2 DAC pins and timer 0
XT_Wav_Class ForceWithYou(Force);           // create WAV object and pass in the WAV data
XT_MusicScore_Class Music(TwinkleTwinkle, TEMPO_ALLEGRO, INSTRUMENT_PIANO); // The music score object, pass in the Music data
XT_Sequence_Class Sequence;                // The sequence object, you add your sounds above to this object (see setup below)

/*更改屏幕分辨率*/
static const uint16_t screenWidth  = 480;
static const uint16_t screenHeight = 320;

static lv_disp_draw_buf_t draw_buf;
static lv_color_t buf1[ screenWidth * screenHeight / 13 ];

TFT_eSPI lcd = TFT_eSPI(); /* TFT实例 */

bool connected_state = false;   //创建设备连接标识符

class MyServerCallbacks: public BLEServerCallbacks  //创建连接和断开调用类
{
    void onConnect(BLEServer *pServer)//开始连接函数
    {
      connected_state = true;   //设备正确连接
    }
    void onDisconnect(BLEServer *pServer)//断开连接函数
    {
      connected_state = false;  //设备连接错误
    }

};

//_______________________
/* 显示器刷新 */
void my_disp_flush( lv_disp_drv_t *disp, const lv_area_t *area, lv_color_t *color_p )
{
  uint32_t w = ( area->x2 - area->x1 + 1 );
  uint32_t h = ( area->y2 - area->y1 + 1 );

  lcd.startWrite();
  lcd.setAddrWindow( area->x1, area->y1, w, h );
  lcd.pushColors( ( uint16_t * )&color_p->full, w * h, true );
  lcd.endWrite();

  lv_disp_flush_ready( disp );
}

uint16_t touchX, touchY;
/*读取触摸板*/
void my_touchpad_read( lv_indev_drv_t * indev_driver, lv_indev_data_t * data )
{

  bool touched = lcd.getTouch( &touchX, &touchY, 600);
  if ( !touched )
  {
    data->state = LV_INDEV_STATE_REL;
  }
  else
  {
    data->state = LV_INDEV_STATE_PR;

    /*设置坐标*/
    data->point.x = touchX;
    data->point.y = touchY;

    Serial.print( "Data x " );
    Serial.println( touchX );

    Serial.print( "Data y " );
    Serial.println( touchY );
  }
}


unsigned char buffer[256]; // buffer array for data recieve over serial port
int count = 0;   // counter for buffer array
void clearBufferArray()              // function to clear buffer array
{
  for (int i = 0; i < count; i++)
  {
    buffer[i] = NULL; // clear all index of array with command NULL
  }
}

char CloseData;
int NO_Test_Flag = 0;
int Test_Flag = 0;
int Close_Flag = 0;
uint16_t calData[5] = { 353, 3568, 269, 3491, 7  };
void callback1()  //Callback function
{
  if (bar_flag == 6)
  {
    if (val > 1)
    {
      val--;
      lv_bar_set_value(bar, val, LV_ANIM_OFF);
      lv_label_set_text_fmt(ui_Labe2, "%d %%", val);
    }
    else
    {
      lv_obj_clear_flag(ui_touch, LV_OBJ_FLAG_CLICKABLE);
      lv_label_set_text(ui_Labe2, "Loading");
      delay(150);
      val = 100;
      bar_flag = 0; //停止进度条标志
      goto_widget_flag = 1; //进入widget标志

    }
  }
}



void setup()
{
  Serial.begin( 115200 ); /*初始化串口*/
  Serial2.begin( 115200 ); /*初始化串口2*/

  //IO口引脚
  pinMode(25, OUTPUT);
  digitalWrite(25, LOW);


  //OLED
  //  u8g2.begin();
  //  u8g2.enableUTF8Print();        // enable UTF8 support for the Arduino print() function
  //  u8g2.setFont(u8g2_font_ncenB14_tr);
  //  u8g2.setFontDirection(0);
  //  for (int i = 128; i > -78; i -= 20)
  //  {
  //    u8g2.firstPage();
  //    do {
  //      u8g2.drawStr(i, 25, "ELECROW");
  //      delay(2);
  //    } while ( u8g2.nextPage() );
  //  }

  //lvgl初始化
  lv_init();

  //LCD初始化
  lcd.begin();          /*初始化*/
  lcd.setRotation(1); /* 旋转 */
  lcd.fillScreen(TFT_BLACK);
  delay(100);
  //背光引脚
  pinMode(27, OUTPUT);
  digitalWrite(27, HIGH);
  //  lcd.fillScreen(TFT_RED);
  //  delay(500);
  //  lcd.fillScreen(TFT_GREEN);
  //  delay(500);
  //  lcd.fillScreen(TFT_BLUE);
  //  delay(500);
  //  lcd.fillScreen(TFT_BLACK);
  //  delay(500);

  //SD卡
  //  SPI.begin(SD_SCK, SD_MISO, SD_MOSI);
  //  delay(100);
  //  if (SD_init() == 1)
  //  {
  //    Serial.println("SD卡初始化失败！");
  //  }
  //  else
  //    Serial.println("SD卡初始化成功");
  //  delay(2000);

  //校准模式。一是四角定位、二是直接输入模拟数值直接定位
  //屏幕校准
  //  touch_calibrate();
  lcd.setTouch(calData);


  lv_disp_draw_buf_init( &draw_buf, buf1, NULL, screenWidth * screenHeight / 13 );

  /*初始化显示*/
  static lv_disp_drv_t disp_drv;
  lv_disp_drv_init( &disp_drv );
  /*将以下行更改为显示分辨率*/
  disp_drv.hor_res = screenWidth;
  disp_drv.ver_res = screenHeight;
  disp_drv.flush_cb = my_disp_flush;
  disp_drv.draw_buf = &draw_buf;
  lv_disp_drv_register( &disp_drv );

  /*初始化（虚拟）输入设备驱动程序*/
  static lv_indev_drv_t indev_drv;
  lv_indev_drv_init( &indev_drv );
  indev_drv.type = LV_INDEV_TYPE_POINTER;
  indev_drv.read_cb = my_touchpad_read;
  lv_indev_drv_register( &indev_drv );

  ui_init();//开机UI界面
  while (1)
  {
    if (goto_widget_flag == 1)//进入widget
    {
      if (ticker1.active() == true)
      {
        ticker1.detach();
      }
      goto_widget_flag = 0;
      delay(300);
      break;
    }

    if (goto_widget_flag == 3)//进入触摸界面，先把进度条线程关闭
    {
      bar_flag = 0; //停止进度条标志
      if (ticker1.active() == true)
      {
        ticker1.detach();
      }
      if (first_flag == 0 || first_flag == 1)
      {
        label_xy();
        first_flag = 2;
      }
      if (zero_clean == 1)
      {
        touchX = 0;
        touchY = 0;
        zero_clean = 0;
      }
      lv_label_set_text(ui_Label, "Touch Adjust:");
      lv_label_set_text_fmt(ui_Label3, "%d  %d", touchX, touchY); //显示触摸信息
    }

    if (goto_widget_flag == 4)//触摸界面返回到Menu界面,使进度条加满
    {
      val = 100;
      delay(100);
      ticker1.attach_ms(35, callback1);//每35ms调用callback1
      goto_widget_flag = 0;
    }

    if (goto_widget_flag == 5) //触发校准信号
    {
      lv_scr_load_anim(ui_touch_calibrate, LV_SCR_LOAD_ANIM_NONE, 0, 0, false);
      lv_timer_handler();
      lv_timer_handler();
      delay(100);
      touch_calibrate();//触摸校准
      lcd.setTouch( calData );
      lv_scr_load_anim(ui_TOUCH, LV_SCR_LOAD_ANIM_NONE, 0, 0, false);
      lv_timer_handler();
      delay(100);
      goto_widget_flag = 3; //进入触摸界面标志
      touchX = 0;
      touchY = 0;
    }

    if (bar_flag == 6)//刚开机进入Menu界面时运行进度条一次，之后就不再运行
    {
      if (first_flag == 0)
      {
        lv_example_bar();
        ticker1.attach_ms(35, callback1);//每35ms调用callback1
        first_flag = 1;
      }
    }

    lv_timer_handler();
  }


  lcd.fillScreen(TFT_BLACK);
  lv_demo_widgets();//主UI界面
  Serial.println( "Setup done" );
}

void loop()
{

  while (NO_Test_Flag == 0)
  {
    lv_timer_handler();
    delay( 5 );
    CloseData = Serial.read();
    if (CloseData == 'b')  //Exit
    {
      NO_Test_Flag = 1;
      Test_Flag = 1;
      lcd.fillScreen(TFT_BLACK);
      Serial.println("进入测试程序");
      WiFi.disconnect();
      break;
    }
  }

  //*********************************测试程序***************************************
  //*********************************测试程序***************************************
  //*********************************测试程序***************************************
  while (Test_Flag == 1)
  {
    Ce_shi();
  }
  ESP.restart();
}


//触摸Label控件
void label_xy()
{
  ui_Label = lv_label_create(ui_TOUCH);
  lv_obj_enable_style_refresh(true);
  lv_obj_set_width(ui_Label, LV_SIZE_CONTENT);   /// 1
  lv_obj_set_height(ui_Label, LV_SIZE_CONTENT);    /// 1
  lv_obj_set_x(ui_Label, -35);
  lv_obj_set_y(ui_Label, -60);
  lv_obj_set_align(ui_Label, LV_ALIGN_CENTER);
  lv_obj_set_style_text_color(ui_Label, lv_color_hex(0xFF0000), LV_PART_MAIN | LV_STATE_DEFAULT);
  lv_obj_set_style_text_opa(ui_Label, 255, LV_PART_MAIN | LV_STATE_DEFAULT);
  lv_obj_set_style_text_font(ui_Label, &lv_font_montserrat_16, LV_PART_MAIN | LV_STATE_DEFAULT);

  ui_Label3 = lv_label_create(ui_TOUCH);
  lv_obj_enable_style_refresh(true);
  lv_obj_set_width(ui_Label3, LV_SIZE_CONTENT);   /// 1
  lv_obj_set_height(ui_Label3, LV_SIZE_CONTENT);    /// 1
  lv_obj_set_x(ui_Label3, 65);
  lv_obj_set_y(ui_Label3, -60);
  lv_obj_set_align(ui_Label3, LV_ALIGN_CENTER);
  lv_obj_set_style_text_color(ui_Label3, lv_color_hex(0x00FF00), LV_PART_MAIN | LV_STATE_DEFAULT);
  lv_obj_set_style_text_opa(ui_Label3, 255, LV_PART_MAIN | LV_STATE_DEFAULT);
  lv_obj_set_style_text_font(ui_Label3, &lv_font_montserrat_16, LV_PART_MAIN | LV_STATE_DEFAULT);
}

//进度条控件
void lv_example_bar(void)
{
  //////////////////////////////
  bar = lv_bar_create(ui_MENU);
  lv_bar_set_value(bar, 0, LV_ANIM_OFF);
  lv_obj_set_width(bar, 300);
  lv_obj_set_height(bar, 20);
  lv_obj_set_x(bar, 0);
  lv_obj_set_y(bar, 120);
  lv_obj_set_align(bar, LV_ALIGN_CENTER);
  lv_obj_set_style_bg_img_src(bar, &ui_img_bar_480_01_png, LV_PART_MAIN | LV_STATE_DEFAULT);

  lv_obj_set_style_bg_img_src(bar, &ui_img_bar_480_02_png, LV_PART_INDICATOR | LV_STATE_DEFAULT);
  lv_obj_set_style_outline_color(bar, lv_color_hex(0x2D8812), LV_PART_INDICATOR | LV_STATE_DEFAULT);
  lv_obj_set_style_outline_opa(bar, 255, LV_PART_INDICATOR | LV_STATE_DEFAULT);
  //////////////////////
  ui_Labe2 = lv_label_create(bar);//创建标签
  lv_obj_set_style_text_color(ui_Labe2, lv_color_hex(0x09BEFB), LV_STATE_DEFAULT);
  lv_label_set_text(ui_Labe2, "0%");
  lv_obj_center(ui_Labe2);
}


//设置黑色背景
void Home_Page_Create(void)
{
  static lv_style_t style;                  //创建样式
  lv_style_init(&style);                    //初始化样式

  lv_obj_t* bgk;
  bgk = lv_obj_create(lv_scr_act());//创建对象
  lv_obj_set_style_bg_color(bgk, lv_color_hex(0x000000 ), LV_STATE_DEFAULT); // obj背景色设成黄色

  lv_style_set_border_color(&style, lv_palette_main(LV_PALETTE_NONE)); //设置外框颜色
  lv_obj_add_style(bgk, &style, 0);         //将样式添加到文字对象中
  lv_obj_set_size(bgk, 480, 320);             // 设置到屏幕大小

}

void Ce_shi() {
  char serialData = Serial.read();
  switch (serialData) {
    case 'R':
      Close_Flag = 1;
      //      WiFi.disconnect();//断开连接
      lcd.fillScreen(TFT_BLACK);
      Serial.println("红屏");
      while (Close_Flag == 1)
      {
        lcd.fillScreen(TFT_RED);
        CloseData = Serial.read();
        if (CloseData == 'I')  //Exit
        {
          Close_Flag = 0;
          lcd.fillScreen(TFT_BLACK);
          Serial.println("退出红屏");
          break;
        }
      }
      break;

    case 'G':
      Close_Flag = 1;
      lcd.fillScreen(TFT_BLACK);
      Serial.println("绿屏");
      while (Close_Flag == 1)
      {
        lcd.fillScreen(TFT_GREEN);
        CloseData = Serial.read();
        if (CloseData == 'I')  //Exit
        {
          Close_Flag = 0;
          lcd.fillScreen(TFT_BLACK);
          Serial.println("退出绿屏");
          break;
        }
      }
      break;

    case 'B':
      Close_Flag = 1;
      lcd.fillScreen(TFT_BLACK);
      Serial.println("蓝屏");
      while (Close_Flag == 1)
      {
        lcd.fillScreen(TFT_BLUE);
        CloseData = Serial.read();
        if (CloseData == 'I')  //Exit
        {
          Close_Flag = 0;
          lcd.fillScreen(TFT_BLACK);
          Serial.println("退出蓝屏");
          break;
        }
      }
      break;

    case 'S':
      Close_Flag = 1;
      lcd.fillScreen(TFT_BLACK);
      lcd.setTextFont(1);
      SPI.end();
      Serial.println("TF卡初始化");
      SPI.begin(SD_SCK, SD_MISO, SD_MOSI, SD_CS);
      SD_init();
      while (Close_Flag == 1)
      {
        CloseData = Serial.read();
        if (CloseData == 'I')  //Exit
        {
          Close_Flag = 0;
          lcd.fillScreen(TFT_BLACK);
          Serial.println("退出TF卡初始化");
          SPI.end();
          SPI.begin(14, 12, 13, 33);//触摸引脚
          break;
        }
      }
      break;

    case 'T':
      Close_Flag = 1;
      lcd.fillScreen(TFT_BLACK);
      Serial.println("触摸屏");
      delay(100);
      touch_flag = 0;
      lcd.setCursor(70, 70, 4);
      lcd.printf("Please Touch");
      Serial.println("TOUCH");
      delay(100);
      while (Close_Flag == 1)
      {
        uint16_t x, y;
        if (touch_flag < 3)
        {
          if (lcd.getTouch(&x, &y))
          {
            if (x > 0 && x < 70 && y > 0 && y < 70 && touch_flag == 0)
            {
              lcd.setCursor(140, 120, 4);
              lcd.printf("               ");
              lcd.setCursor(140, 150, 4);
              lcd.printf("               ");
              lcd.setCursor(120, 120, 4);
              lcd.printf("x: %i     ", x);
              lcd.setCursor(120, 150, 4);
              lcd.printf("y: %i    ", y);
              Serial.print( "Data x " );
              Serial.println( x );
              Serial.print( "Data y " );
              Serial.println( y );
              touch_flag = 1;
            }
            if (x > 410 && x < 480 && y > 250 && y < 320 && touch_flag == 1)
            {
              lcd.setCursor(140, 120, 4);
              lcd.printf("               ");
              lcd.setCursor(140, 150, 4);
              lcd.printf("               ");
              lcd.setCursor(120, 120, 4);
              lcd.printf("x: %i     ", x);
              lcd.setCursor(120, 150, 4);
              lcd.printf("y: %i    ", y);
              Serial.print( "Data x " );
              Serial.println( x );
              Serial.print( "Data y " );
              Serial.println( y );
              touch_flag = 3;
              Serial.println("OVER");
              delay(100);
              Serial.println("OVER");
            }
            if (x > 0 && x < 4000 && y > 0 && y < 4000)
            {
              lcd.setCursor(140, 120, 4);
              lcd.printf("               ");
              lcd.setCursor(140, 150, 4);
              lcd.printf("               ");
              lcd.setCursor(120, 120, 4);
              lcd.printf("x: %i     ", x);
              lcd.setCursor(120, 150, 4);
              lcd.printf("y: %i    ", y);
              Serial.print( "Data x " );
              Serial.println( x );
              Serial.print( "Data y " );
              Serial.println( y );
            }
            CloseData = Serial.read();
            if (CloseData == 'I')  //Exit
            {
              Close_Flag = 0;
              touch_flag = 0;
              lcd.fillScreen(TFT_BLACK);
              break;
            }
            delay(80);
          }
        }
        if (touch_flag == 3)
        {
          Serial.println("OVER");
          if (lcd.getTouch(&x, &y))
          {
            lcd.fillScreen(TFT_BLACK);
            if (x > 0 && x < 4000 && y > 0 && y < 4000)
            {
              lcd.setCursor(140, 120, 4);
              lcd.printf("               ");
              lcd.setCursor(140, 150, 4);
              lcd.printf("               ");
              lcd.setCursor(120, 120, 4);
              lcd.printf("x: %i     ", x);
              lcd.setCursor(120, 150, 4);
              lcd.printf("y: %i    ", y);
              Serial.print( "Data x " );
              Serial.println( x );
              Serial.print( "Data y " );
              Serial.println( y );
            }
          }
          delay(80);
        }
        CloseData = Serial.read();
        if (CloseData == 'I')  //Exit
        {
          Close_Flag = 0;
          lcd.fillScreen(TFT_BLACK);
          Serial.println("退出触摸屏");
          break;
        }
      }
      break;

    case 'L':
      Close_Flag = 1;
      Serial.println("IO口测试");
      lcd.fillScreen(TFT_BLACK);
      lcd.setCursor(50, 120, 4);
      lcd.printf("IO port output testing");
      while (Close_Flag == 1)
      {
        digitalWrite(25, HIGH);//拉高电平开灯
        CloseData = Serial.read();
        if (CloseData == 'I')  //Exit
        {
          Close_Flag = 0;
          digitalWrite(25, LOW);
          lcd.fillScreen(TFT_BLACK);
          Serial.println("退出IO口测试");
          break;
        }
      }
      break;

    case 'i':
      Close_Flag = 1;
      u8g2.begin();
      u8g2.enableUTF8Print();        // enable UTF8 support for the Arduino print() function
      u8g2.setFont(u8g2_font_ncenB14_tr);
      u8g2.setFontDirection(0);
      Serial.println("IIC");
      lcd.fillScreen(TFT_BLACK);
      lcd.setCursor(100, 120, 4);
      lcd.printf("IIC testing");
      while (Close_Flag == 1)
      {
        for (int i = 128; i > -90; i -= 20)
        {
          u8g2.firstPage();
          do {
            u8g2.drawStr(i, 25, "ELECROW");
            delay(2);
            CloseData = Serial.read();
            if (CloseData == 'I')  //Exit
            {   
              Close_Flag = 0;
              lcd.fillScreen(TFT_BLACK);
              Serial.println("退出IIC");
              break;
            }
          } while ( u8g2.nextPage() );
        }
        CloseData = Serial.read();
        if (CloseData == 'I')  //Exit
        {
          Close_Flag = 0;
          lcd.fillScreen(TFT_BLACK);
          Serial.println("退出IIC");
          break;
        }
      }
      break;

    case 'W':
      Close_Flag = 1;
      Serial.println("Wifi function testing");
      lcd.fillScreen(TFT_BLACK);
      lcd.setCursor(100, 120, 4);
      lcd.printf("WiFi testing");
      wifi_flag = 0;
      while (Close_Flag == 1)
      {
        if(Serial.available())
        {
          delay(200);
        }
        while (Serial.available() && wifi_flag == 0)
        {
          CloseData = Serial.read();
          buf[bufindex] = CloseData;
          bufindex+=1;
          if (CloseData == '\n')
          {
            buf[bufindex] = '\0';
            info[0] = buf;
            info[0] = strtok_r(info[0], "@", &info[1]);
            info[1] = strtok_r(info[1], "@", &info[2]);
            //sscanf(buf, "@%s@%s\n", wifi_account, wifi_password);
            delay(5);
            wifi_flag = 1;
          }
          if (bufindex >= 128)
          {
            bufindex = 0;
          }
        }
        if (wifi_flag == 1)
        {
          Serial.print("SSID: ");
          Serial.println(info[0]);
          
          Serial.print("Password: ");
          Serial.println(info[1]);

          WiFi.disconnect();
          delay(100);
          WiFi.begin(info[0], info[1]);
          WiFi.setAutoReconnect(true);
          delay(100);
          Serial.println("begining");
          while (WiFi.status() != WL_CONNECTED)
          {
            delay(100);
            CloseData = Serial.read();
            if (CloseData == 'I')  //Exit
            {
              memset(buf, 0, 100);
              bufindex = 0;
              break;
            }
            Serial.println("connecting");
          }
          Serial.println("WiFi is connected.");
          Serial.println("IP address: ");
          Serial.println(WiFi.localIP());
//          lcd.fillScreen(TFT_BLACK);
//          lcd.setCursor(100, 120, 4);
//          lcd.printf("Wifi is connected");
          delay(1000);
          WiFi.disconnect();
          WiFi.mode(WIFI_OFF);
          wifi_flag = 2;
          memset(buf, 0, 100);
          bufindex = 0;
          delay(2500);
          ESP.restart();
        }
        CloseData = Serial.read();
        if (CloseData == 'I')  //Exit
        {
          wifi_flag = 0;
          Close_Flag = 0;
          memset(buf, 0, 100);
          bufindex = 0;
          WiFi.disconnect();
          lcd.fillScreen(TFT_BLACK);
          Serial.println("Exit Wifi function testing");
          break;
        }
      }
      break;
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

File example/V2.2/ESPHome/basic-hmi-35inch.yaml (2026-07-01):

esphome:
  name: basic-hmi-35inch
  platformio_options:
    build_flags: "-DBOARD_HAS_PSRAM"
    board_build.esp-idf.memory_type: qio_opi
    board_build.flash_mode: dio
  friendly_name: Basic_HMI_3.5inch

esp32:
  board: esp32dev
  framework:
    type: arduino

psram:
  mode: quad
  speed: 80MHz

# Enable logging
logger:

# Enable Home Assistant API
api:
  encryption:
    key: "a/GlTK39FHKhf3WQqe0FIbrHIRQ+HRMYRQaRKIj7pIQ="

ota:
  - platform: esphome
    password: "e468a4ee6c34878f77f04e0850afb464"

wifi:
  ssid: "ThinkNode-G4_2a2d82"
  password: "elecrow.com"

  # Enable fallback hotspot (captive portal) in case wifi connection fails
  ap:
    ssid: "Basic-Hmi-35Inch"
    password: "S8EOSGdtn8ZT"

captive_portal:

# ----- GPIO25 LED Switch -----
switch:
  - platform: gpio                 # Use GPIO switch platform
    pin: GPIO25                    # LED connected to GPIO25
    id: led_switch                 # Internal ID
    name: "External LED"           # Display name in ESPHome
    restore_mode: RESTORE_DEFAULT_OFF  # Restore to OFF after reboot

# ----- PWM Output (Backlight) -----
output:
  - platform: ledc                 # Use ESP32 LEDC PWM output
    pin: GPIO27                    # Backlight PWM output pin
    inverted: False                # Normal output (not inverted)
    id: backlight_pwm              # PWM output ID

# ----- Display Backlight -----
light:
  - platform: monochromatic        # Monochrome light component
    output: backlight_pwm          # Bind to PWM output
    name: "Display Backlight"      # Display name
    id: back_light                 # Internal ID
    restore_mode: ALWAYS_ON        # Turn on automatically after reboot

# ----- Fonts -----
font:
  - file: "gfonts://Roboto"        # Google Roboto font
    id: font4                      # Font ID
    size: 48                       # Font size
  - file: "gfonts://Roboto"
    id: font3
    size: 36
  - file: "gfonts://Roboto"
    id: font2
    size: 24
  - file: "gfonts://Roboto"
    id: font1
    size: 12

# ----- I2C Bus (DHT20) -----
i2c:
  sda: GPIO22                      # SDA pin
  scl: GPIO21                      # SCL pin
  scan: true                       # Scan for I2C devices during boot

# ----- Sensor -----
sensor:
  - platform: aht10                # Use AHT10/AHT20 platform
    variant: AHT20                 # Specify AHT20 sensor
    address: 0x38                  # I2C address
    temperature:
      name: "HMI-35 Temperature"   # Temperature sensor name
      id: temperature35            # Temperature sensor ID
    humidity:
      name: "HMI-35 Humidity"      # Humidity sensor name
      id: humidity35               # Humidity sensor ID
    update_interval: 5s            # Update every 5 seconds

# ----- SPI Bus (Shared by Display and Touchscreen) -----
spi:
  - id: spi_bus                    # SPI bus ID
    clk_pin: GPIO14                # SPI clock pin
    mosi_pin: GPIO13               # SPI MOSI pin
    miso_pin: GPIO33               # SPI MISO pin
    interface: hardware            # Use hardware SPI

# ----- Touchscreen (XPT2046) -----
touchscreen:
  platform: xpt2046                # XPT2046 touch controller
  id: my_touch                     # Touchscreen ID
  spi_id: spi_bus                  # Use shared SPI bus
  cs_pin: GPIO12                   # Chip Select pin (modify according to your wiring)
  #interrupt_pin: GPIO36           # Optional T_IRQ pin for faster response
  update_interval: 50ms            # Touch scan interval
  threshold: 400                   # Touch pressure threshold
  calibration:                     # Touch calibration parameters
    x_min: 280                     # Raw X minimum
    x_max: 3860                    # Raw X maximum
    y_min: 340                     # Raw Y minimum
    y_max: 3860                    # Raw Y maximum
  transform:                       # Coordinate transformation
    mirror_x: true                 # Mirror X-axis
    mirror_y: false                # Do not mirror Y-axis
    swap_xy: false                 # Do not swap X and Y axes
  on_touch:                        # Trigger when screen is touched
    - lambda: |-
        ESP_LOGI("touch", "x=%d, y=%d, x_raw=%d, y_raw=%d",
            touch.x,
            touch.y,
            touch.x_raw,
            touch.y_raw);
    - if:
        condition:
          and:
            - lambda: 'return (touch.x >= 280 && touch.x <= 310);'   # X coordinate range
            - lambda: 'return (touch.y >= 235 && touch.y <= 265);'   # Y coordinate range
        then:
          - switch.toggle: led_switch    # Toggle LED switch
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

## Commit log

2026-07-29 Update code 2026-07-29 09:40
    [Configuring options.txt, code-format.cfg]
2026-07-29 更新代码 2026-07-29 10:56

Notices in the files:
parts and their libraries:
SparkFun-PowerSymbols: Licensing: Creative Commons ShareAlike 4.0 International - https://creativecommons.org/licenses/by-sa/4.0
